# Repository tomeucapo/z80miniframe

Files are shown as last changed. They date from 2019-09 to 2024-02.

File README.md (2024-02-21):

# Z80MiniFrame
Core firmware source code and schematics from Z80MiniFrame hardware. This is a Z80 based microcomputer based system.

## Features

### Hardware 

* 32KBytes EEPROM for Firmware routines and Z80 MS-BASIC
* 32KBytes RAM
* VDP TMS9918
* PSG AY-3-8910
* USB-Serial Console Interface
 


### Software

* Extend BASIC instructions to support VDP capabilities like: COLOR, SCREEN or LOCATE instructions.
* Created RST $20 routine service to call firmware routines like VDP routines.

## Required tools
This project uses ZMAC Z80 Macro assembler and LD80 Linker from http://48k.ca/zmac.html. And finally needs make or nmake or Make to build project.

## Build software
```
nmake all
```

This produces firmware.hex into bin directory and this file can burn into 32KBytes EEPROM like AT28C256.

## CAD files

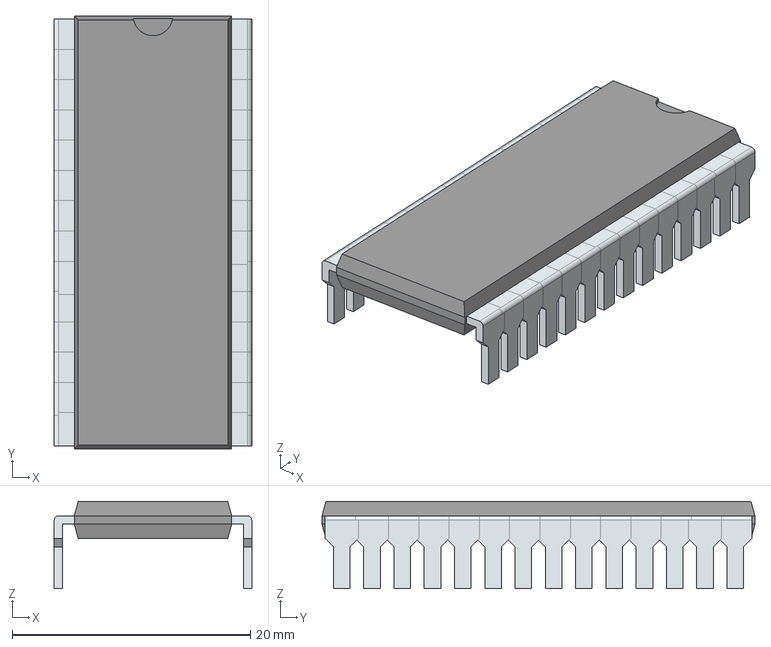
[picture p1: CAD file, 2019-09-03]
schematics/AS6C62256-55PCN/3D/AS6C62256-55PCN.stp
16.6 x 36.3 x 7.31 mm
PinsArrayLR

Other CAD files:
schematics/AS6C62256-55PCN/3D/AS6C62256-55PCN.stl
schematics/AS6C62256-55PCN/Allegro/dip1587w140p254l3632h381q28n.psm
schematics/AS6C62256-55PCN/DEHDL/as6c62256_55pcn/chips/chips.prt

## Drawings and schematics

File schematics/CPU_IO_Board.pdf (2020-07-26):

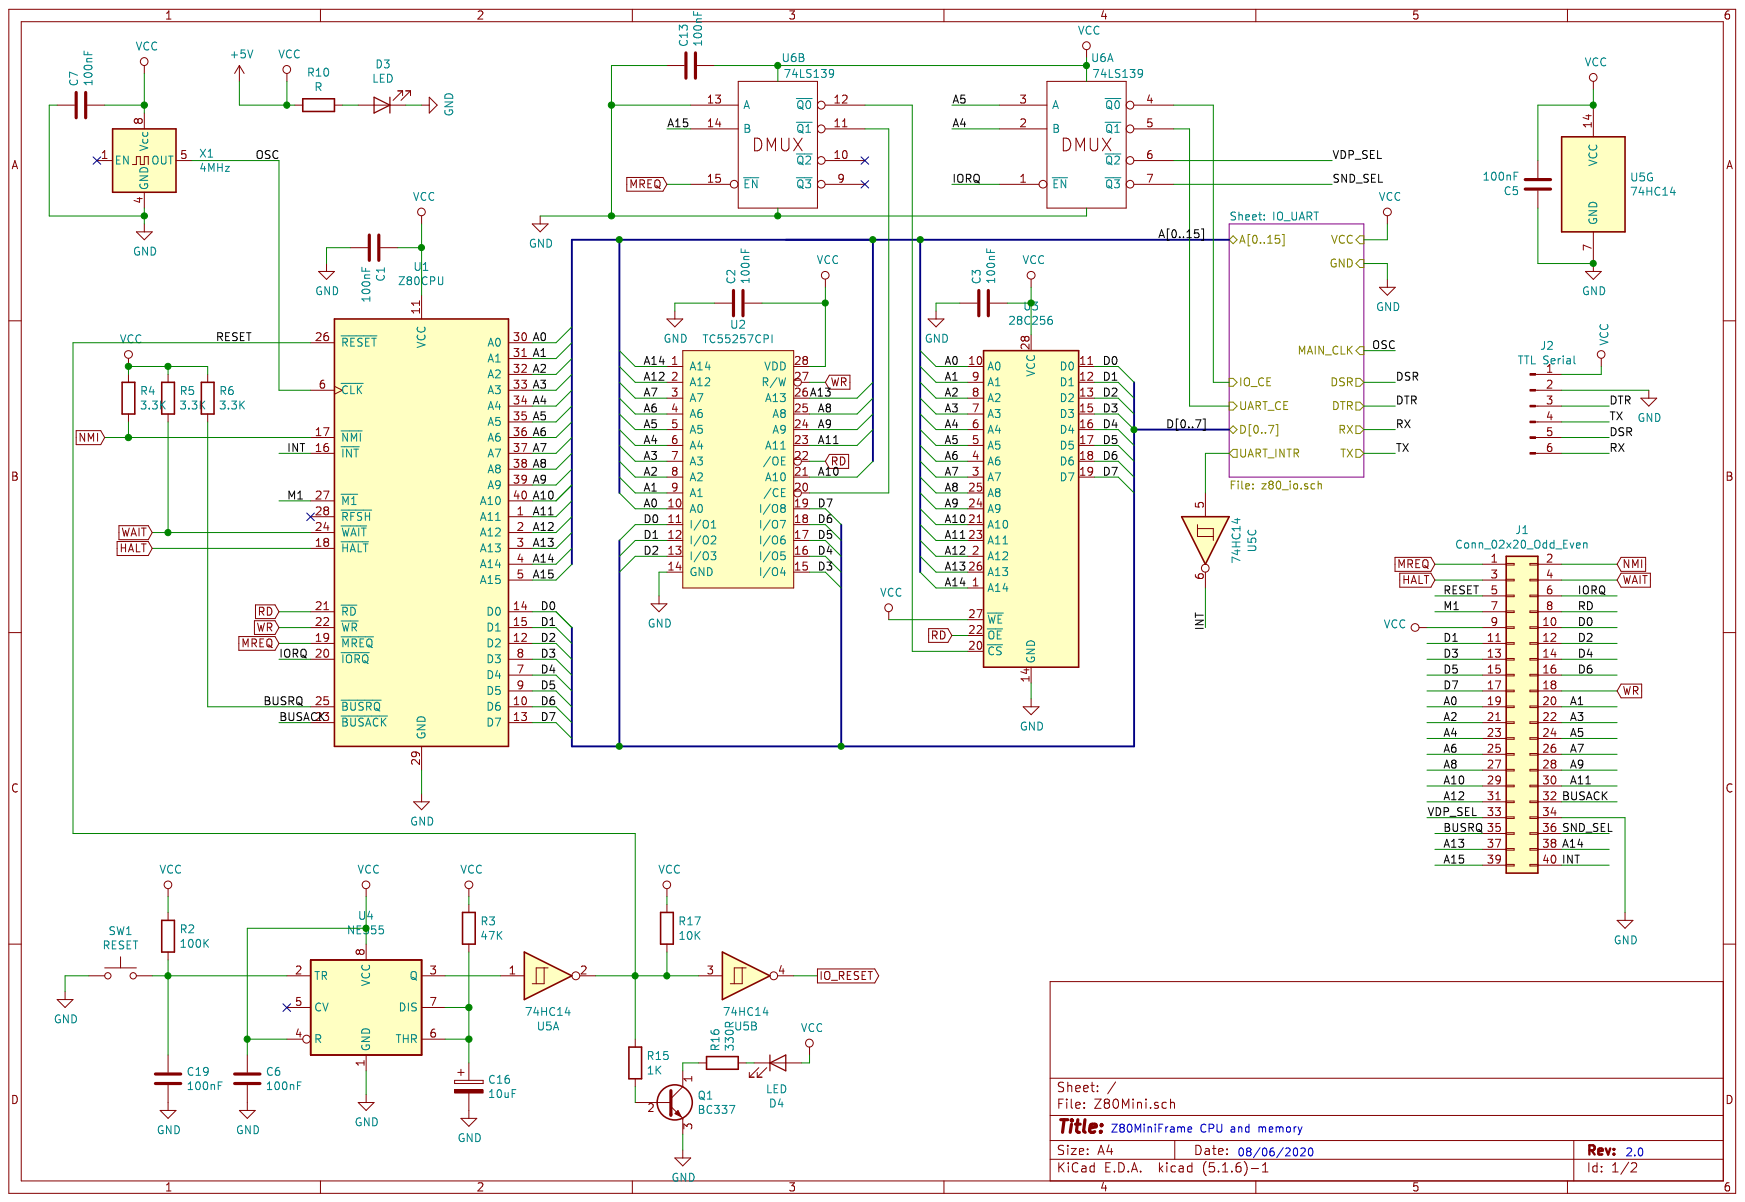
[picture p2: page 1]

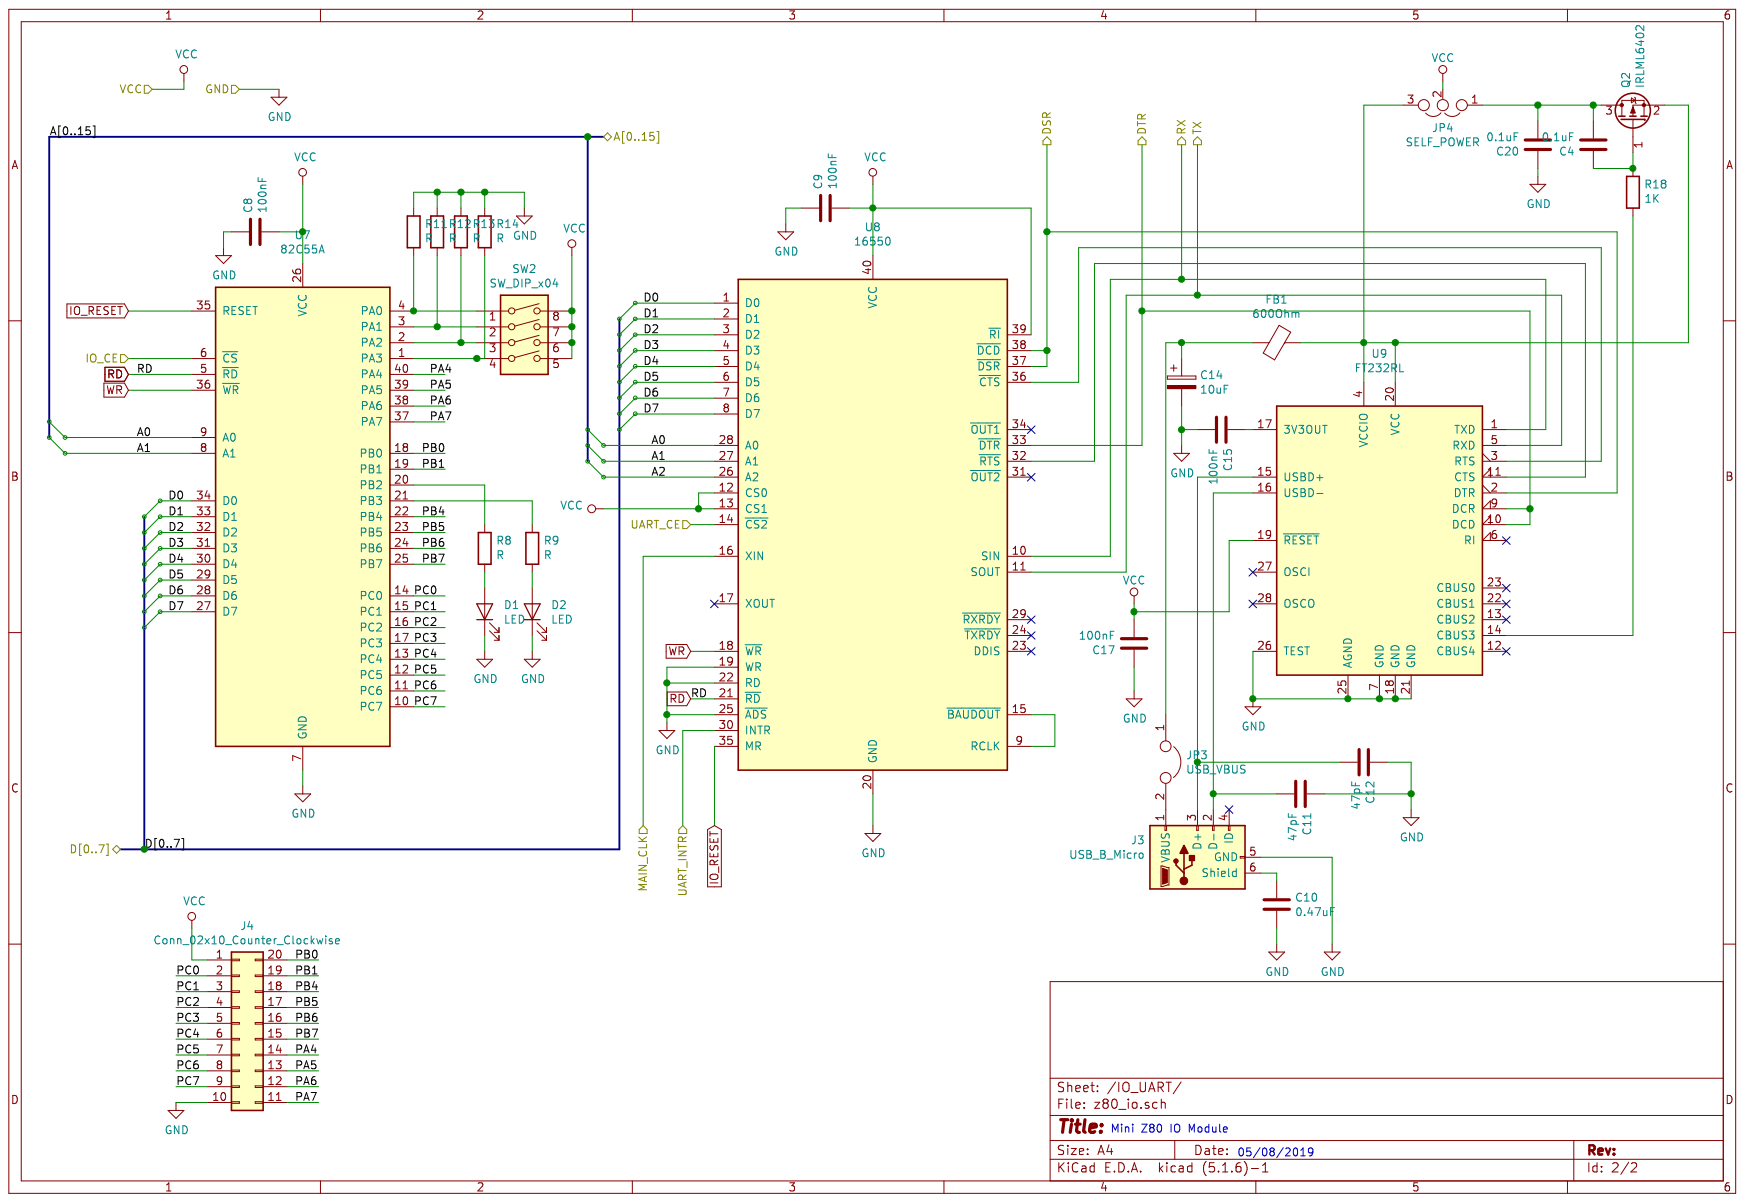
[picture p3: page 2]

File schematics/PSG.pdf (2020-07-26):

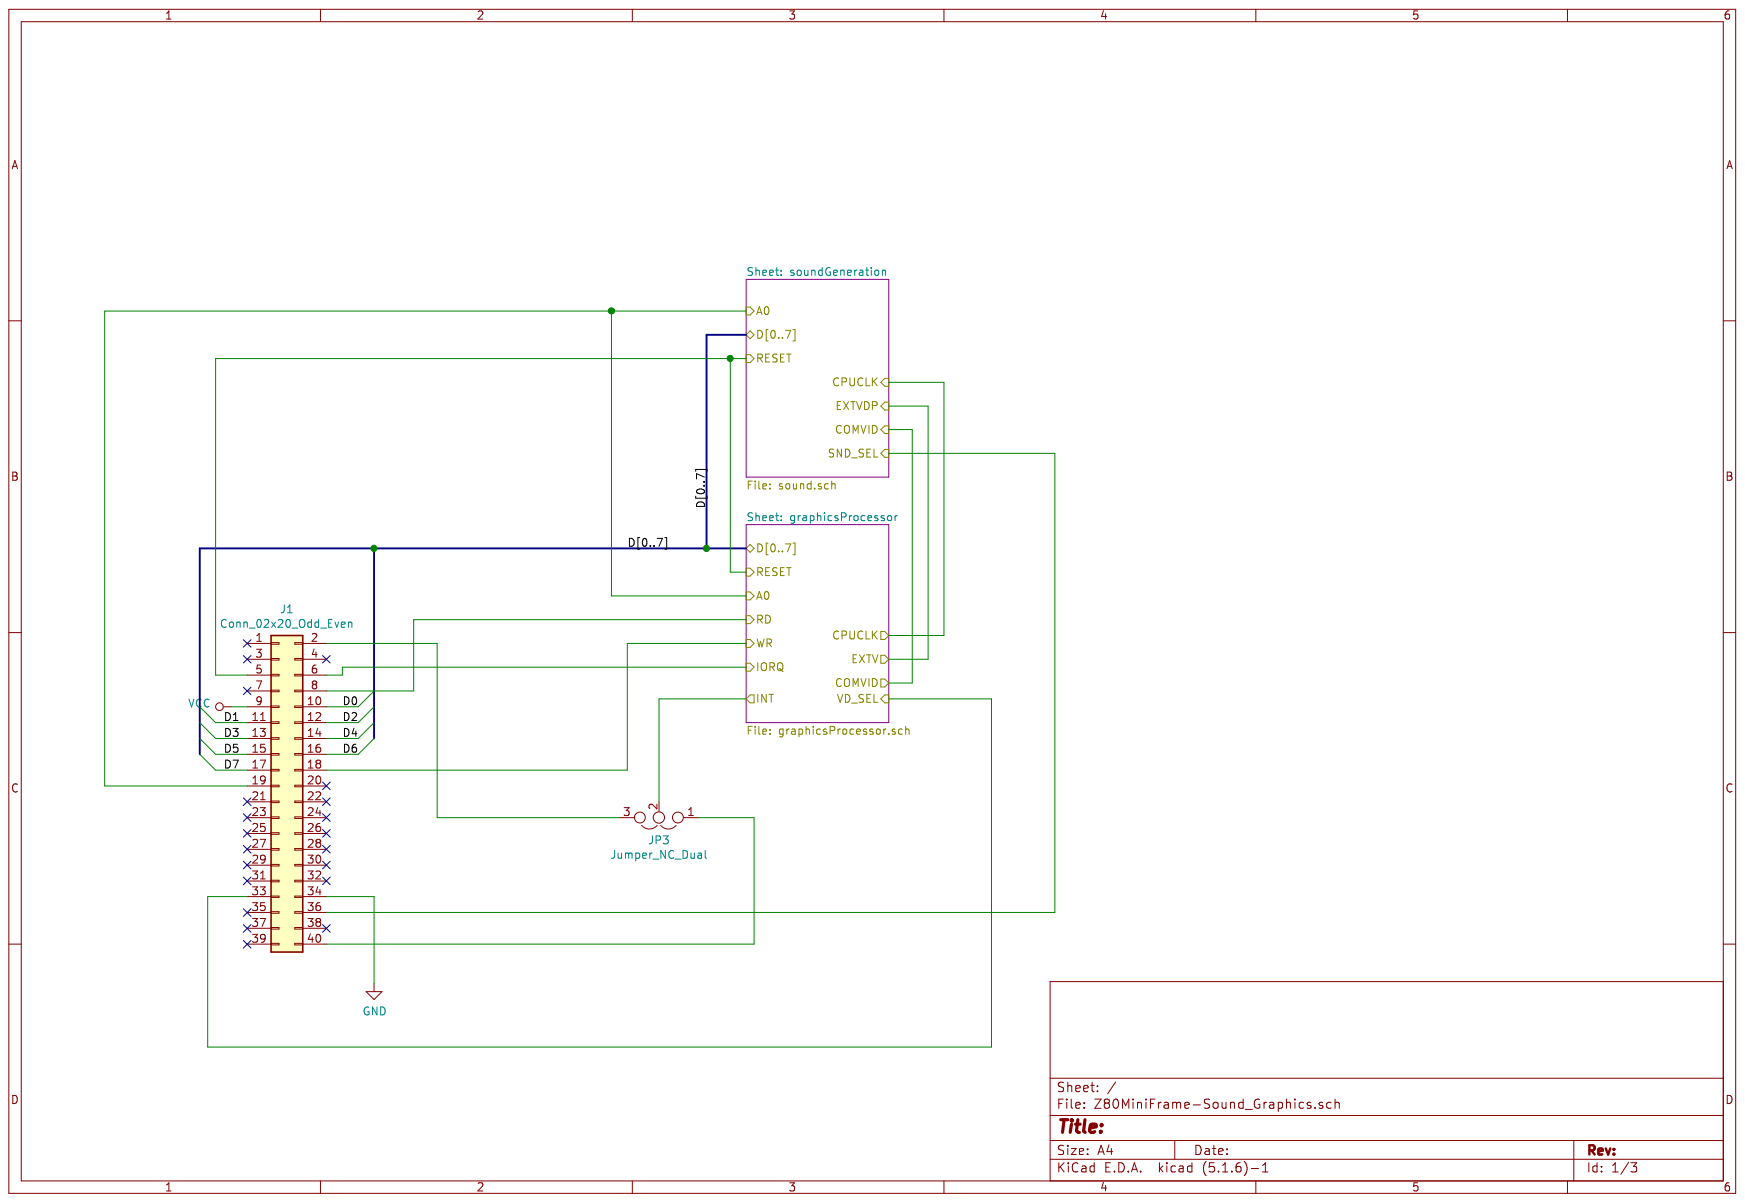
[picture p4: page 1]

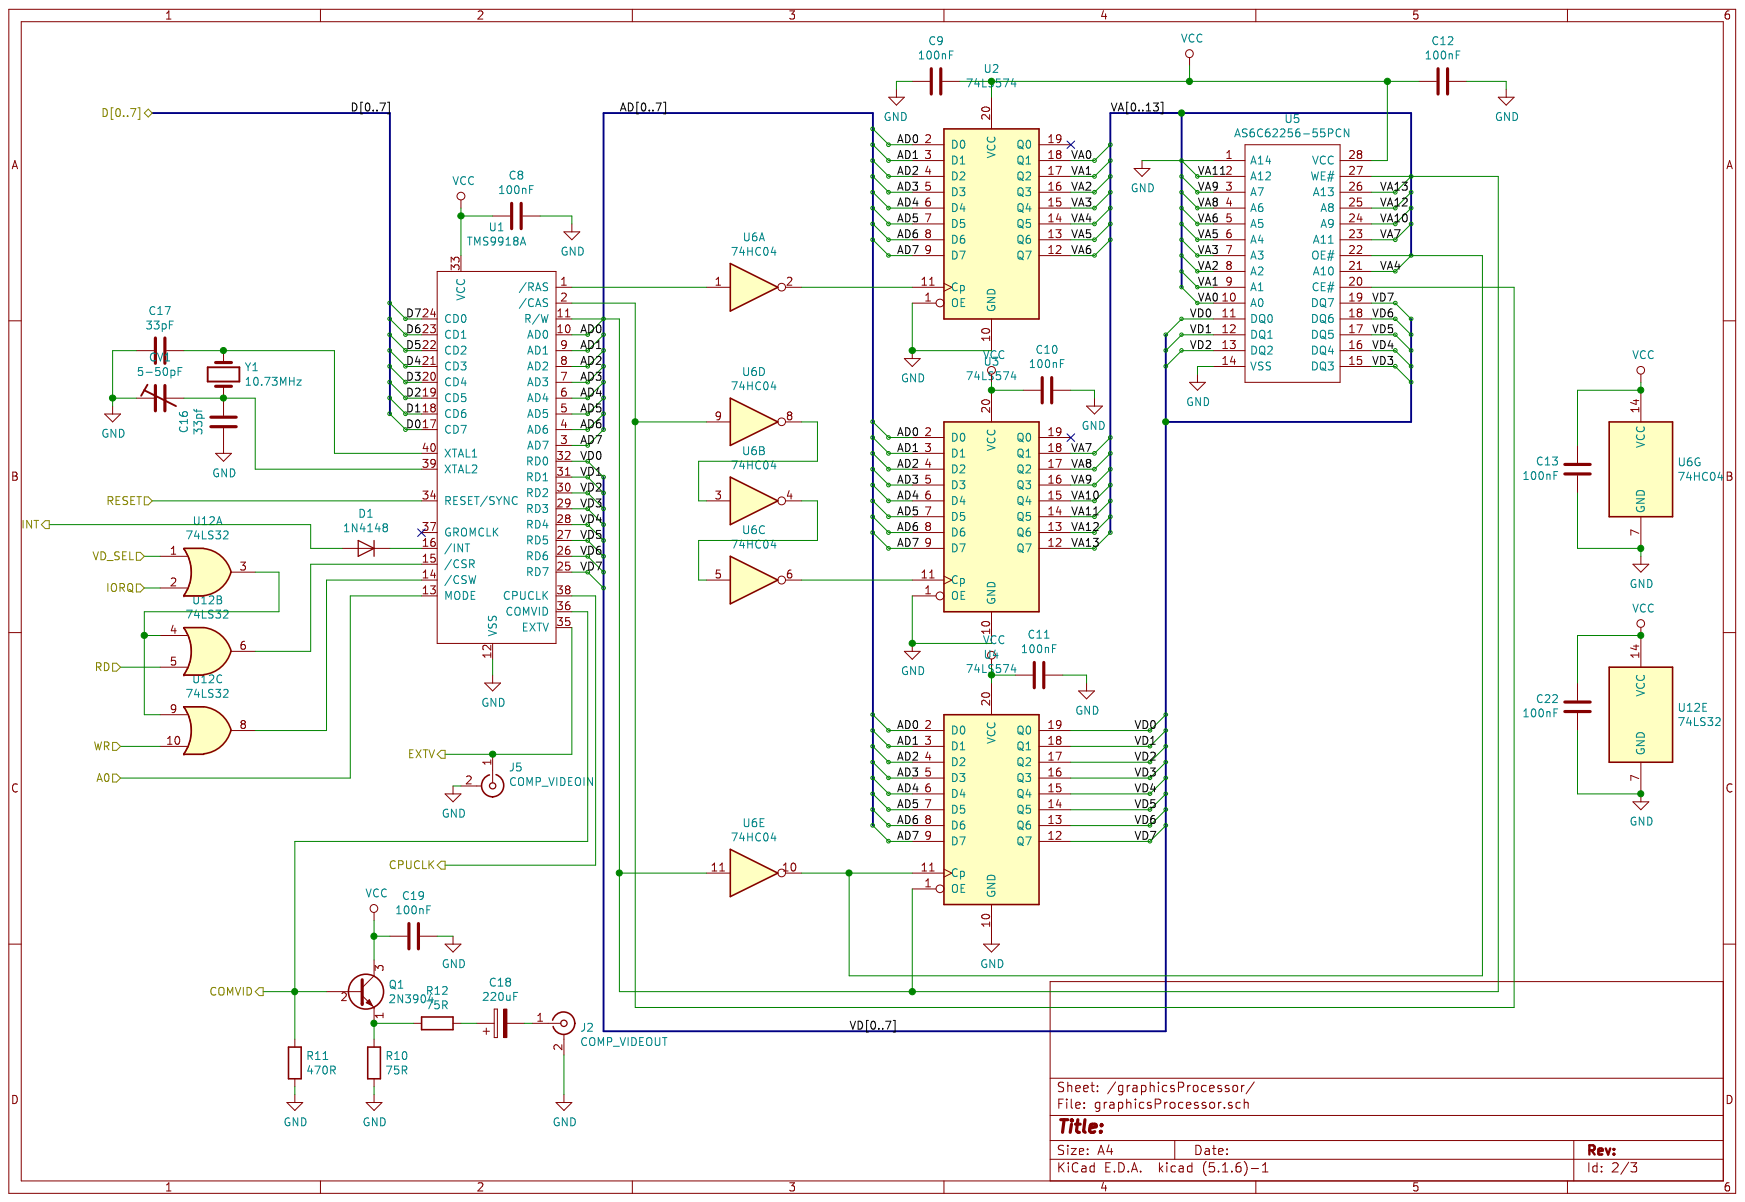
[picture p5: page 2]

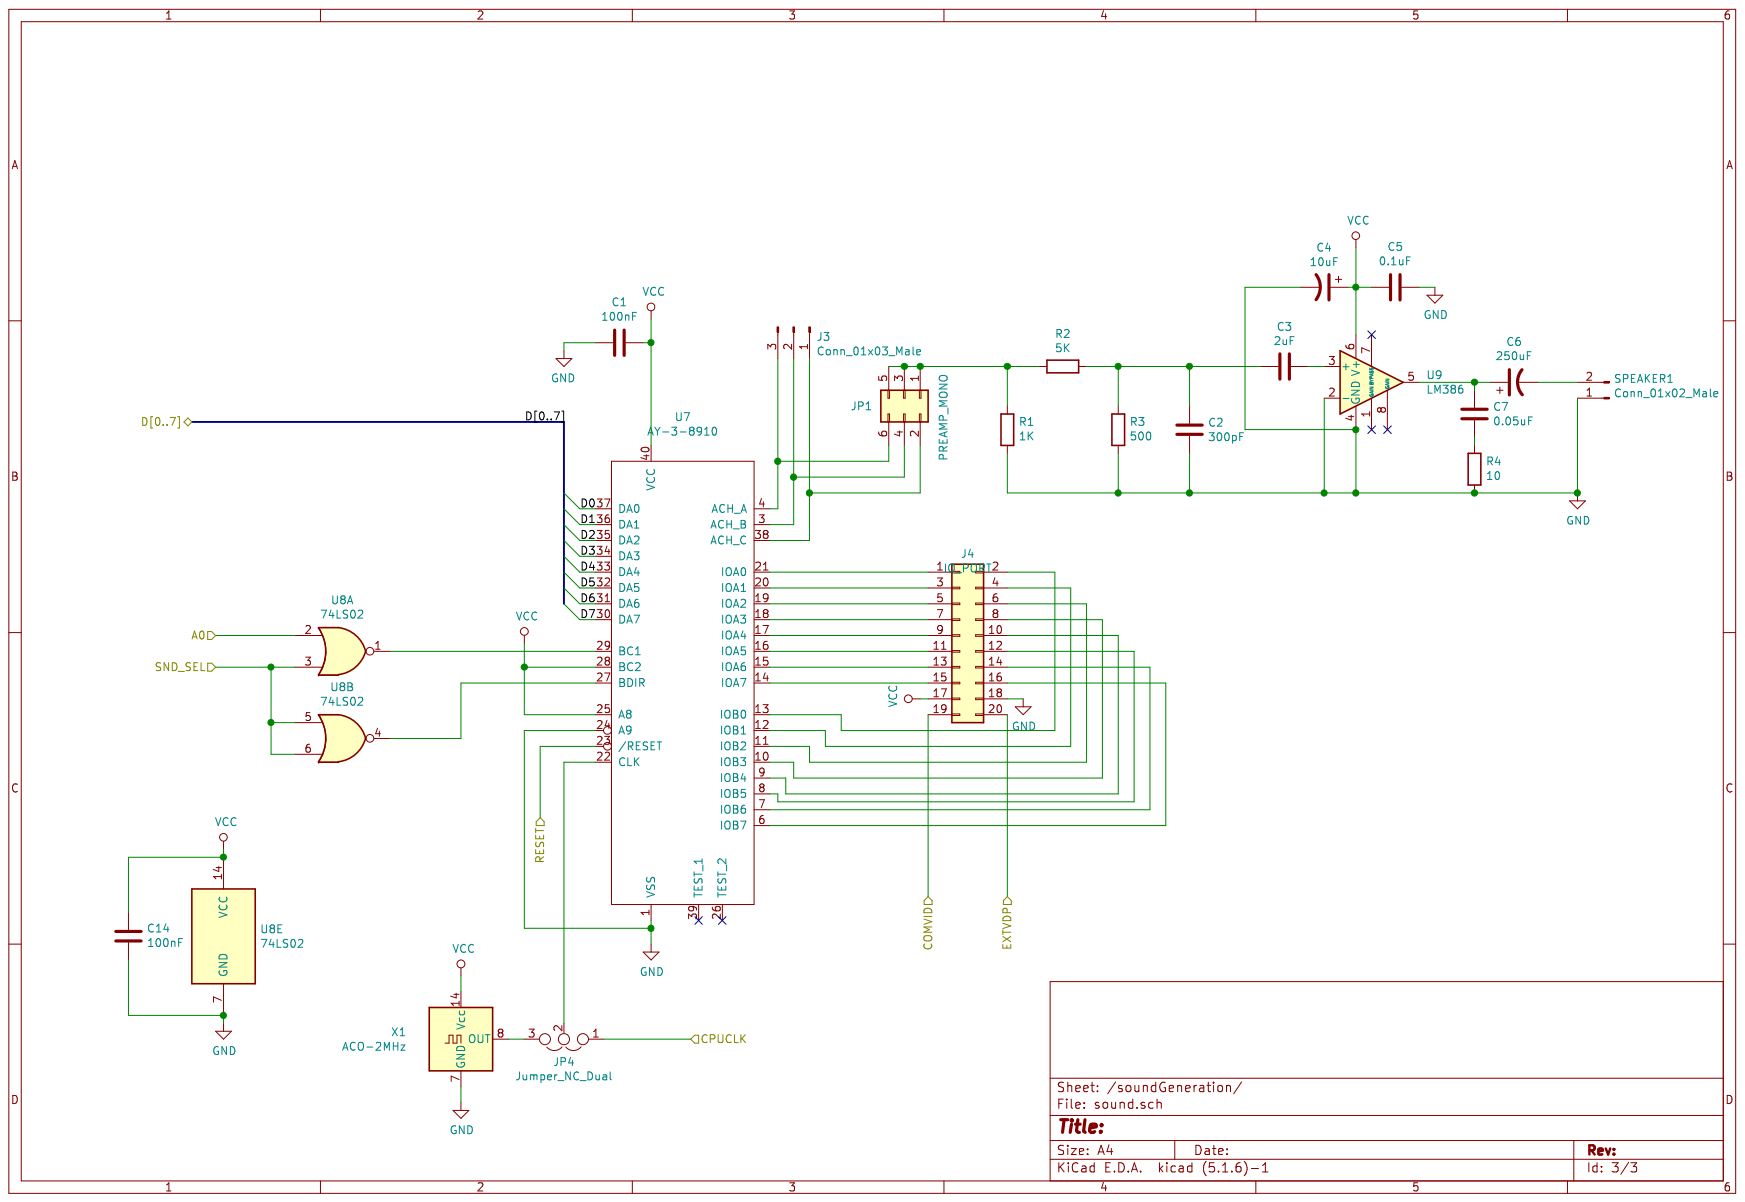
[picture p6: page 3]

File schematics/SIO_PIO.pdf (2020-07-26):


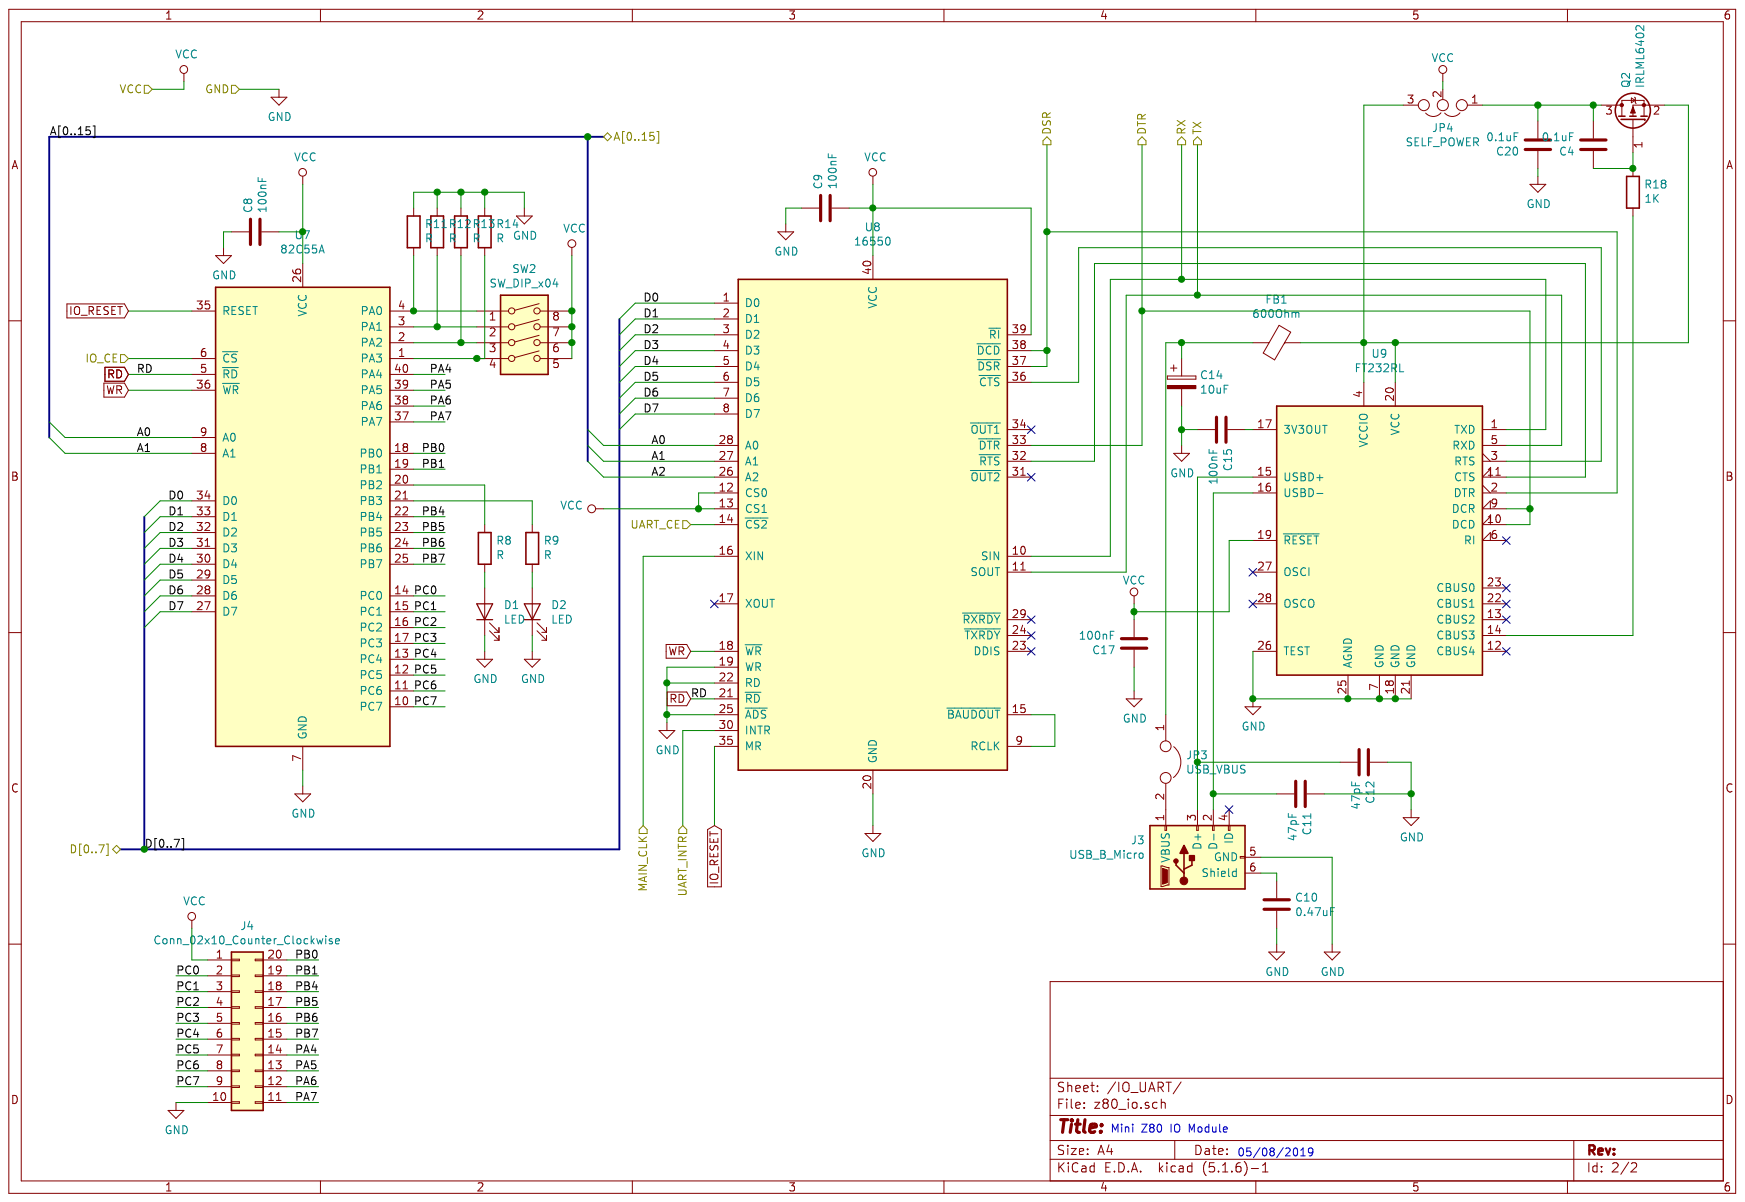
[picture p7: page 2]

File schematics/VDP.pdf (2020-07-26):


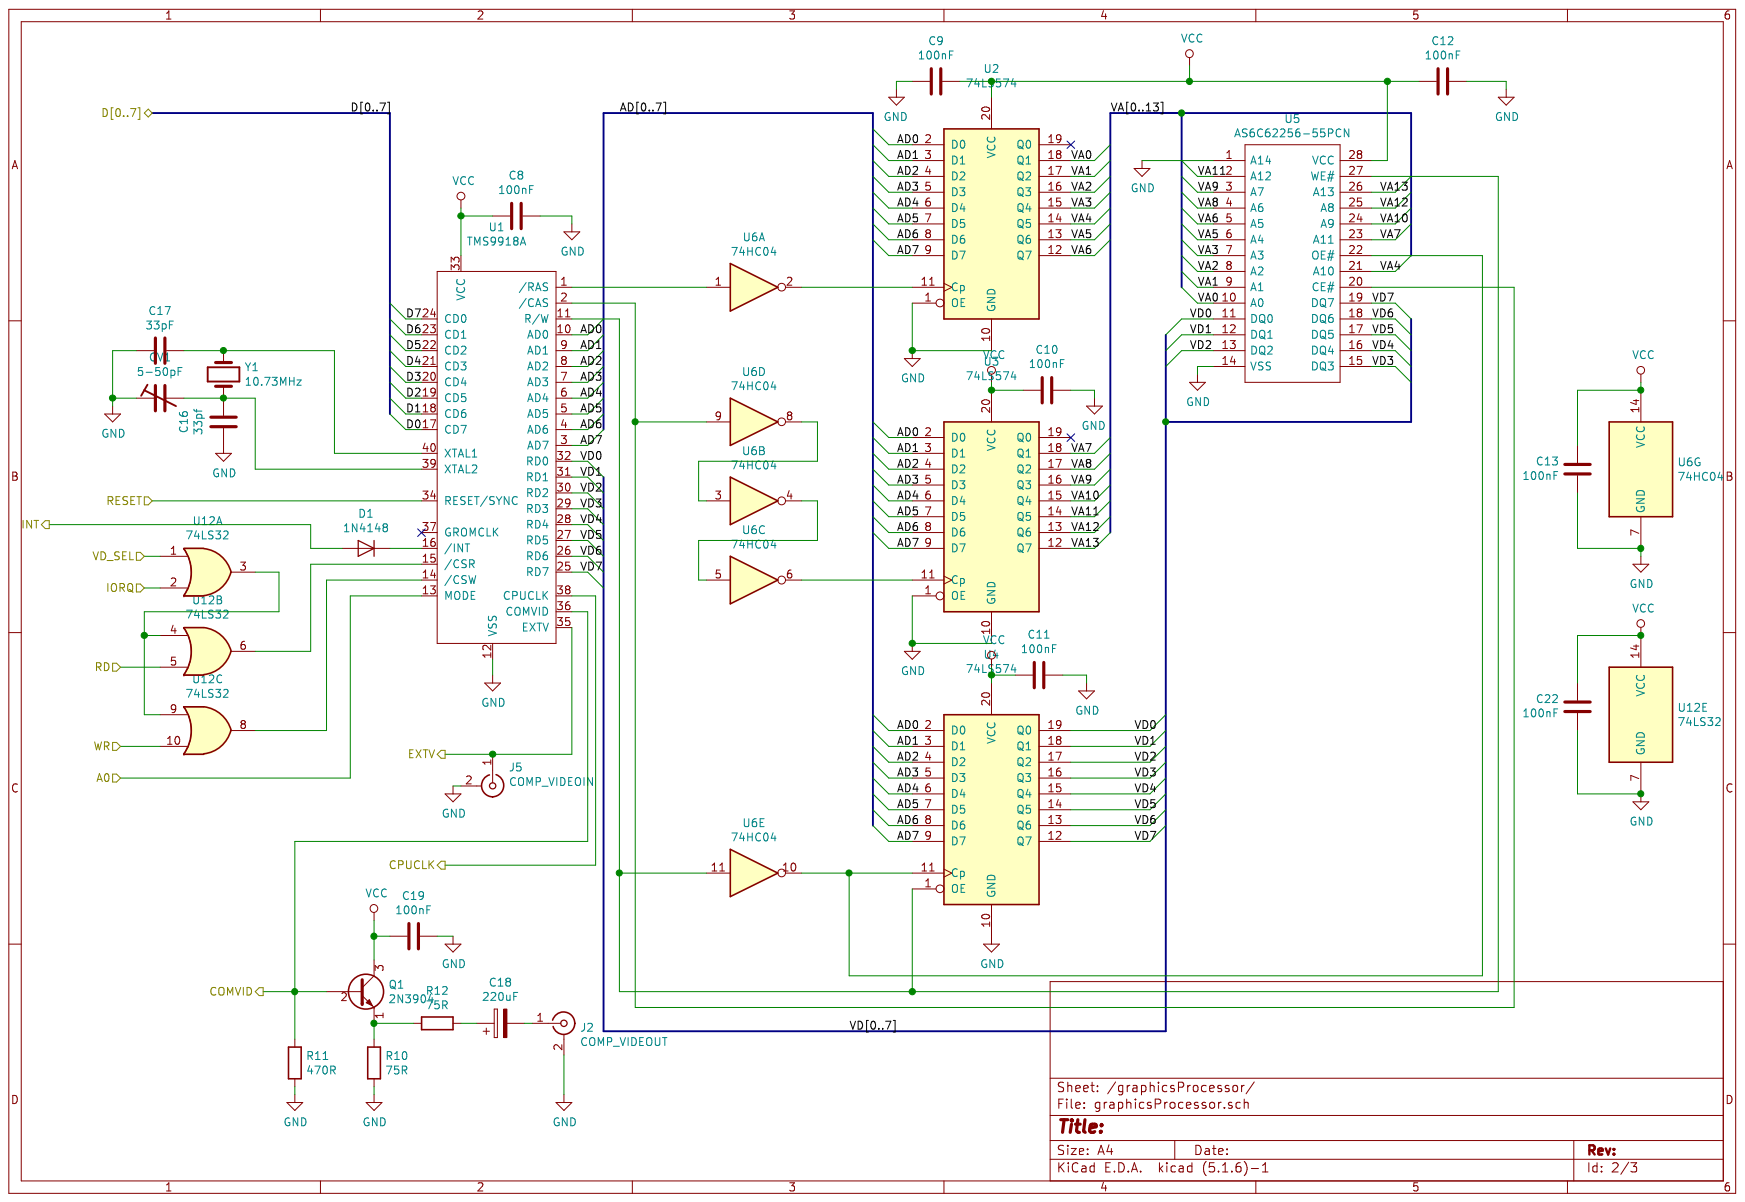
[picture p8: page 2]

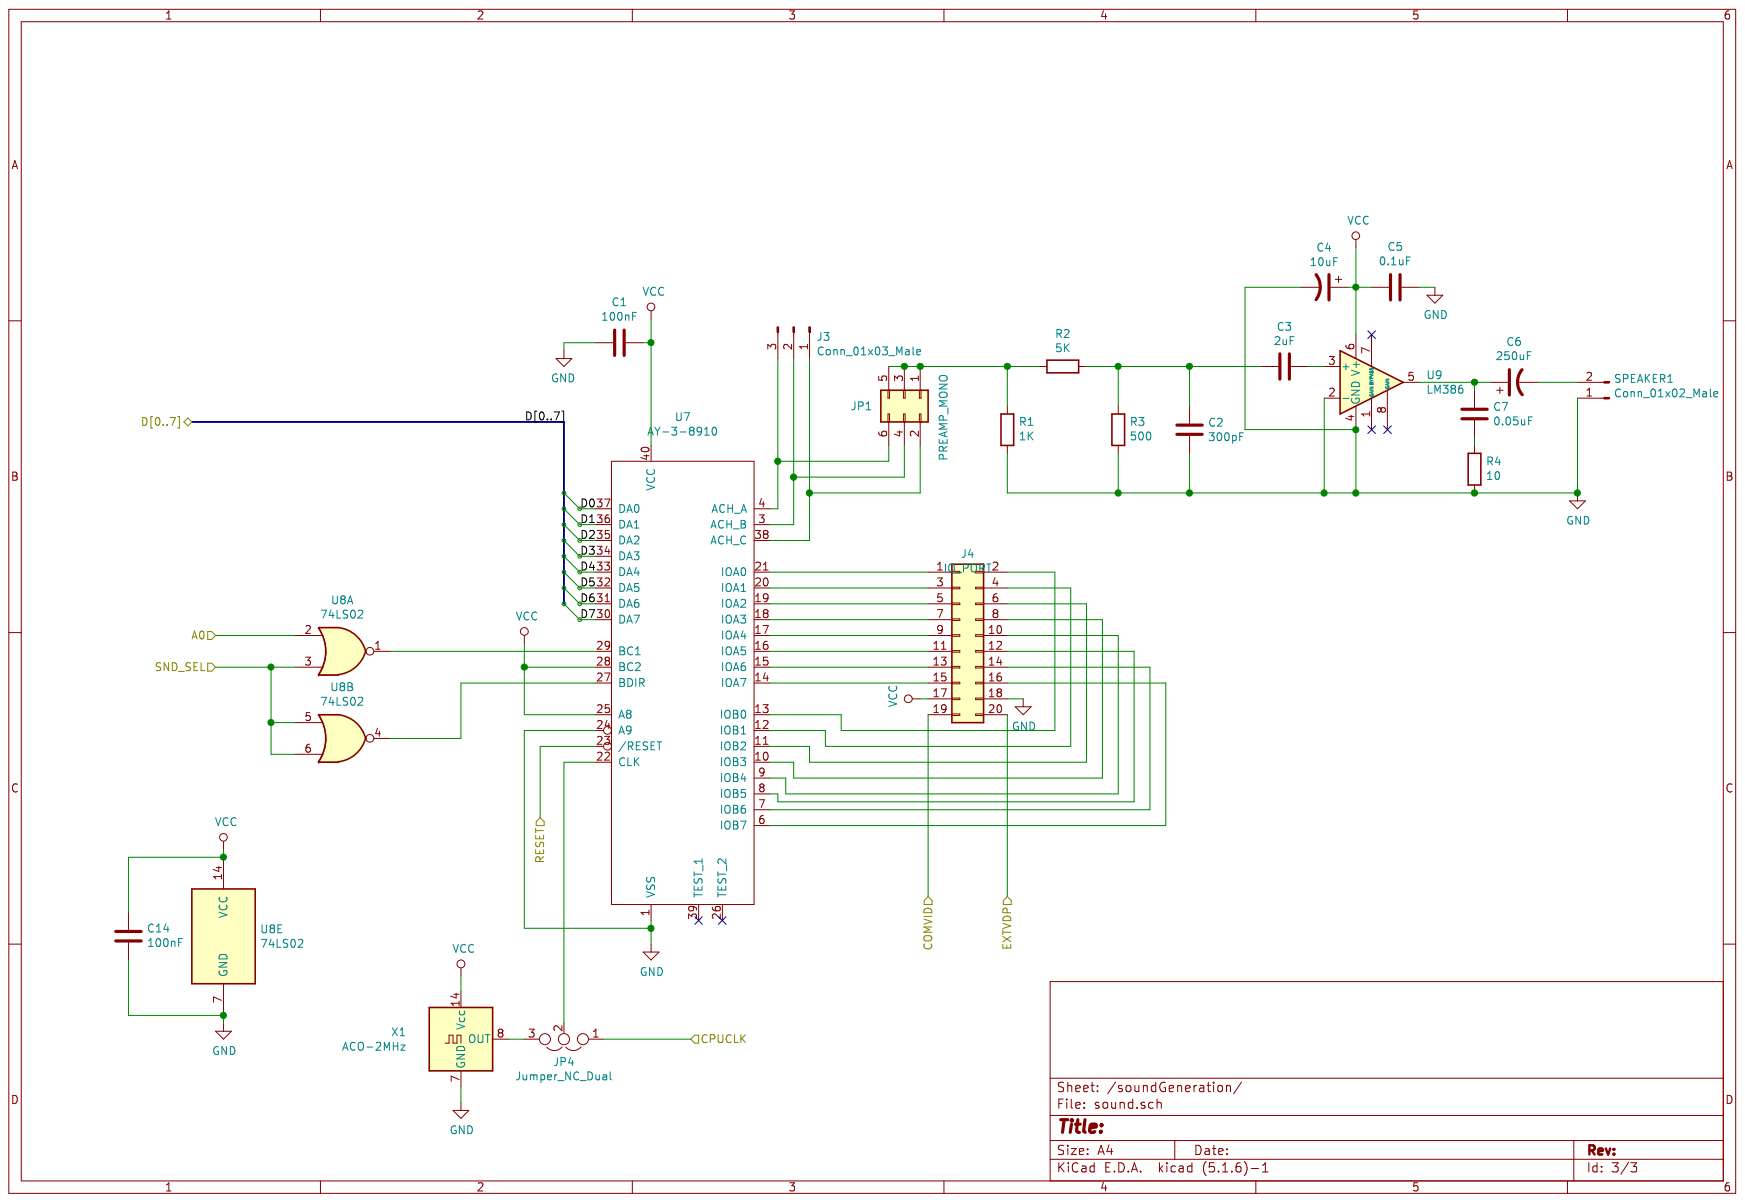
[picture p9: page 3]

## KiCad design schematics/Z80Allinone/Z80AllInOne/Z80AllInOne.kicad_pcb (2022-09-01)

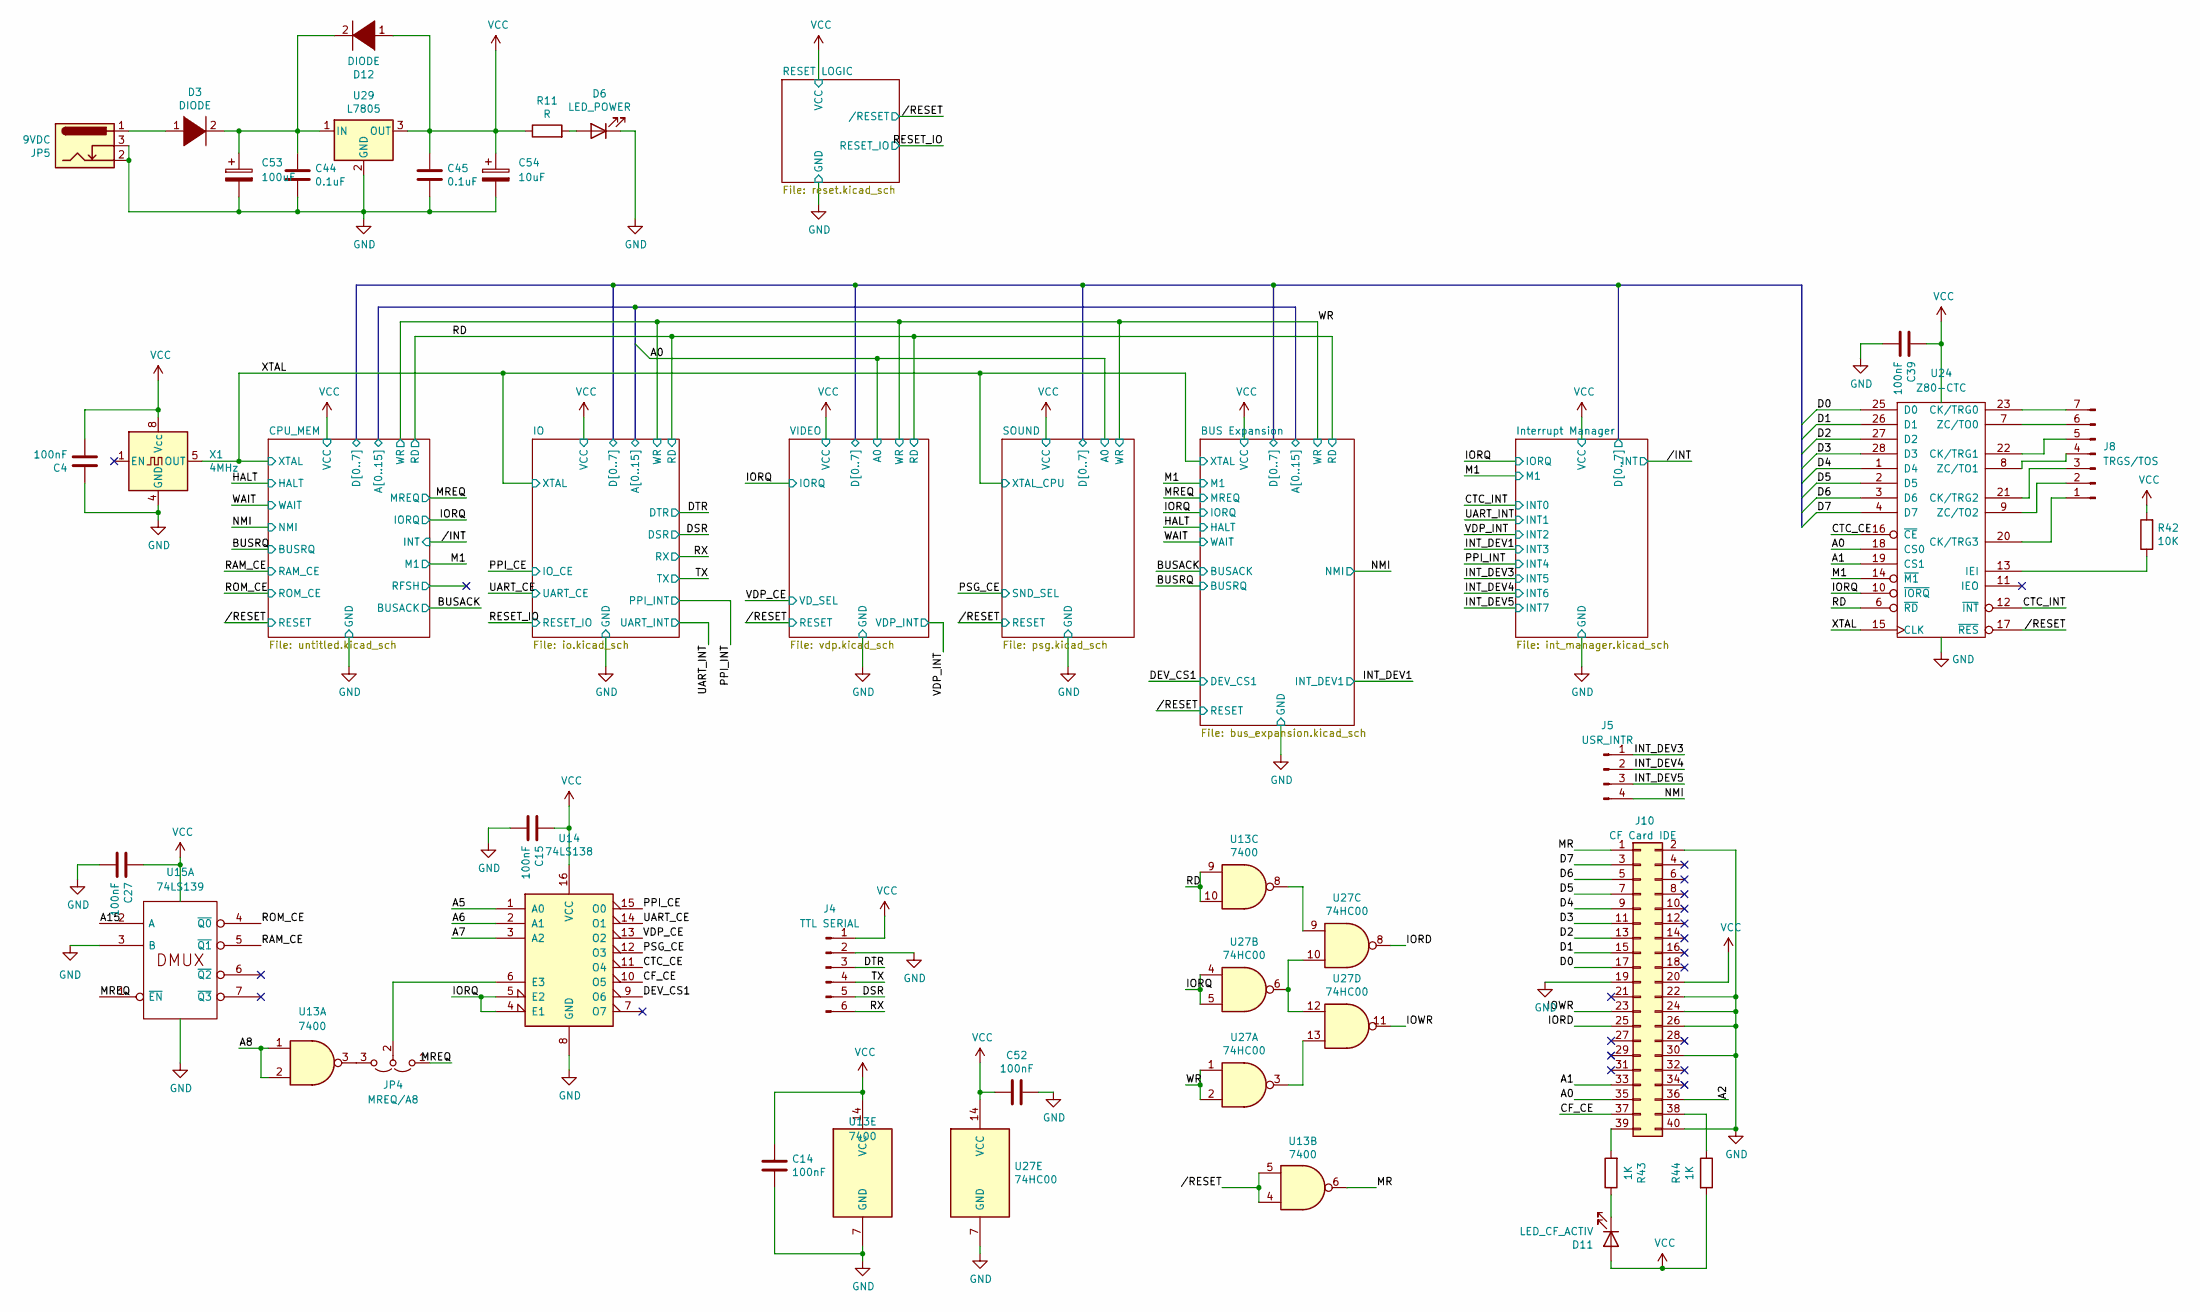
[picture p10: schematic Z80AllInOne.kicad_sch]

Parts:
C4, C14, C15, C27, C39, C52: 100nF; C_Disc_D7.0mm_W2.5mm_P5.00mm
C44, C45: 0.1uF; C_Radial_D6.3mm_H5.0mm_P2.50mm
C53: 100uF; CP_Radial_D8.0mm_P3.80mm
C54: 10uF; CP_Radial_D8.0mm_P3.80mm
D3, D12: DIODE; D_A-405_P7.62mm_Horizontal
D6: LED_POWER; LED_D3.0mm
D11: LED_CF_ACTIV; LED_D3.0mm
J4: TTL SERIAL; PinHeader_1x06_P2.54mm_Vertical
J5: USR_INTR; PinHeader_1x04_P2.54mm_Vertical
J8: TRGS/TOS; PinHeader_1x07_P2.54mm_Vertical
J10: CF Card IDE; IDC-Header_2x20_P2.54mm_Vertical
JP4: MREQ/A8; PinHeader_1x03_P2.54mm_Vertical
JP5: 9VDC; BarrelJack_Wuerth_6941xx301002
R11: R; R_Axial_DIN0207_L6.3mm_D2.5mm_P10.16mm_Horizontal
R42: 10K; R_Axial_DIN0207_L6.3mm_D2.5mm_P10.16mm_Horizontal
R43, R44: 1K; R_Axial_DIN0207_L6.3mm_D2.5mm_P10.16mm_Horizontal
U13: 7400; DIP-14_W7.62mm_LongPads
U14: 74LS138; DIP-16_W7.62mm_LongPads
U15: 74LS139; DIP-16_W7.62mm_Socket
U24: Z80-CTC; DIP-28_W15.24mm_LongPads
U27: 74HC00; DIP-14_W7.62mm
U29: L7805; TO-220-3_Horizontal_TabDown
X1: 4MHz; Oscillator_DIP-8

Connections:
/BUS Expansion/D0: J10.17, U24.25 (D0); also elsewhere on the board
/BUS Expansion/D1: J10.15, U24.26 (D1); also elsewhere on the board
/BUS Expansion/D2: J10.13, U24.27 (D2); also elsewhere on the board
/BUS Expansion/D3: J10.11, U24.28 (D3); also elsewhere on the board
/BUS Expansion/D4: J10.9, U24.1 (D4); also elsewhere on the board
/BUS Expansion/D5: J10.7, U24.2 (D5); also elsewhere on the board
/BUS Expansion/D6: J10.5, U24.3 (D6); also elsewhere on the board
/BUS Expansion/D7: J10.3, U24.4 (D7); also elsewhere on the board
/CF_CE: J10.37, U14.10 (O5)
/CTC_CE: U14.11 (O4), U24.16 (~CE)
/CTC_INT: U24.12 (~INT); also elsewhere on the board
/DEV_CS1: U14.9 (O6); also elsewhere on the board
/DSR: J4.5; also elsewhere on the board
/DTR: J4.3; also elsewhere on the board
/INT_DEV3: J5.1; also elsewhere on the board
/INT_DEV4: J5.2; also elsewhere on the board
/INT_DEV5: J5.3; also elsewhere on the board
/IO/A0: J10.35, U24.18 (CS0); also elsewhere on the board
/IO/A1: J10.33, U24.19 (CS1); also elsewhere on the board
/IO/A2: J10.36; also elsewhere on the board
/IO/A5: U14.1 (A0); also elsewhere on the board
/IO/A6: U14.2 (A1); also elsewhere on the board
/IO/A7: U14.3 (A2); also elsewhere on the board
/IO/A8: U13.1, U13.2; also elsewhere on the board
/IO/A15: U15.2 (A); also elsewhere on the board
/IORD: J10.25, U27.8
/IORQ: U14.4 (E1), U14.5 (E2), U24.10 (~IORQ), U27.4, U27.5; also elsewhere on the board
/IOWR: J10.23, U27.11
/M1: U24.14 (~M1); also elsewhere on the board
/MR: J10.1, U13.6
/MREQ: JP4.1 (A), U15.1 (~EN); also elsewhere on the board
/NMI: J5.4; also elsewhere on the board
/PPI_CE: U14.15 (O0); also elsewhere on the board
/PSG_CE: U14.12 (O3); also elsewhere on the board
/RAM_CE: U15.5 (~Q1); also elsewhere on the board
/RD: U13.9, U13.10, U24.6 (~RD); also elsewhere on the board
/ROM_CE: U15.4 (~Q0); also elsewhere on the board
/RX: J4.6; also elsewhere on the board
/TX: J4.4; also elsewhere on the board
/UART_CE: U14.14 (O1); also elsewhere on the board
/VDP_CE: U14.13 (O2); also elsewhere on the board
/WR: U27.1, U27.2; also elsewhere on the board
/XTAL: U24.15 (CLK), X1.5 (OUT); also elsewhere on the board
//RESET: U13.4, U13.5, U24.17 (~RES); also elsewhere on the board
GND: C4.1, C14.2, C15.2, C27.2, C39.2, C44.2, C45.2, C52.1, C53.2, C54.2, D6.1 (K), J4.2, J10.2, J10.19, J10.22, J10.24, J10.26, J10.30, J10.40, JP5.2, JP5.3, U13.7 (GND), U14.8 (GND), U15.3 (B), U15.8 (GND), U24.5 (GND), U27.7 (GND), U29.2 (GND), X1.4 (GND); also elsewhere on the board
unnamed: C44.1, C53.1, D3.2 (A), D12.2 (A), U29.1 (IN)
unnamed: D3.1 (K), JP5.1
unnamed: D6.2 (A), R11.2
unnamed: D11.1 (K), R43.1
unnamed: J8.1, U24.20 (CK/TRG3)
unnamed: J8.2, U24.9 (ZC/TO2)
unnamed: J8.3, U24.21 (CK/TRG2)
unnamed: J8.4, U24.8 (ZC/TO1)
unnamed: J8.5, U24.22 (CK/TRG1)
unnamed: J8.6, U24.7 (ZC/TO0)
unnamed: J8.7, U24.23 (CK/TRG0)
unnamed: J10.38, R44.1
unnamed: J10.39, R43.2
unnamed: JP4.2 (C), U14.6 (E3)
unnamed: JP4.3 (B), U13.3
unnamed: R42.1, U24.13 (IEI)
unnamed: U13.8, U27.9
unnamed: U27.6, U27.10, U27.12
unnamed: U27.3, U27.13
VCC: C4.2, C14.1, C15.1, C27.1, C39.1, C45.1, C52.2, C54.1, D11.2 (A), D12.1 (K), J4.1, J10.20, R11.1, R42.2, R44.2, U13.14 (VCC), U14.16 (VCC), U15.16 (VCC), U24.24 (VDD), U27.14 (VCC), U29.3 (OUT), X1.8 (Vcc); also elsewhere on the board

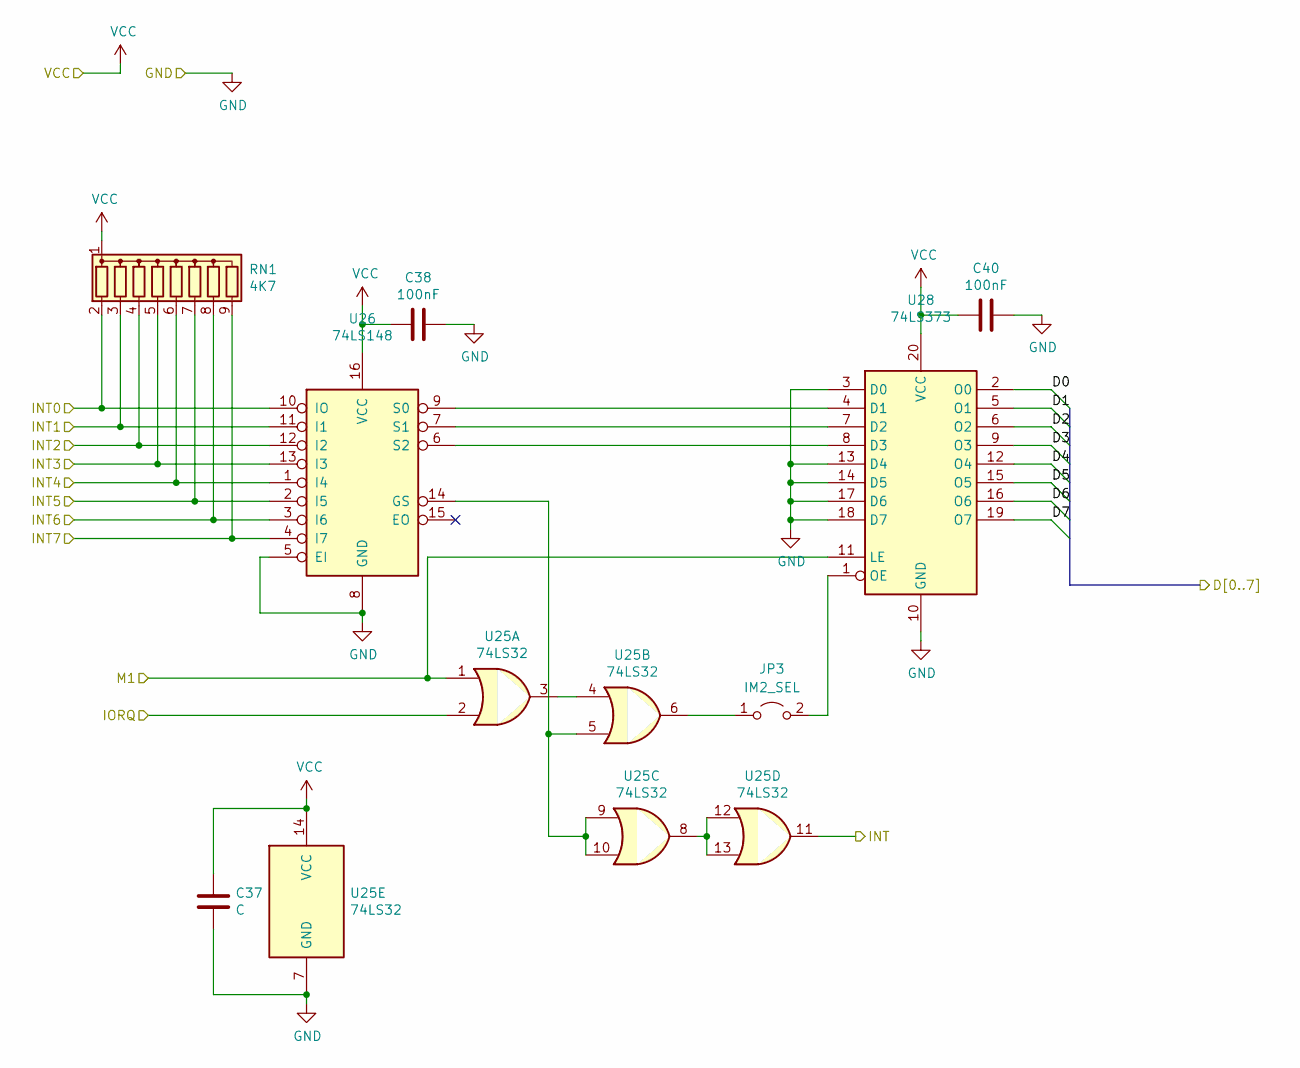
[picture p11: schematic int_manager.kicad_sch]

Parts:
C37: C; C_Disc_D7.0mm_W2.5mm_P5.00mm
C38, C40: 100nF; C_Disc_D7.0mm_W2.5mm_P5.00mm
JP3: IM2_SEL; PinHeader_1x02_P2.54mm_Vertical
RN1: 4K7; R_Array_SIP9
U25: 74LS32; DIP-14_W7.62mm_LongPads
U26: 74LS148; DIP-16_W7.62mm_LongPads
U28: 74LS373; DIP-20_W7.62mm_LongPads

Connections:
/BUS Expansion/D0: U28.2 (O0); also elsewhere on the board
/BUS Expansion/D1: U28.5 (O1); also elsewhere on the board
/BUS Expansion/D2: U28.6 (O2); also elsewhere on the board
/BUS Expansion/D3: U28.9 (O3); also elsewhere on the board
/BUS Expansion/D4: U28.12 (O4); also elsewhere on the board
/BUS Expansion/D5: U28.15 (O5); also elsewhere on the board
/BUS Expansion/D6: U28.16 (O6); also elsewhere on the board
/BUS Expansion/D7: U28.19 (O7); also elsewhere on the board
/CTC_INT: RN1.2 (R1), U26.10 (IO); also elsewhere on the board
/INT_DEV1: RN1.5 (R4), U26.13 (I3); also elsewhere on the board
/INT_DEV3: RN1.7 (R6), U26.2 (I5); also elsewhere on the board
/INT_DEV4: RN1.8 (R7), U26.3 (I6); also elsewhere on the board
/INT_DEV5: RN1.9 (R8), U26.4 (I7); also elsewhere on the board
/IORQ: U25.2; also elsewhere on the board
/M1: U25.1, U28.11 (LE); also elsewhere on the board
/PPI_INT: RN1.6 (R5), U26.1 (I4); also elsewhere on the board
/UART_INT: RN1.3 (R2), U26.11 (I1); also elsewhere on the board
/VDP_INT: RN1.4 (R3), U26.12 (I2); also elsewhere on the board
//INT: U25.11; also elsewhere on the board
GND: C37.1, C38.2, C40.2, U25.7 (GND), U26.5 (EI), U26.8 (GND), U28.3 (D0), U28.10 (GND), U28.13 (D4), U28.14 (D5), U28.17 (D6), U28.18 (D7); also elsewhere on the board
unnamed: JP3.1 (A), U25.6
unnamed: JP3.2 (B), U28.1 (OE)
unnamed: U25.3, U25.4
unnamed: U25.5, U25.9, U25.10, U26.14 (GS)
unnamed: U25.8, U25.12, U25.13
unnamed: U26.6 (S2), U28.8 (D3)
unnamed: U26.7 (S1), U28.7 (D2)
unnamed: U26.9 (S0), U28.4 (D1)
VCC: C37.2, C38.1, C40.1, RN1.1 (common), U25.14 (VCC), U26.16 (VCC), U28.20 (VCC); also elsewhere on the board

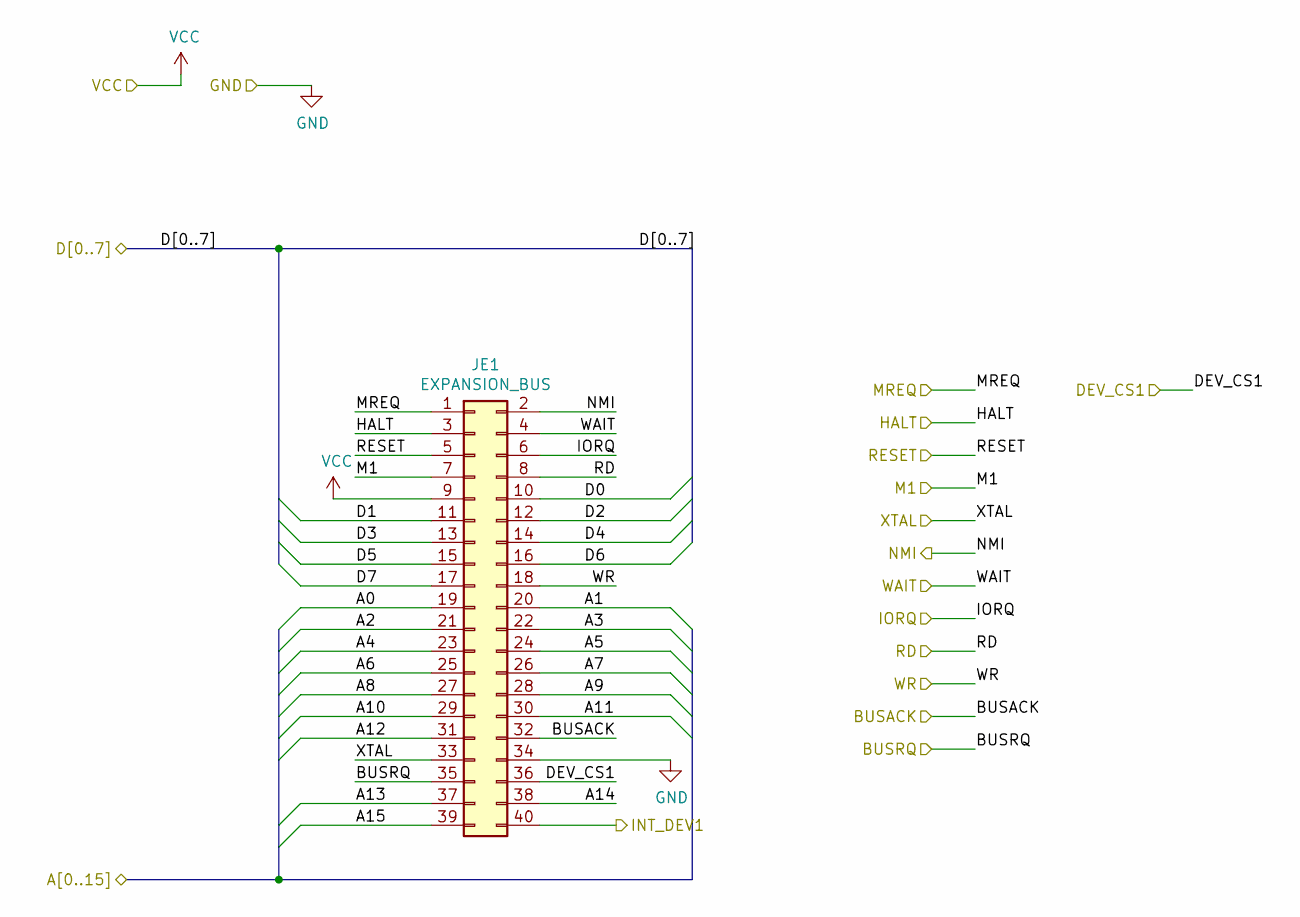
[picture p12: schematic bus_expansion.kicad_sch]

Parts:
JE1: EXPANSION_BUS; EdgeConector_40pin

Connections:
/BUS Expansion/D0: JE1.10; also elsewhere on the board
/BUS Expansion/D1: JE1.11; also elsewhere on the board
/BUS Expansion/D2: JE1.12; also elsewhere on the board
/BUS Expansion/D3: JE1.13; also elsewhere on the board
/BUS Expansion/D4: JE1.14; also elsewhere on the board
/BUS Expansion/D5: JE1.15; also elsewhere on the board
/BUS Expansion/D6: JE1.16; also elsewhere on the board
/BUS Expansion/D7: JE1.17; also elsewhere on the board
/BUSACK: JE1.32; also elsewhere on the board
/BUSRQ: JE1.35; also elsewhere on the board
/DEV_CS1: JE1.36; also elsewhere on the board
/HALT: JE1.3; also elsewhere on the board
/INT_DEV1: JE1.40; also elsewhere on the board
/IO/A0: JE1.19; also elsewhere on the board
/IO/A1: JE1.20; also elsewhere on the board
/IO/A2: JE1.21; also elsewhere on the board
/IO/A3: JE1.22; also elsewhere on the board
/IO/A4: JE1.23; also elsewhere on the board
/IO/A5: JE1.24; also elsewhere on the board
/IO/A6: JE1.25; also elsewhere on the board
/IO/A7: JE1.26; also elsewhere on the board
/IO/A8: JE1.27; also elsewhere on the board
/IO/A9: JE1.28; also elsewhere on the board
/IO/A10: JE1.29; also elsewhere on the board
/IO/A11: JE1.30; also elsewhere on the board
/IO/A12: JE1.31; also elsewhere on the board
/IO/A13: JE1.37; also elsewhere on the board
/IO/A14: JE1.38; also elsewhere on the board
/IO/A15: JE1.39; also elsewhere on the board
/IORQ: JE1.6; also elsewhere on the board
/M1: JE1.7; also elsewhere on the board
/MREQ: JE1.1; also elsewhere on the board
/NMI: JE1.2; also elsewhere on the board
/RD: JE1.8; also elsewhere on the board
/WAIT: JE1.4; also elsewhere on the board
/WR: JE1.18; also elsewhere on the board
/XTAL: JE1.33; also elsewhere on the board
//RESET: JE1.5; also elsewhere on the board
GND: JE1.34; also elsewhere on the board
VCC: JE1.9; also elsewhere on the board

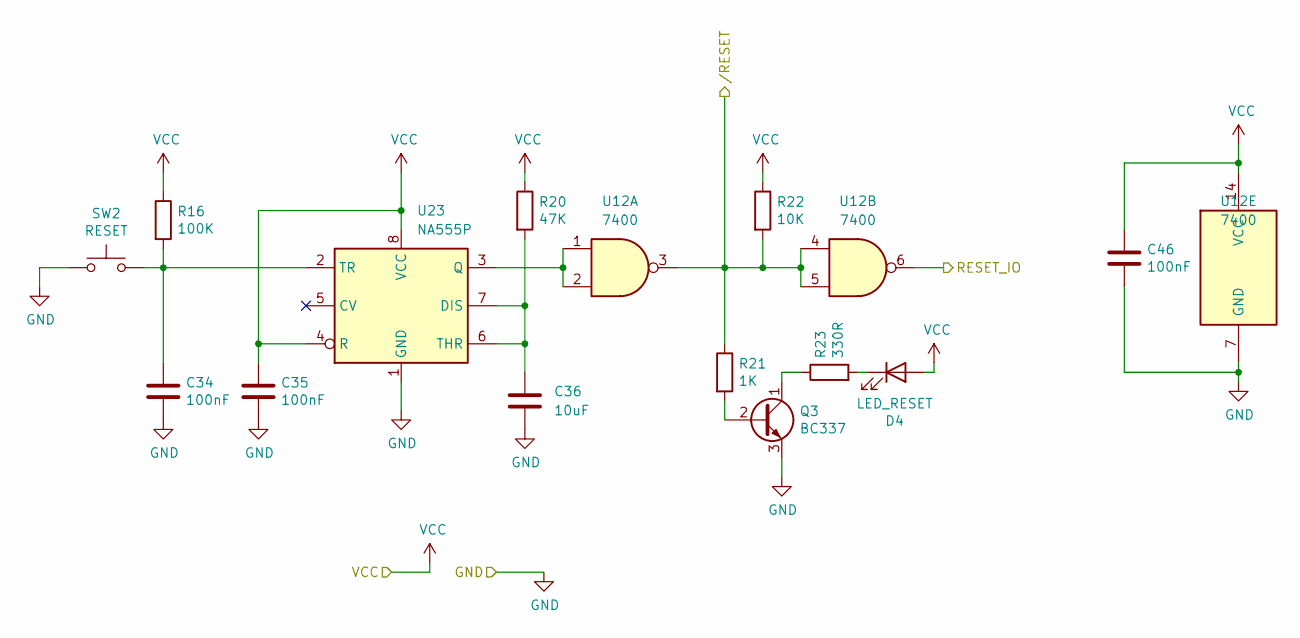
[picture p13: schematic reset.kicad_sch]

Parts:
C34, C35, C46: 100nF; C_Disc_D7.0mm_W2.5mm_P5.00mm
C36: 10uF; CP_Radial_D5.0mm_P2.50mm
D4: LED_RESET; LED_D3.0mm
Q3: BC337; TO-92_Inline
R16: 100K; R_Axial_DIN0207_L6.3mm_D2.5mm_P7.62mm_Horizontal
R20: 47K; R_Axial_DIN0207_L6.3mm_D2.5mm_P7.62mm_Horizontal
R21: 1K; R_Axial_DIN0207_L6.3mm_D2.5mm_P7.62mm_Horizontal
R22: 10K; R_Axial_DIN0207_L6.3mm_D2.5mm_P7.62mm_Horizontal
R23: 330R; R_Axial_DIN0207_L6.3mm_D2.5mm_P7.62mm_Horizontal
SW2: RESET; SW_PUSH_6mm_H5mm
U12: 7400; DIP-14_W7.62mm_LongPads
U23: NA555P; DIP-8_W7.62mm

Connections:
/RESET_IO: U12.6; also elsewhere on the board
//RESET: R21.1, R22.2, U12.3, U12.4, U12.5; also elsewhere on the board
GND: C34.2, C35.2, C36.2, C46.2, Q3.3 (E), SW2.1, U12.7 (GND), U23.1 (GND); also elsewhere on the board
unnamed: C34.1, R16.2, SW2.2, U23.2 (TR)
unnamed: C36.1, R20.2, U23.6 (THR), U23.7 (DIS)
unnamed: D4.1 (K), R23.2
unnamed: Q3.1 (C), R23.1
unnamed: Q3.2 (B), R21.2
unnamed: U12.1, U12.2, U23.3 (Q)
VCC: C35.1, C46.1, D4.2 (A), R16.1, R20.1, R22.1, U12.14 (VCC), U23.4 (R), U23.8 (VCC); also elsewhere on the board

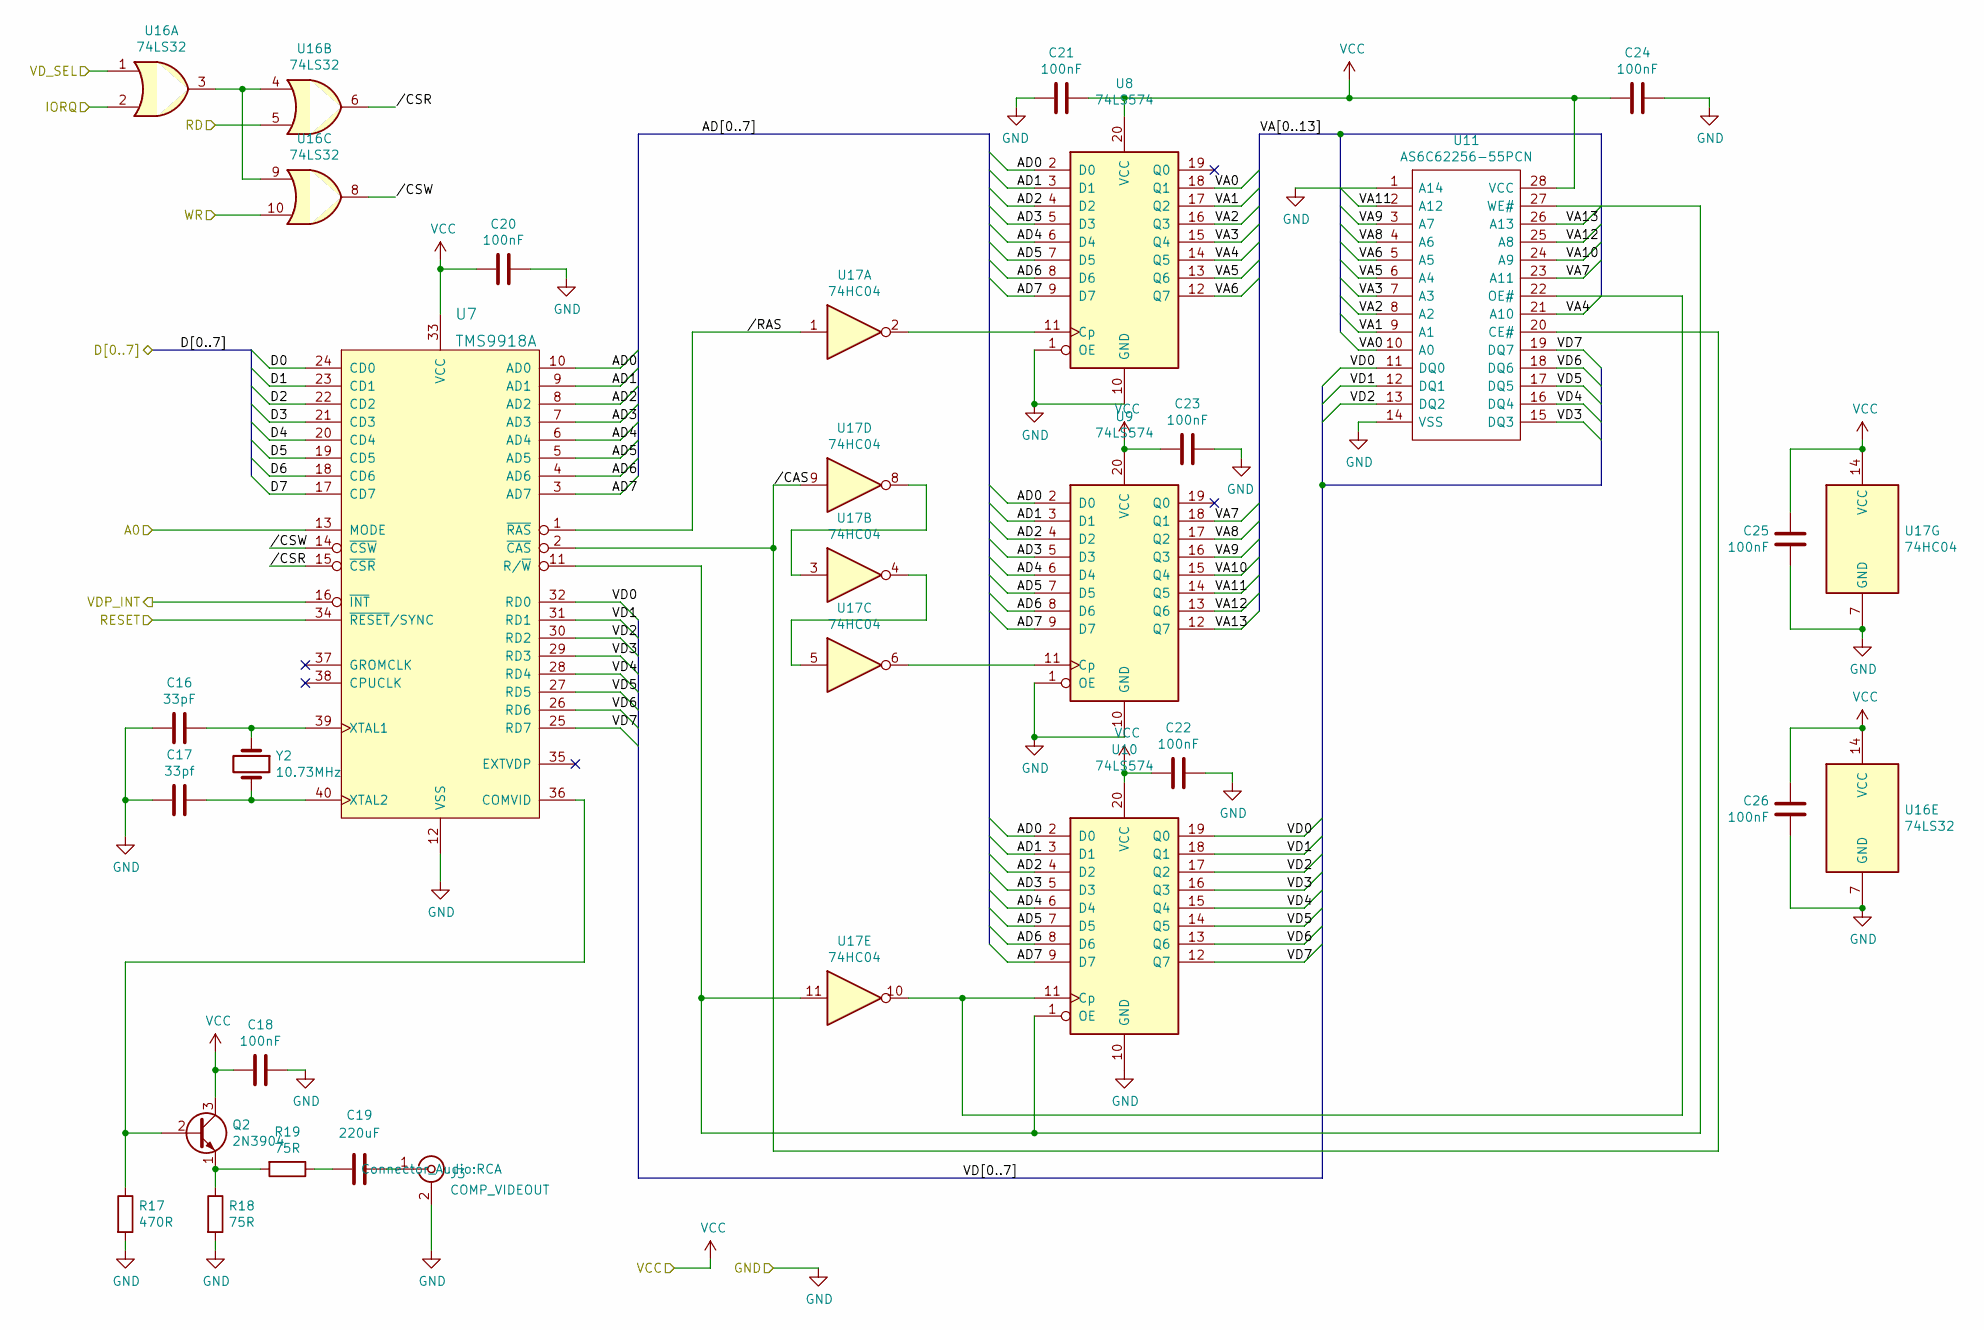
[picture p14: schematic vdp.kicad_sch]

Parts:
C16: 33pF; C_Disc_D7.0mm_W2.5mm_P5.00mm
C17: 33pf; C_Disc_D7.0mm_W2.5mm_P5.00mm
C18, C20, C21, C22, C23, C24, C25, C26: 100nF; C_Disc_D7.0mm_W2.5mm_P5.00mm
C19: 220uF; CP_Radial_Tantal_D6.0mm_P2.50mm
J3: COMP_VIDEOUT; RCA
Q2: 2N3904; TO-92_Inline
R17: 470R; R_Axial_DIN0207_L6.3mm_D2.5mm_P10.16mm_Horizontal
R18, R19: 75R; R_Axial_DIN0207_L6.3mm_D2.5mm_P10.16mm_Horizontal
U7: TMS9918A; DIP-40_W15.24mm_LongPads
U8, U9, U10: 74LS574; DIP-20_W7.62mm_Socket_LongPads
U11: AS6C62256-55PCN; DIP-28_W15.24mm_LongPads; Manufacturer_Part_Number AS6C62256-55PCN; Mouser Part Number 913-AS6C62256-55PCN
U16: 74LS32; DIP-14_W7.62mm_LongPads
U17: 74HC04; DIP-14_W7.62mm_Socket_LongPads
Y2: 10.73MHz; Crystal_HC18-U_Vertical

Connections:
/BUS Expansion/D0: U7.24 (CD0); also elsewhere on the board
/BUS Expansion/D1: U7.23 (CD1); also elsewhere on the board
/BUS Expansion/D2: U7.22 (CD2); also elsewhere on the board
/BUS Expansion/D3: U7.21 (CD3); also elsewhere on the board
/BUS Expansion/D4: U7.20 (CD4); also elsewhere on the board
/BUS Expansion/D5: U7.19 (CD5); also elsewhere on the board
/BUS Expansion/D6: U7.18 (CD6); also elsewhere on the board
/BUS Expansion/D7: U7.17 (CD7); also elsewhere on the board
/IO/A0: U7.13 (MODE); also elsewhere on the board
/IORQ: U16.2; also elsewhere on the board
/RD: U16.5; also elsewhere on the board
/VDP_CE: U16.1; also elsewhere on the board
/VDP_INT: U7.16 (~INT); also elsewhere on the board
/VIDEO/AD0: U7.10 (AD0), U8.2 (D0), U9.2 (D0), U10.2 (D0)
/VIDEO/AD1: U7.9 (AD1), U8.3 (D1), U9.3 (D1), U10.3 (D1)
/VIDEO/AD2: U7.8 (AD2), U8.4 (D2), U9.4 (D2), U10.4 (D2)
/VIDEO/AD3: U7.7 (AD3), U8.5 (D3), U9.5 (D3), U10.5 (D3)
/VIDEO/AD4: U7.6 (AD4), U8.6 (D4), U9.6 (D4), U10.6 (D4)
/VIDEO/AD5: U7.5 (AD5), U8.7 (D5), U9.7 (D5), U10.7 (D5)
/VIDEO/AD6: U7.4 (AD6), U8.8 (D6), U9.8 (D6), U10.8 (D6)
/VIDEO/AD7: U7.3 (AD7), U8.9 (D7), U9.9 (D7), U10.9 (D7)
/VIDEO/VA0: U8.18 (Q1), U11.10 (A0)
/VIDEO/VA1: U8.17 (Q2), U11.9 (A1)
/VIDEO/VA2: U8.16 (Q3), U11.8 (A2)
/VIDEO/VA3: U8.15 (Q4), U11.7 (A3)
/VIDEO/VA4: U8.14 (Q5), U11.21 (A10)
/VIDEO/VA5: U8.13 (Q6), U11.6 (A4)
/VIDEO/VA6: U8.12 (Q7), U11.5 (A5)
/VIDEO/VA7: U9.18 (Q1), U11.23 (A11)
/VIDEO/VA8: U9.17 (Q2), U11.4 (A6)
/VIDEO/VA9: U9.16 (Q3), U11.3 (A7)
/VIDEO/VA10: U9.15 (Q4), U11.24 (A9)
/VIDEO/VA11: U9.14 (Q5), U11.2 (A12)
/VIDEO/VA12: U9.13 (Q6), U11.25 (A8)
/VIDEO/VA13: U9.12 (Q7), U11.26 (A13)
/VIDEO/VD0: U7.32 (RD0), U10.19 (Q0), U11.11 (DQ0)
/VIDEO/VD1: U7.31 (RD1), U10.18 (Q1), U11.12 (DQ1)
/VIDEO/VD2: U7.30 (RD2), U10.17 (Q2), U11.13 (DQ2)
/VIDEO/VD3: U7.29 (RD3), U10.16 (Q3), U11.15 (DQ3)
/VIDEO/VD4: U7.28 (RD4), U10.15 (Q4), U11.16 (DQ4)
/VIDEO/VD5: U7.27 (RD5), U10.14 (Q5), U11.17 (DQ5)
/VIDEO/VD6: U7.26 (RD6), U10.13 (Q6), U11.18 (DQ6)
/VIDEO/VD7: U7.25 (RD7), U10.12 (Q7), U11.19 (DQ7)
/VIDEO//CAS: U7.2 (~CAS), U11.20 (CE#), U17.9
/VIDEO//CSR: U7.15 (~CSR), U16.6
/VIDEO//CSW: U7.14 (~CSW), U16.8
/VIDEO//RAS: U7.1 (~RAS), U17.1
/WR: U16.10; also elsewhere on the board
//RESET: U7.34 (~RESET/SYNC); also elsewhere on the board
GND: C16.1, C17.1, C18.1, C20.2, C21.2, C22.1, C23.1, C24.1, C25.1, C26.1, J3.2 (Ext), R17.2, R18.2, U7.12 (VSS), U8.1 (OE), U8.10 (GND), U9.1 (OE), U9.10 (GND), U10.10 (GND), U11.1 (A14), U11.14 (VSS), U16.7 (GND), U17.7 (GND); also elsewhere on the board
unnamed: C16.2, U7.39 (XTAL1), Y2.1
unnamed: C17.2, U7.40 (XTAL2), Y2.2
unnamed: C19.1, R19.1
unnamed: C19.2, J3.1 (In)
unnamed: Q2.1 (E), R18.1, R19.2
unnamed: Q2.2 (B), R17.1, U7.36 (COMVID)
unnamed: U7.11 (R/~W), U10.1 (OE), U11.27 (WE#), U17.11
unnamed: U10.11 (Cp), U11.22 (OE#), U17.10
unnamed: U16.3, U16.4, U16.9
unnamed: U8.11 (Cp), U17.2
unnamed: U17.3, U17.8
unnamed: U17.4, U17.5
unnamed: U9.11 (Cp), U17.6
VCC: C18.2, C20.1, C21.1, C22.2, C23.2, C24.2, C25.2, C26.2, Q2.3 (C), U7.33 (VCC), U8.20 (VCC), U9.20 (VCC), U10.20 (VCC), U11.28 (VCC), U16.14 (VCC), U17.14 (VCC); also elsewhere on the board

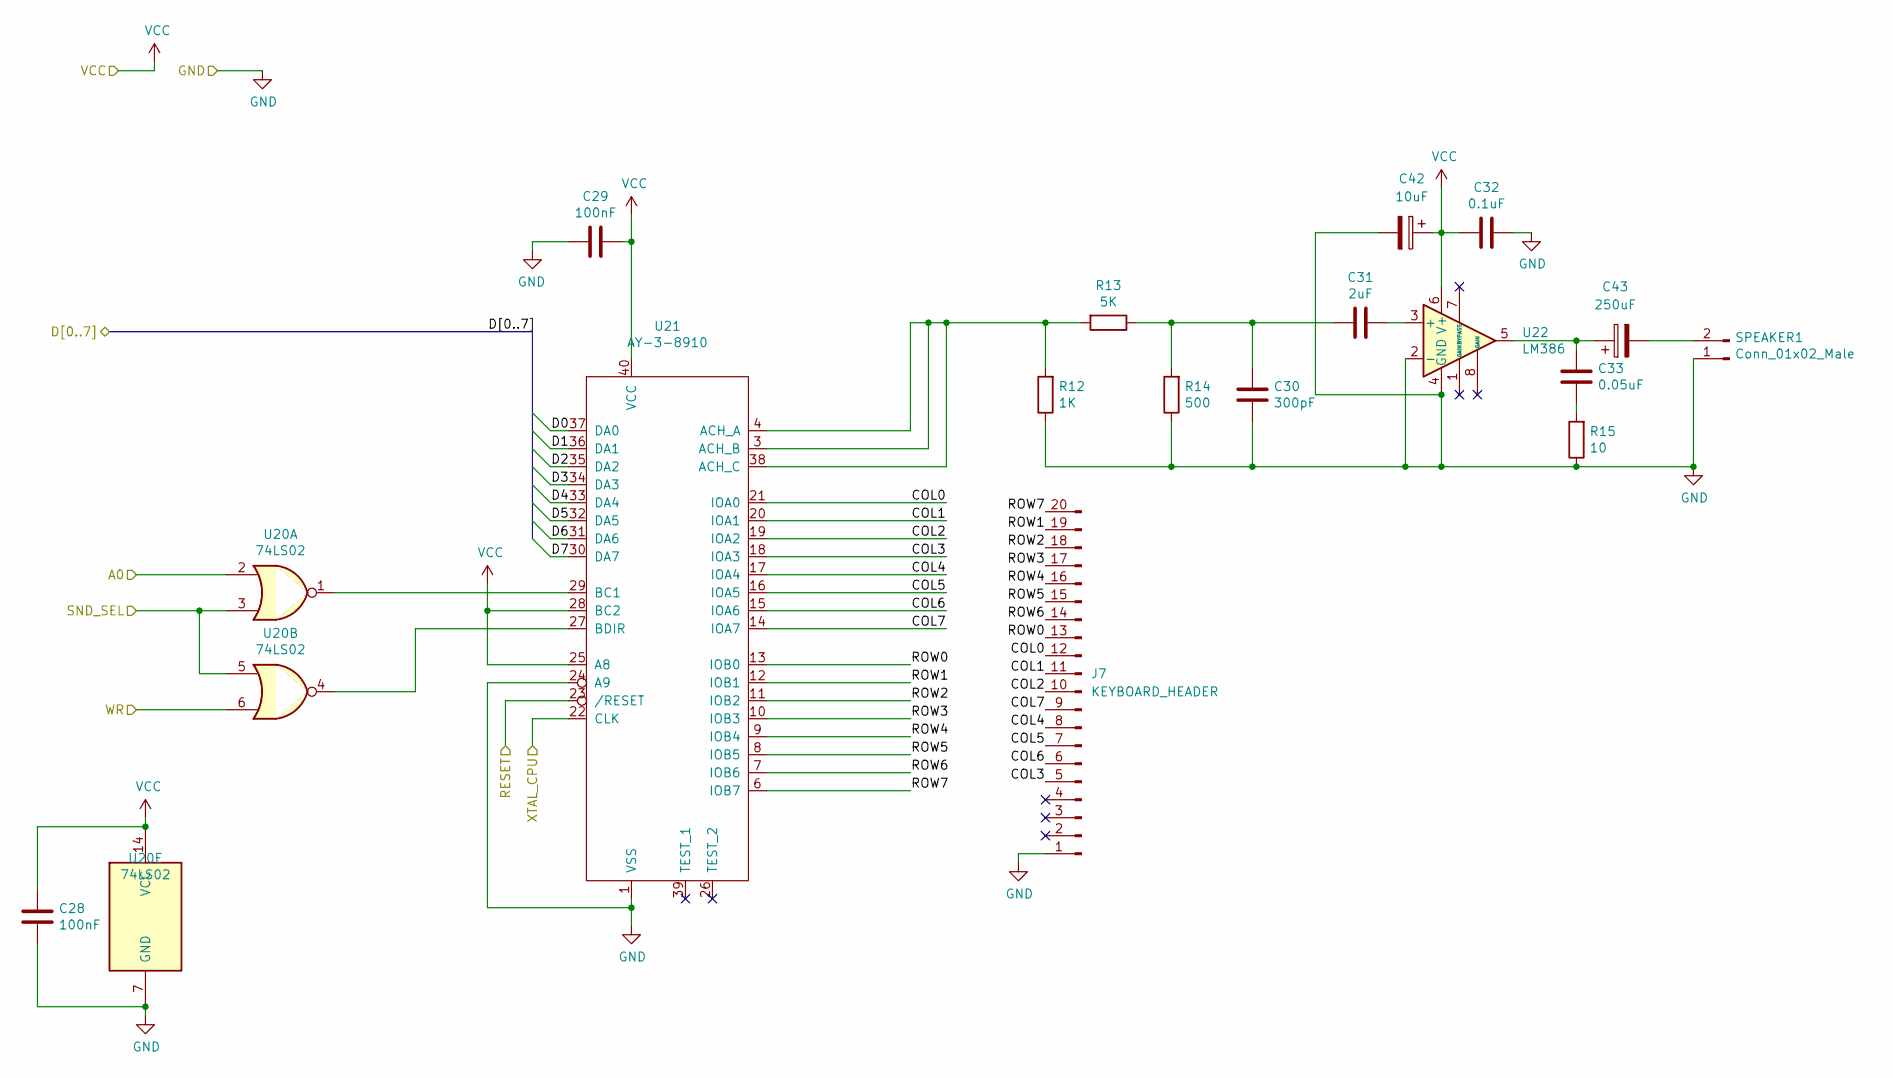
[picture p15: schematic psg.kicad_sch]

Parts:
C28, C29: 100nF; C_Disc_D7.0mm_W2.5mm_P5.00mm
C30: 300pF; C_Disc_D5.0mm_W2.5mm_P5.00mm
C31: 2uF; C_Disc_D5.0mm_W2.5mm_P5.00mm
C32: 0.1uF; C_Disc_D7.0mm_W2.5mm_P5.00mm
C33: 0.05uF; C_Disc_D5.0mm_W2.5mm_P5.00mm
C42: 10uF; CP_Radial_D5.0mm_P2.00mm
C43: 250uF; CP_Radial_D6.3mm_P2.50mm
J7: KEYBOARD_HEADER; PinHeader_1x20_P2.54mm_Vertical
R12: 1K; R_Axial_DIN0207_L6.3mm_D2.5mm_P10.16mm_Horizontal
R13: 5K; R_Axial_DIN0207_L6.3mm_D2.5mm_P10.16mm_Horizontal
R14: 500; R_Axial_DIN0207_L6.3mm_D2.5mm_P10.16mm_Horizontal
R15: 10; R_Axial_DIN0207_L6.3mm_D2.5mm_P10.16mm_Horizontal
SPEAKER1: Conn_01x02_Male; PinHeader_1x02_P2.54mm_Vertical
U20: 74LS02; DIP-14_W7.62mm_Socket_LongPads
U21: AY-3-8910; DIP-40_W15.24mm_LongPads
U22: LM386; DIP-8_W7.62mm_LongPads

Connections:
/BUS Expansion/D0: U21.37 (DA0); also elsewhere on the board
/BUS Expansion/D1: U21.36 (DA1); also elsewhere on the board
/BUS Expansion/D2: U21.35 (DA2); also elsewhere on the board
/BUS Expansion/D3: U21.34 (DA3); also elsewhere on the board
/BUS Expansion/D4: U21.33 (DA4); also elsewhere on the board
/BUS Expansion/D5: U21.32 (DA5); also elsewhere on the board
/BUS Expansion/D6: U21.31 (DA6); also elsewhere on the board
/BUS Expansion/D7: U21.30 (DA7); also elsewhere on the board
/IO/A0: U20.2; also elsewhere on the board
/PSG_CE: U20.3, U20.5; also elsewhere on the board
/SOUND/COL0: J7.12, U21.21 (IOA0)
/SOUND/COL1: J7.11, U21.20 (IOA1)
/SOUND/COL2: J7.10, U21.19 (IOA2)
/SOUND/COL3: J7.5, U21.18 (IOA3)
/SOUND/COL4: J7.8, U21.17 (IOA4)
/SOUND/COL5: J7.7, U21.16 (IOA5)
/SOUND/COL6: J7.6, U21.15 (IOA6)
/SOUND/COL7: J7.9, U21.14 (IOA7)
/SOUND/ROW0: J7.13, U21.13 (IOB0)
/SOUND/ROW1: J7.19, U21.12 (IOB1)
/SOUND/ROW2: J7.18, U21.11 (IOB2)
/SOUND/ROW3: J7.17, U21.10 (IOB3)
/SOUND/ROW4: J7.16, U21.9 (IOB4)
/SOUND/ROW5: J7.15, U21.8 (IOB5)
/SOUND/ROW6: J7.14, U21.7 (IOB6)
/SOUND/ROW7: J7.20, U21.6 (IOB7)
/WR: U20.6; also elsewhere on the board
/XTAL: U21.22 (CLK); also elsewhere on the board
//RESET: U21.23 (/RESET); also elsewhere on the board
GND: C28.1, C29.2, C30.2, C32.2, C42.2, J7.1, R12.1, R14.1, R15.1, SPEAKER1.1, U20.7 (GND), U21.1 (VSS), U21.24 (A9), U22.2 (-), U22.4 (GND); also elsewhere on the board
unnamed: C30.1, C31.2, R13.1, R14.2
unnamed: C31.1, U22.3 (+)
unnamed: C33.1, C43.1, U22.5
unnamed: C33.2, R15.2
unnamed: C43.2, SPEAKER1.2
unnamed: R12.2, R13.2, U21.3 (ACH_B), U21.4 (ACH_A), U21.38 (ACH_C)
unnamed: U20.1, U21.29 (BC1)
unnamed: U20.4, U21.27 (BDIR)
VCC: C28.2, C29.1, C32.1, C42.1, U20.14 (VCC), U21.25 (A8), U21.28 (BC2), U21.40 (VCC), U22.6 (V+); also elsewhere on the board

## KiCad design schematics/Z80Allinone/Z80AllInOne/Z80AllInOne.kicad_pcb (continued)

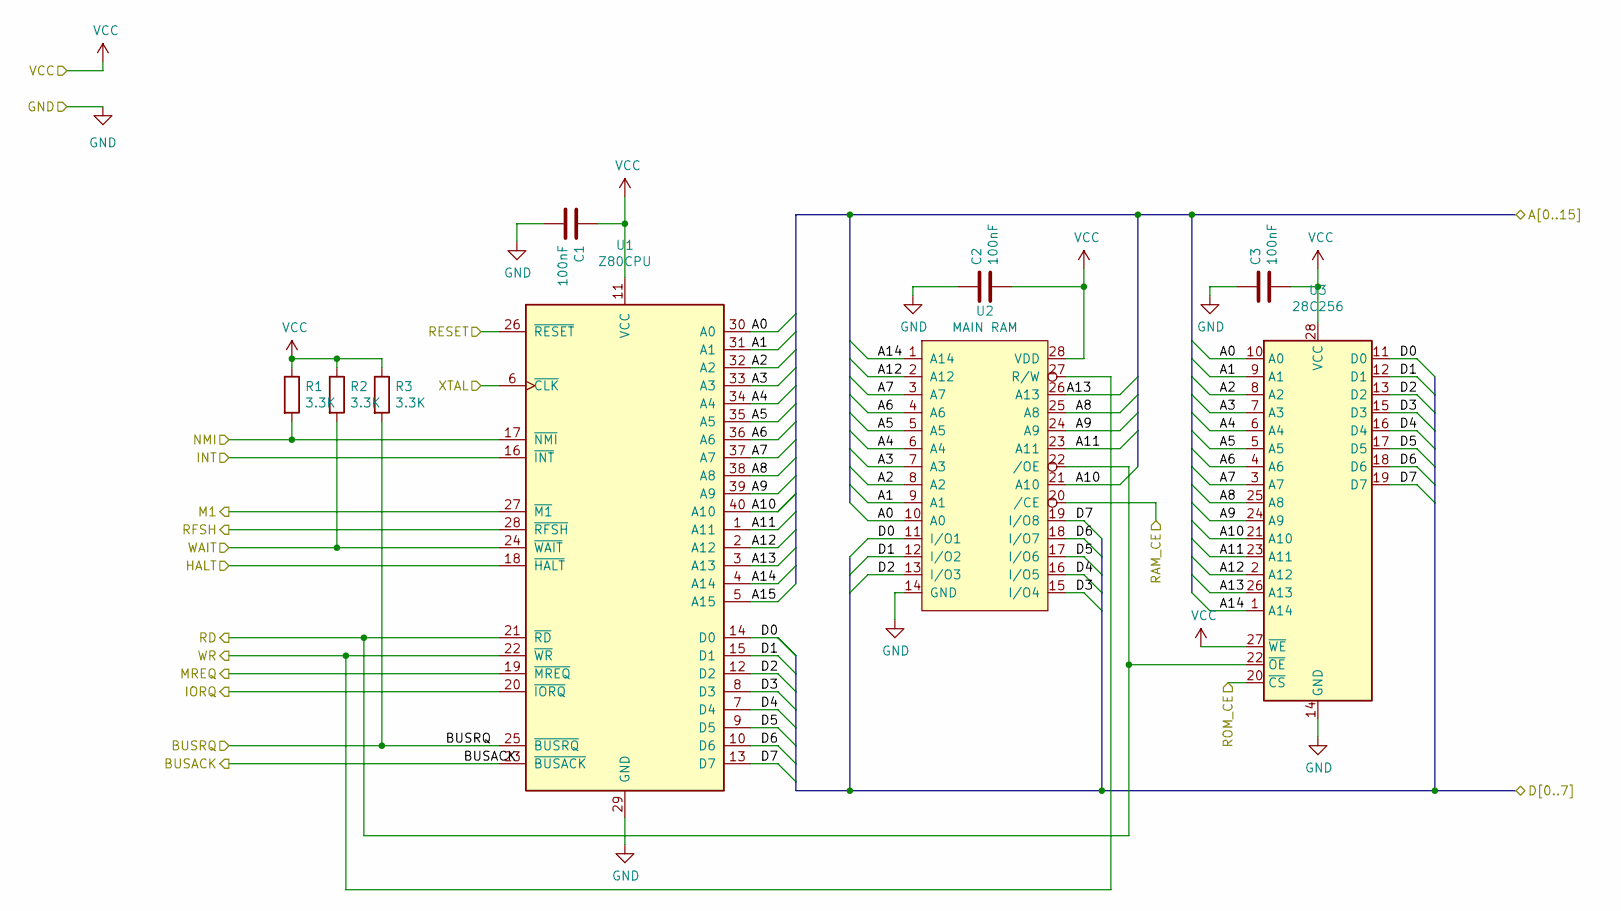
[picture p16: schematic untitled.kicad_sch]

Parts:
C1, C2, C3: 100nF; C_Disc_D7.0mm_W2.5mm_P5.00mm
R1, R2, R3: 3.3K; R_Axial_DIN0207_L6.3mm_D2.5mm_P7.62mm_Horizontal
U1: Z80CPU; DIP-40_W15.24mm_LongPads
U2: MAIN RAM; DIP-28_W15.24mm_LongPads
U3: 28C256; DIP-28_W15.24mm_LongPads

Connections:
/BUS Expansion/D0: U1.14 (D0), U2.11 (I/O1), U3.11 (D0); also elsewhere on the board
/BUS Expansion/D1: U1.15 (D1), U2.12 (I/O2), U3.12 (D1); also elsewhere on the board
/BUS Expansion/D2: U1.12 (D2), U2.13 (I/O3), U3.13 (D2); also elsewhere on the board
/BUS Expansion/D3: U1.8 (D3), U2.15 (I/O4), U3.15 (D3); also elsewhere on the board
/BUS Expansion/D4: U1.7 (D4), U2.16 (I/O5), U3.16 (D4); also elsewhere on the board
/BUS Expansion/D5: U1.9 (D5), U2.17 (I/O6), U3.17 (D5); also elsewhere on the board
/BUS Expansion/D6: U1.10 (D6), U2.18 (I/O7), U3.18 (D6); also elsewhere on the board
/BUS Expansion/D7: U1.13 (D7), U2.19 (I/O8), U3.19 (D7); also elsewhere on the board
/BUSACK: U1.23 (~BUSACK); also elsewhere on the board
/BUSRQ: R3.2, U1.25 (~BUSRQ); also elsewhere on the board
/CPU_MEM/RFSH: U1.28 (~RFSH)
/HALT: U1.18 (~HALT); also elsewhere on the board
/IO/A0: U1.30 (A0), U2.10 (A0), U3.10 (A0); also elsewhere on the board
/IO/A1: U1.31 (A1), U2.9 (A1), U3.9 (A1); also elsewhere on the board
/IO/A2: U1.32 (A2), U2.8 (A2), U3.8 (A2); also elsewhere on the board
/IO/A3: U1.33 (A3), U2.7 (A3), U3.7 (A3); also elsewhere on the board
/IO/A4: U1.34 (A4), U2.6 (A4), U3.6 (A4); also elsewhere on the board
/IO/A5: U1.35 (A5), U2.5 (A5), U3.5 (A5); also elsewhere on the board
/IO/A6: U1.36 (A6), U2.4 (A6), U3.4 (A6); also elsewhere on the board
/IO/A7: U1.37 (A7), U2.3 (A7), U3.3 (A7); also elsewhere on the board
/IO/A8: U1.38 (A8), U2.25 (A8), U3.25 (A8); also elsewhere on the board
/IO/A9: U1.39 (A9), U2.24 (A9), U3.24 (A9); also elsewhere on the board
/IO/A10: U1.40 (A10), U2.21 (A10), U3.21 (A10); also elsewhere on the board
/IO/A11: U1.1 (A11), U2.23 (A11), U3.23 (A11); also elsewhere on the board
/IO/A12: U1.2 (A12), U2.2 (A12), U3.2 (A12); also elsewhere on the board
/IO/A13: U1.3 (A13), U2.26 (A13), U3.26 (A13); also elsewhere on the board
/IO/A14: U1.4 (A14), U2.1 (A14), U3.1 (A14); also elsewhere on the board
/IO/A15: U1.5 (A15); also elsewhere on the board
/IORQ: U1.20 (~IORQ); also elsewhere on the board
/M1: U1.27 (~M1); also elsewhere on the board
/MREQ: U1.19 (~MREQ); also elsewhere on the board
/NMI: R1.2, U1.17 (~NMI); also elsewhere on the board
/RAM_CE: U2.20 (/CE); also elsewhere on the board
/RD: U1.21 (~RD), U2.22 (/OE), U3.22 (~OE); also elsewhere on the board
/ROM_CE: U3.20 (~CS); also elsewhere on the board
/WAIT: R2.2, U1.24 (~WAIT); also elsewhere on the board
/WR: U1.22 (~WR), U2.27 (R/W); also elsewhere on the board
/XTAL: U1.6 (~CLK); also elsewhere on the board
//INT: U1.16 (~INT); also elsewhere on the board
//RESET: U1.26 (~RESET); also elsewhere on the board
GND: C1.2, C2.1, C3.1, U1.29 (GND), U2.14 (GND), U3.14 (GND); also elsewhere on the board
VCC: C1.1, C2.2, C3.2, R1.1, R2.1, R3.1, U1.11 (VCC), U2.28 (VDD), U3.27 (~WE), U3.28 (VCC); also elsewhere on the board

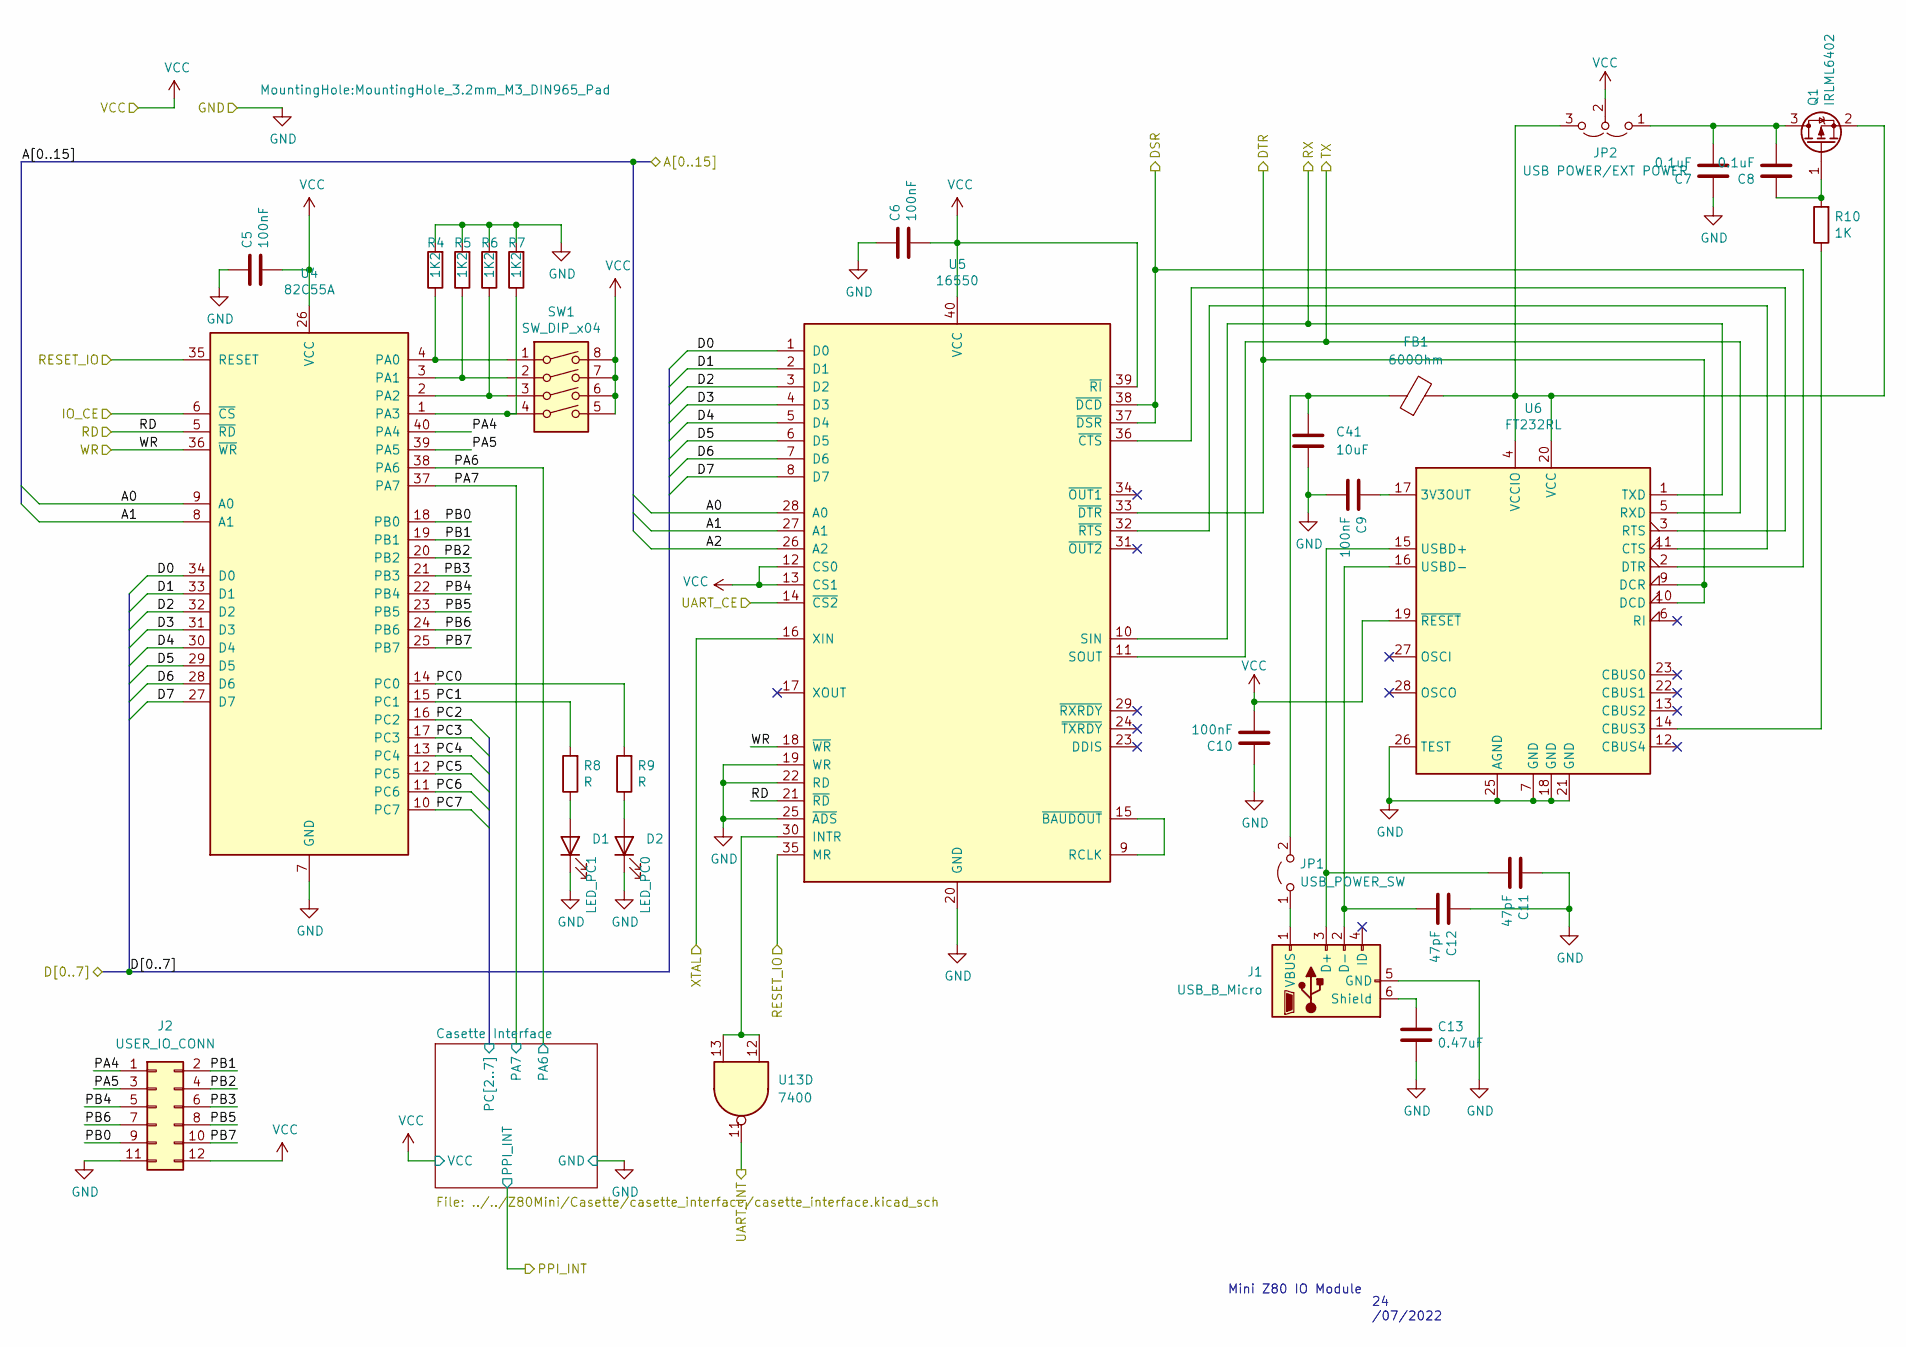
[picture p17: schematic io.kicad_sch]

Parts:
C5, C6, C9, C10: 100nF; C_Disc_D7.0mm_W2.5mm_P5.00mm
C7, C8: 0.1uF; C_Disc_D3.0mm_W1.6mm_P2.50mm
C11, C12: 47pF; C_Disc_D3.0mm_W1.6mm_P2.50mm
C13: 0.47uF; C_Disc_D3.0mm_W1.6mm_P2.50mm
C41: 10uF; CP_Radial_D5.0mm_P2.50mm
D1: LED_PC1; LED_D3.0mm
D2: LED_PC0; LED_D3.0mm
FB1: 600Ohm; L_0805_2012Metric
J1: USB_B_Micro; USB_Mini-B_Lumberg_2486_01_Horizontal
J2: USER_IO_CONN; EdgeConector_18pin
JP1: USB_POWER_SW; PinHeader_1x02_P2.54mm_Vertical
JP2: USB POWER/EXT POWER; PinHeader_1x03_P2.54mm_Vertical
Q1: IRLML6402; SOT-23
R4, R5, R6, R7: 1K2; R_Axial_DIN0207_L6.3mm_D2.5mm_P7.62mm_Horizontal
R8, R9: R; R_Axial_DIN0207_L6.3mm_D2.5mm_P7.62mm_Horizontal
R10: 1K; R_Axial_DIN0207_L6.3mm_D2.5mm_P7.62mm_Horizontal
SW1: SW_DIP_x04; DIP-8_W7.62mm_LongPads
U4: 82C55A; DIP-40_W15.24mm
U5: 16550; DIP-40_W15.24mm
U6: FT232RL; SSOP-28_5.3x10.2mm_P0.65mm
U13: 7400; DIP-14_W7.62mm_LongPads

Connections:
/BUS Expansion/D0: U4.34 (D0), U5.1 (D0); also elsewhere on the board
/BUS Expansion/D1: U4.33 (D1), U5.2 (D1); also elsewhere on the board
/BUS Expansion/D2: U4.32 (D2), U5.3 (D2); also elsewhere on the board
/BUS Expansion/D3: U4.31 (D3), U5.4 (D3); also elsewhere on the board
/BUS Expansion/D4: U4.30 (D4), U5.5 (D4); also elsewhere on the board
/BUS Expansion/D5: U4.29 (D5), U5.6 (D5); also elsewhere on the board
/BUS Expansion/D6: U4.28 (D6), U5.7 (D6); also elsewhere on the board
/BUS Expansion/D7: U4.27 (D7), U5.8 (D7); also elsewhere on the board
/DSR: U5.37 (~DSR), U5.38 (~DCD), U6.2 (DTR); also elsewhere on the board
/DTR: U5.33 (~DTR), U6.9 (DCR), U6.10 (DCD); also elsewhere on the board
/IO/A0: U4.9 (A0), U5.28 (A0); also elsewhere on the board
/IO/A1: U4.8 (A1), U5.27 (A1); also elsewhere on the board
/IO/A2: U5.26 (A2); also elsewhere on the board
/IO/Casette Interface/PC2: U4.16 (PC2); also elsewhere on the board
/IO/Casette Interface/PC3: U4.17 (PC3); also elsewhere on the board
/IO/Casette Interface/PC4: U4.13 (PC4); also elsewhere on the board
/IO/Casette Interface/PC5: U4.12 (PC5); also elsewhere on the board
/IO/Casette Interface/PC6: U4.11 (PC6); also elsewhere on the board
/IO/Casette Interface/PC7: U4.10 (PC7); also elsewhere on the board
/IO/PA4: J2.1, U4.40 (PA4)
/IO/PA5: J2.3, U4.39 (PA5)
/IO/PA6: U4.38 (PA6); also elsewhere on the board
/IO/PA7: U4.37 (PA7); also elsewhere on the board
/IO/PB0: J2.9, U4.18 (PB0)
/IO/PB1: J2.2, U4.19 (PB1)
/IO/PB2: J2.4, U4.20 (PB2)
/IO/PB3: J2.6, U4.21 (PB3)
/IO/PB4: J2.5, U4.22 (PB4)
/IO/PB5: J2.8, U4.23 (PB5)
/IO/PB6: J2.7, U4.24 (PB6)
/IO/PB7: J2.10, U4.25 (PB7)
/IO/PC0: R9.2, U4.14 (PC0)
/IO/PC1: R8.2, U4.15 (PC1)
/PPI_CE: U4.6 (~CS); also elsewhere on the board
/RD: U4.5 (~RD), U5.21 (~RD); also elsewhere on the board
/RESET_IO: U4.35 (RESET), U5.35 (MR); also elsewhere on the board
/RX: U5.10 (SIN), U6.1 (TXD); also elsewhere on the board
/TX: U5.11 (SOUT), U6.5 (RXD); also elsewhere on the board
/UART_CE: U5.14 (~CS2); also elsewhere on the board
/UART_INT: U13.11; also elsewhere on the board
/WR: U4.36 (~WR), U5.18 (~WR); also elsewhere on the board
/XTAL: U5.16 (XIN); also elsewhere on the board
GND: C5.1, C6.1, C7.1, C9.2, C10.1, C11.1, C12.1, C13.2, C41.2, D1.1 (K), D2.1 (K), J1.5 (GND), J2.11, R4.2, R5.2, R6.2, R7.2, U4.7 (GND), U5.19 (WR), U5.20 (GND), U5.22 (RD), U5.25 (~ADS), U6.7 (GND), U6.18 (GND), U6.21 (GND), U6.25 (AGND), U6.26 (TEST); also elsewhere on the board
unnamed: C7.2, C8.2, JP2.1 (A), Q1.3 (D)
unnamed: C8.1, Q1.1 (G), R10.2
unnamed: C9.1, U6.17 (3V3OUT)
unnamed: C11.2, J1.3 (D+), U6.15 (USBD+)
unnamed: C12.2, J1.2 (D-), U6.16 (USBD-)
unnamed: C13.1, J1.6 (Shield)
unnamed: C41.1, FB1.1, JP1.2 (B)
unnamed: D1.2 (A), R8.1
unnamed: D2.2 (A), R9.1
unnamed: FB1.2, JP2.3 (B), Q1.2 (S), U6.4 (VCCIO), U6.20 (VCC)
unnamed: J1.1 (VBUS), JP1.1 (A)
unnamed: R4.1, SW1.1, U4.4 (PA0)
unnamed: R5.1, SW1.2, U4.3 (PA1)
unnamed: R6.1, SW1.3, U4.2 (PA2)
unnamed: R7.1, SW1.4, U4.1 (PA3)
unnamed: R10.1, U6.14 (CBUS3)
unnamed: U5.9 (RCLK), U5.15 (~BAUDOUT)
unnamed: U5.32 (~RTS), U6.11 (CTS)
unnamed: U5.36 (~CTS), U6.3 (RTS)
unnamed: U5.30 (INTR), U13.12, U13.13
VCC: C5.2, C6.2, C10.2, J2.12, JP2.2 (C), SW1.5, SW1.6, SW1.7, SW1.8, U4.26 (VCC), U5.12 (CS0), U5.13 (CS1), U5.39 (~RI), U5.40 (VCC), U6.19 (~RESET); also elsewhere on the board

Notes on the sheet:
Mini Z80 IO Module
24 /07/2022

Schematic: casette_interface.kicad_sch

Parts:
C47, C48, C49, C51: C_Disc_D7.0mm_W2.5mm_P5.00mm
C50: 100nF; C_Disc_D7.0mm_W2.5mm_P5.00mm
D7, D8, D9, D10: D_DO-35_SOD27_P7.62mm_Horizontal
J6: CASETTE/AUDIO; DIN-5
K1: ADW11; Relay_1P1T_NO_10x24x18.8mm_Panasonic_ADW11xxxxW_THT
Q4: BC337; TO-92_Inline
R24, R25, R26, R27, R28, R29, R30, R31, R32, R33, R34, R35, R36, R37, R38, R39, R40, R41: R_Axial_DIN0207_L6.3mm_D2.5mm_P7.62mm_Horizontal
U18: DIP-14_W7.62mm_LongPads
U19: DIP-8_W7.62mm_LongPads

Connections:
/IO/Casette Interface/M1: C47.2, D8.2 (K), J6.1, K1.3, K1.14
/IO/Casette Interface/M2: C47.1, D9.2 (K), J6.3, K1.5, K1.11
/IO/Casette Interface/PC2: U18.13; also elsewhere on the board
/IO/Casette Interface/PC4: U18.9; also elsewhere on the board
/IO/Casette Interface/PC5: U18.5; also elsewhere on the board
/IO/Casette Interface/PC6: U18.3; also elsewhere on the board
/IO/Casette Interface/PC7: U18.1; also elsewhere on the board
/IO/PA6: R34.1, R35.2, U19.1; also elsewhere on the board
/IO/PA7: R24.2; also elsewhere on the board
GND: C48.2, C49.2, C50.2, C51.1, D10.1 (A), J6.2, Q4.3 (E), R33.1, R37.1, R41.1, U18.7 (GND), U19.8 (V+); also elsewhere on the board
unnamed: C48.1, R25.1, R26.1, R27.1, R28.1, R29.1, R30.1, R31.2, R32.2
unnamed: C49.1, J6.5, R32.1, R33.2
unnamed: C51.2, J6.4, R40.2, R41.2
unnamed: D7.1 (A), K1.6, K1.A2, Q4.1 (C)
unnamed: D8.1 (A), D9.1 (A)
unnamed: D10.2 (K), R39.2, R40.1
unnamed 182: U18.11; also elsewhere on the board
unnamed: Q4.2 (B), R24.1
unnamed: R25.2, U18.2
unnamed: R26.2, U18.4
unnamed: R27.2, U18.6
unnamed: R28.2, U18.8
unnamed: R29.2, U18.10
unnamed: R30.2, U18.12
unnamed: R35.1, R36.1, R37.2, U19.2 (-)
unnamed: R38.1, R39.1, U19.3 (+)
VCC: C50.1, D7.2 (K), K1.1, K1.A1, R31.1, R34.2, R36.2, R38.2, U18.14 (VCC), U19.4 (V-); also elsewhere on the board

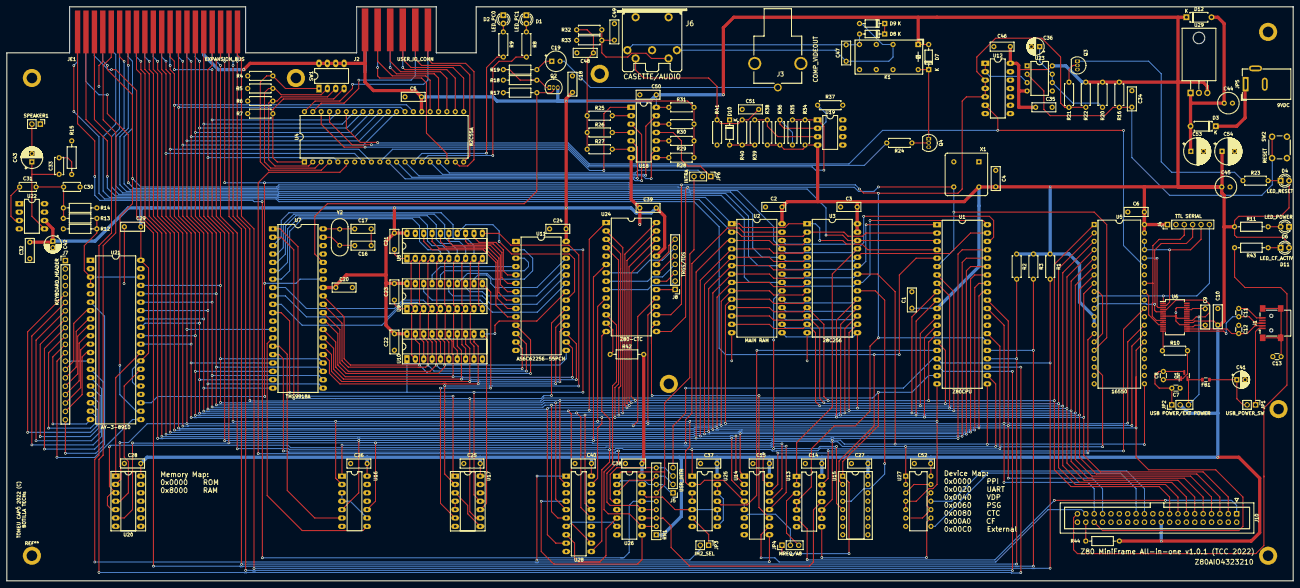
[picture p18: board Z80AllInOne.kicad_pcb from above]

Board: 2 copper layers, 389.9 x 174.0 mm, 166 parts (0 on the bottom side), 226 nets.

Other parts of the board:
JP6: INTRA; PinHeader_1x03_P2.54mm_Vertical

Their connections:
/IO/Casette Interface/PC3: JP6.2 (C); also elsewhere on the board
/PPI_INT: JP6.3 (B); also elsewhere on the board
unnamed 182: JP6.1 (A); also elsewhere on the board

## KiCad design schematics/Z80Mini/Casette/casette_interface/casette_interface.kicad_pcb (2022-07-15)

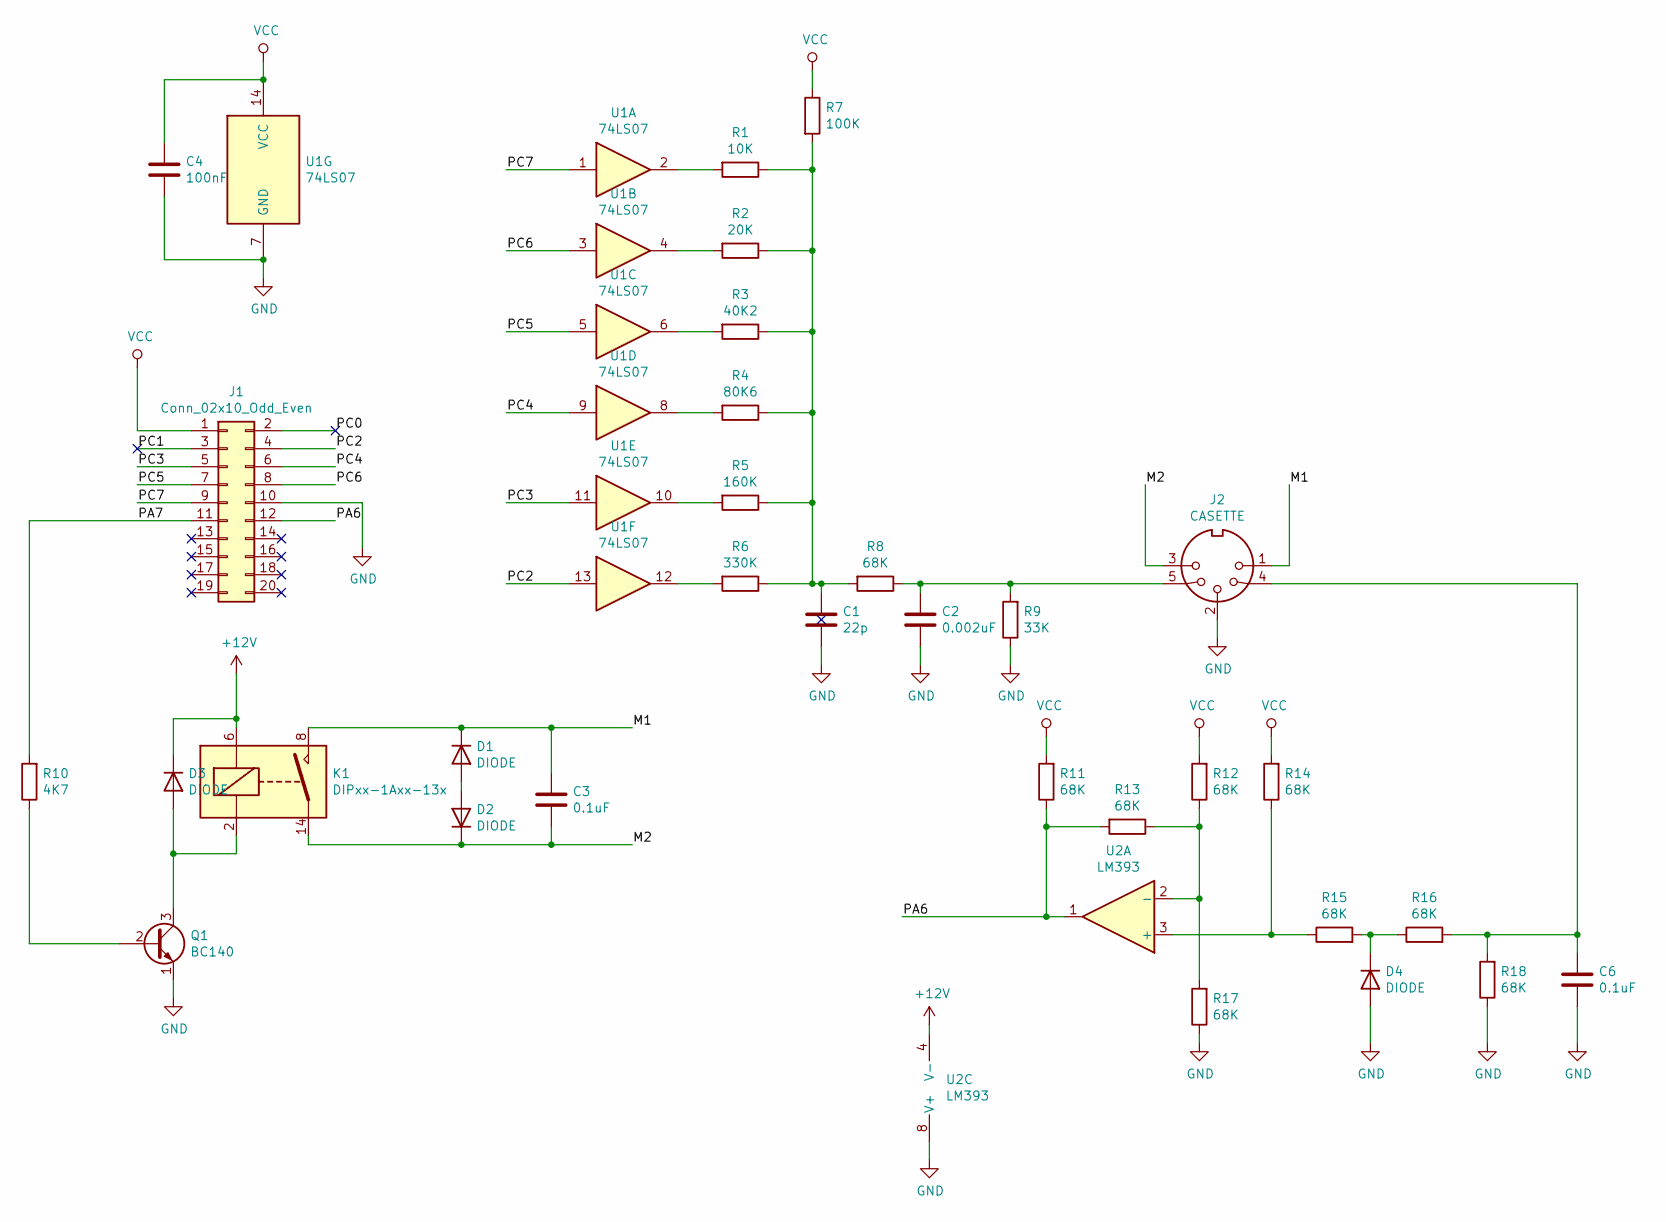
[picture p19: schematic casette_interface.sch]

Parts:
C1: 22p; C_Disc_D3.0mm_W1.6mm_P2.50mm
C2: 0.002uF; C_Disc_D3.0mm_W1.6mm_P2.50mm
C3, C6: 0.1uF; C_Disc_D3.0mm_W1.6mm_P2.50mm
C4: 100nF; C_Disc_D7.0mm_W2.5mm_P5.00mm
D1, D2, D3, D4: DIODE; D_DO-35_SOD27_P7.62mm_Horizontal
J1: Conn_02x10_Odd_Even; IDC-Header_2x10_P2.54mm_Horizontal
J2: CASETTE; DIN-5-180.kicad_mod
K1: DIPxx-1Axx-13x; Relay_StandexMeder_DIP_LowProfile
Q1: BC140; TO-39-3
R1: 10K; R_Axial_DIN0207_L6.3mm_D2.5mm_P7.62mm_Horizontal
R2: 20K; R_Axial_DIN0207_L6.3mm_D2.5mm_P7.62mm_Horizontal
R3: 40K2; R_Axial_DIN0207_L6.3mm_D2.5mm_P7.62mm_Horizontal
R4: 80K6; R_Axial_DIN0207_L6.3mm_D2.5mm_P7.62mm_Horizontal
R5: 160K; R_Axial_DIN0207_L6.3mm_D2.5mm_P7.62mm_Horizontal
R6: 330K; R_Axial_DIN0207_L6.3mm_D2.5mm_P7.62mm_Horizontal
R7: 100K; R_Axial_DIN0207_L6.3mm_D2.5mm_P7.62mm_Horizontal
R8, R11, R12, R13, R14, R15, R16, R17, R18: 68K; R_Axial_DIN0207_L6.3mm_D2.5mm_P7.62mm_Horizontal
R9: 33K; R_Axial_DIN0207_L6.3mm_D2.5mm_P7.62mm_Horizontal
R10: 4K7; R_Axial_DIN0207_L6.3mm_D2.5mm_P7.62mm_Horizontal
U1: 74LS07; DIP-14_W7.62mm_LongPads
U2: LM393; DIP-8_W7.62mm_Socket_LongPads

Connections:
/M1: C3.2, D1.2 (K), J2.1, K1.8
/M2: C3.1, D2.2 (K), J2.3, K1.14
/PA6: J1.12, R11.1, R13.2, U2.1
/PA7: J1.11, R10.2
/PC0: J1.2
/PC1: J1.3
/PC2: J1.4, U1.13
/PC3: J1.5, U1.11
/PC4: J1.6, U1.9
/PC5: J1.7, U1.5
/PC6: J1.8, U1.3
/PC7: J1.9, U1.1
GND: C1.2, C2.2, C4.2, C6.1, D4.1 (A), J1.10, J2.2, Q1.1 (E), R9.1, R17.1, R18.1, U1.7 (GND), U2.8 (V+)
unnamed: C1.1, R1.1, R2.1, R3.1, R4.1, R5.1, R6.1, R7.2, R8.2
unnamed: C2.1, J2.5, R8.1, R9.2
unnamed: C6.2, J2.4, R16.2, R18.2
unnamed: D1.1 (A), D2.1 (A)
unnamed: D3.1 (A), K1.2, Q1.3 (C)
unnamed: D4.2 (K), R15.2, R16.1
unnamed: Q1.2 (B), R10.1
unnamed: R1.2, U1.2
unnamed: R2.2, U1.4
unnamed: R3.2, U1.6
unnamed: R4.2, U1.8
unnamed: R5.2, U1.10
unnamed: R6.2, U1.12
unnamed: R12.1, R13.1, R17.2, U2.2 (-)
unnamed: R14.1, R15.1, U2.3 (+)

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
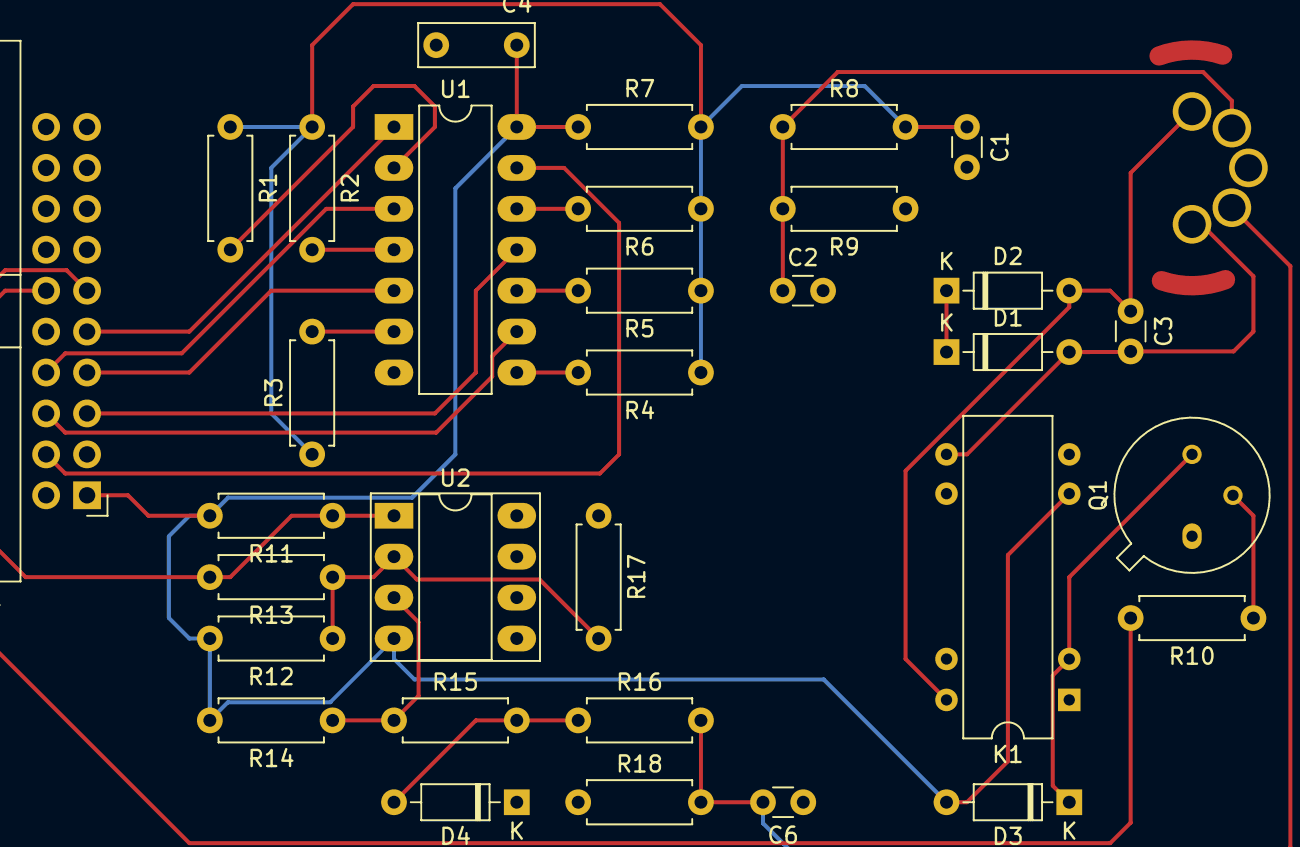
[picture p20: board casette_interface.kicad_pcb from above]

Board: 2 copper layers, 33 parts (0 on the bottom side), 27 nets.

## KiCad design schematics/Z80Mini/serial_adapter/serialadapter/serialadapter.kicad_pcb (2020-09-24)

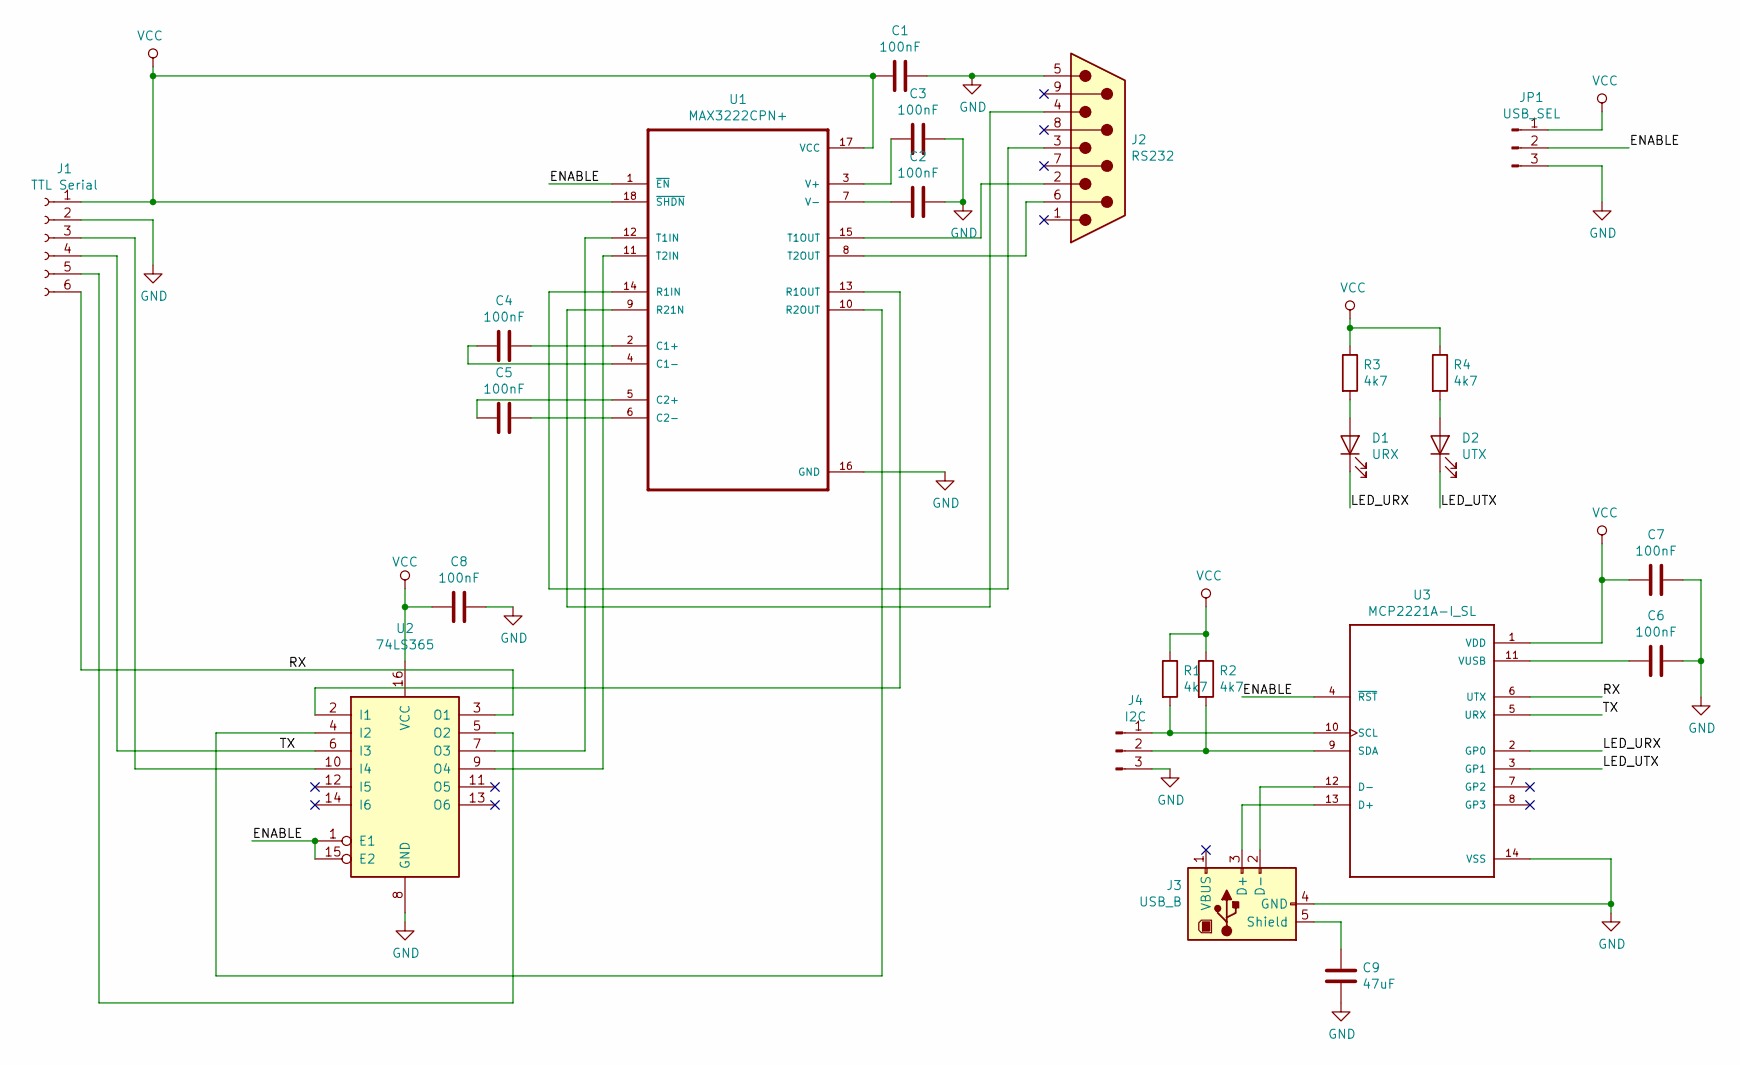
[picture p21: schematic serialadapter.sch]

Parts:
C1, C2, C3, C4, C5, C6, C7, C8: 100nF; C_Disc_D7.0mm_W2.5mm_P5.00mm
C9: 47uF; C_Disc_D7.0mm_W2.5mm_P5.00mm
D1: URX; LED_D3.0mm
D2: UTX; LED_D3.0mm
J1: TTL Serial; PinHeader_1x06_P2.54mm_Vertical
J2: RS232; DSUB-9_Male_Horizontal_P2.77x2.84mm_EdgePinOffset4.94mm_Hou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
J3: USB_B; USB_B_OST_USB-B1HSxx_Horizontal
J4: I2C; PinHeader_1x03_P2.54mm_Vertical
JP1: USB_SEL; PinHeader_1x03_P2.54mm_Vertical
R1, R2, R3, R4: 4k7; R_Axial_DIN0207_L6.3mm_D2.5mm_P10.16mm_Horizontal
U1: MAX3222CPN+; DIP-18_W7.62mm
U2: 74LS365; DIP-16_W7.62mm
U3: MCP2221A-I_SL; DIP-14_W7.62mm_Socket

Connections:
/ENABLE: JP1.2, U1.1 (~EN~), U2.1 (E1), U2.15 (E2), U3.4 (~RST~)
/LED_URX: D1.1 (K), U3.2 (GP0)
/LED_UTX: D2.1 (K), U3.3 (GP1)
/RX: J1.6, U2.3 (O1), U3.6 (UTX)
/TX: J1.4, U2.6 (I3), U3.5 (URX)
GND: C1.1, C2.1, C3.1, C6.1, C7.1, C8.1, C9.1, J1.2, J2.5, J3.4 (GND), J4.3, JP1.3, U1.16 (GND), U2.8 (GND), U3.14 (VSS); also elsewhere on the board
unnamed: C2.2, U1.7 (V-)
unnamed: C3.2, U1.3 (V+)
unnamed: C4.1, U1.2 (C1+)
unnamed: C4.2, U1.4 (C1-)
unnamed: C5.1, U1.5 (C2+)
unnamed: C5.2, U1.6 (C2-)
unnamed: C6.2, U3.11 (VUSB)
unnamed: C9.2, J3.5 (Shield)
unnamed: D1.2 (A), R3.2
unnamed: D2.2 (A), R4.2
unnamed: J1.3, U2.10 (I4)
unnamed: J1.5, U2.5 (O2)
unnamed: J2.2, U1.15 (T1OUT)
unnamed: J2.3, U1.14 (R1IN)
unnamed: J2.4, U1.9 (R21N)
unnamed: J2.6, U1.8 (T2OUT)
unnamed: J3.2 (D-), U3.12 (D-)
unnamed: J3.3 (D+), U3.13 (D+)
unnamed: J4.1, R1.2, U3.10 (SCL)
unnamed: J4.2, R2.2, U3.9 (SDA)
unnamed: U1.10 (R2OUT), U2.4 (I2)
unnamed: U1.11 (T2IN), U2.9 (O4)
unnamed: U1.12 (T1IN), U2.7 (O3)
unnamed: U1.13 (R1OUT), U2.2 (I1)
VCC: C1.2, C7.2, C8.2, J1.1, JP1.1, R1.1, R2.1, R3.1, R4.1, U1.17 (VCC), U1.18 (~SHDN~), U2.16 (VCC), U3.1 (VDD)


Board: 2 copper layers, 86.4 x 57.1 mm, 25 parts (0 on the bottom side), 31 nets.

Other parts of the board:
REF1, REF2: MountingHole_3.2mm_M3_DIN965_Pad

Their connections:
GND: REF1.1, REF2.1; also elsewhere on the board

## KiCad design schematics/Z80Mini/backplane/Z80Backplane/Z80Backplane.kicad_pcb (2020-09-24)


Board: 2 copper layers, 161.3 x 94.0 mm, 38 parts (0 on the bottom side), 69 nets.

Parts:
C1: 47uF; C_Radial_D6.3mm_H5.0mm_P2.50mm
C2: 4.7uF; C_Radial_D6.3mm_H5.0mm_P2.50mm
C3, C4, C5, C6: 100nF; C_Disc_D7.0mm_W2.5mm_P5.00mm
D1: DIODE; D_A-405_P7.62mm_Horizontal
D2: LED; LED_D3.0mm
D3: LED_HALT; LED_D3.0mm
D4: LED_M1; LED_D3.0mm
D5: LED_CF_ACTIV; LED_D3.0mm
J1: CPU-IO BOARD; ConnectorEdge40_Female
J2: GRAPHICS_SOUND_CARD; ConnectorEdge40_Female
J3: EXPANSION_1; ConnectorEdge40_Female
J4: EXPANSION_2; ConnectorEdge40_Female
J5: Screw_Terminal_01x02; TerminalBlock_bornier-2_P5.08mm
J6: BUS; IDC-Header_2x20_P2.54mm_Vertical
J7: CF Card IDE; PinHeader_2x20_P2.00mm_Vertical
J8: IOCS7; PinHeader_1x01_P2.54mm_Vertical
JP1: Barrel_Jack_Switch; BarrelJack_Wuerth_6941xx301002
JP2, JP3: Jumper_NC_Dual; PinHeader_1x03_P2.54mm_Vertical
R1: R; R_Axial_DIN0207_L6.3mm_D2.5mm_P10.16mm_Horizontal
R2, R3: 330R; R_Axial_DIN0207_L6.3mm_D2.5mm_P10.16mm_Horizontal
R4, R5: 1K; R_Axial_DIN0207_L6.3mm_D2.5mm_P10.16mm_Horizontal
REF1, REF2, REF3, REF4, REF5: MountingHole_3mm_Pad
SW1: SW_SPDT; PinHeader_1x03_P2.54mm_Vertical
U1: L7805; TO-126-3_Horizontal_TabDown
U2: 74LS138; DIP-16_W7.62mm_Socket
U3: 74LS139; DIP-16_W7.62mm_Socket
U4, U5: 74HC00; DIP-14_W7.62mm

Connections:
/A0: J1.19, J2.19, J3.19, J4.19, J6.19, J7.35
/A1: J1.20, J2.20, J3.20, J4.20, J6.20, J7.33
/A2: J1.21, J2.21, J3.21, J4.21, J6.21, J7.36
/A3: J1.22, J2.22, J3.22, J4.22, J6.22
/A4: J1.23, J2.23, J3.23, J4.23, J6.23
/A5: J1.24, J2.24, J3.24, J4.24, J6.24, U2.1
/A6: J1.25, J2.25, J3.25, J4.25, J6.25, U2.2
/A7: J1.26, J2.26, J3.26, J4.26, J6.26, U2.3
/A8: J1.27, J2.27, J3.27, J4.27, J6.27, U2.6, U3.1
/A9: J1.28, J2.28, J3.28, J4.28, J6.28
/A10: J1.29, J2.29, J3.29, J4.29, J6.29
/A11: J1.30, J2.30, J3.30, J4.30, J6.30
/A12: J1.31, J2.31, J3.31, J4.31, J6.31
/A13: J1.37, J2.37, J3.37, J4.37, J6.37
/A14: J1.38, J2.38, J3.38, J4.38, J6.38
/A15: J1.39, J2.39, J3.39, J4.39, J6.39
/BUSACK: J1.32, J2.32, J3.32, J4.32, J6.32
/BUSRQ: J1.35, J2.35, J3.35, J4.35, J6.35, SW1.2
/D0: J1.10, J2.10, J3.10, J4.10, J6.10, J7.17
/D1: J1.11, J2.11, J3.11, J4.11, J6.11, J7.15
/D2: J1.12, J2.12, J3.12, J4.12, J6.12, J7.13
/D3: J1.13, J2.13, J3.13, J4.13, J6.13, J7.11
/D4: J1.14, J2.14, J3.14, J4.14, J6.14, J7.9
/D5: J1.15, J2.15, J3.15, J4.15, J6.15, J7.7
/D6: J1.16, J2.16, J3.16, J4.16, J6.16, J7.5
/D7: J1.17, J2.17, J3.17, J4.17, J6.17, J7.3
/HALT: J1.3, J2.3, J3.3, J4.3, J6.3, U5.4, U5.5
/INT: J1.40, J2.40, J3.40, J4.40, J6.40
/IOCS0: J3.33, U2.15
/IOCS6: J7.37, U2.9
/IORD: J7.25, U4.8
/IORQ: J1.6, J2.6, J3.6, J4.6, J6.6, U2.4, U2.5, U4.4, U4.5
/IOWR: J7.23, U4.11
/M1: J1.7, J2.7, J3.7, J4.7, J6.7, U5.9, U5.10
/MR: J7.1, U5.11
/MREQ: J1.1, J2.1, J3.1, J4.1, J6.1
/NMI: J1.2, J2.2, J3.2, J4.2, J6.2
/RD: J1.8, J2.8, J3.8, J4.8, J6.8, U4.1, U4.2
/RESET: J1.5, J2.5, J3.5, J4.5, J6.5, U5.12, U5.13
/SND_SEL: J1.36, JP3.3, U3.2
/SND_SEL1: J2.36, JP3.2
/VDP_SEL: J1.33, JP2.3, U3.3
/VDP_SEL1: J2.33, JP2.2
/WAIT: J1.4, J2.4, J3.4, J4.4, J6.4
/WR: J1.18, J2.18, J3.18, J4.18, J6.18, U5.1, U5.2
GND: C1.2, C2.2, C3.1, C4.1, C5.1, C6.1, D2.1, D3.1, D4.1, J1.34, J2.34, J3.34, J4.34, J5.1, J6.34, J7.2, J7.19, J7.22, J7.24, J7.26, J7.30, J7.40, JP1.1, REF2.2, REF3.3, SW1.1, U1.2, U2.8, U3.8, U4.7, U5.7
unnamed: C1.1, D1.2, U1.1
unnamed: D1.1, JP1.3
unnamed: D2.2, R1.2
unnamed: D3.2, R2.1
unnamed: D4.2, R3.1
unnamed: D5.1, R4.1
unnamed: J3.36, U2.14
unnamed: J4.33, U2.13
unnamed: J4.36, U2.12
unnamed: J5.2, JP1.2
unnamed: J6.33, U2.11
unnamed: J6.36, U2.10
unnamed: J7.38, R5.1
unnamed: J7.39, R4.2
unnamed: J8.1, U2.7
unnamed: JP2.1, U3.5
unnamed: JP3.1, U3.6
unnamed: R2.2, U5.6
unnamed: R3.2, U5.8
unnamed: U4.3, U4.9
unnamed: U4.6, U4.10, U4.12
unnamed: U4.13, U5.3
VCC: C2.1, C3.2, C4.2, C5.2, C6.2, D5.2, J1.9, J2.9, J3.9, J4.9, J6.9, J7.20, R1.1, R5.2, SW1.3, U1.3, U2.16, U3.16, U4.14, U5.14

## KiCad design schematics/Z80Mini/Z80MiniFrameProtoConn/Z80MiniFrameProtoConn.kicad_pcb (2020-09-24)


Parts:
J1: Z80MiniFrame BUS; IDC-Header_2x20_P2.54mm_Vertical
J2: ROW1; PinHeader_1x20_P2.54mm_Vertical
J3: ROW2; PinHeader_1x20_P2.54mm_Vertical
J4: DATA; PinHeader_1x08_P2.54mm_Vertical

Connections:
/D0: J1.10, J3.5, J4.1
/D1: J1.11, J2.6, J4.2
/D2: J1.12, J3.6, J4.3
/D3: J1.13, J2.7, J4.4
/D4: J1.14, J3.7, J4.5
/D5: J1.15, J2.8, J4.6
/D6: J1.16, J3.8, J4.7
/D7: J1.17, J2.9, J4.8
GND: J1.34, J3.17
unnamed: J1.1, J2.1
unnamed: J1.2, J3.1
unnamed: J1.3, J2.2
unnamed: J1.4, J3.2
unnamed: J1.5, J2.3
unnamed: J1.6, J3.3
unnamed: J1.7, J2.4
unnamed: J1.8, J3.4
unnamed: J1.18, J3.9
unnamed: J1.19, J2.10
unnamed: J1.20, J3.10
unnamed: J1.21, J2.11
unnamed: J1.22, J3.11
unnamed: J1.23, J2.12
unnamed: J1.24, J3.12
unnamed: J1.25, J2.13
unnamed: J1.26, J3.13
unnamed: J1.27, J2.14
unnamed: J1.28, J3.14
unnamed: J1.29, J2.15
unnamed: J1.30, J3.15
unnamed: J1.31, J2.16
unnamed: J1.32, J3.16
unnamed: J1.33, J2.17
unnamed: J1.35, J2.18
unnamed: J1.36, J3.18
unnamed: J1.37, J2.19
unnamed: J1.38, J3.19
unnamed: J1.39, J2.20
unnamed: J1.40, J3.20
VCC: J1.9, J2.5


Board: 2 copper layers, 35.6 x 68.6 mm, 4 parts (0 on the bottom side), 40 nets.

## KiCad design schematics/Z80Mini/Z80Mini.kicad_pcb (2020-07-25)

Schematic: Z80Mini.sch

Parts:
C1, C2, C3, C5, C6, C7, C13, C19: 100nF; C_Disc_D7.0mm_W2.5mm_P5.00mm
C16: 10uF; CP_Radial_D5.0mm_P2.50mm
D3, D4: LED; LED_D3.0mm
J1: Conn_02x20_Odd_Even; Connector_CardEdge_40
J2: TTL Serial; PinHeader_1x06_P2.54mm_Vertical
Q1: BC337; TO-92_Inline
R2: 100K; R_Axial_DIN0207_L6.3mm_D2.5mm_P7.62mm_Horizontal
R3: 47K; R_Axial_DIN0207_L6.3mm_D2.5mm_P7.62mm_Horizontal
R4, R5, R6: 3.3K; R_Axial_DIN0207_L6.3mm_D2.5mm_P7.62mm_Horizontal
R10: R; R_Axial_DIN0207_L6.3mm_D2.5mm_P7.62mm_Horizontal
R15: 1K; R_Axial_DIN0207_L6.3mm_D2.5mm_P7.62mm_Horizontal
R16: 330R; R_Axial_DIN0207_L6.3mm_D2.5mm_P7.62mm_Horizontal
R17: 10K; R_Axial_DIN0207_L6.3mm_D2.5mm_P7.62mm_Horizontal
SW1: RESET; SW_PUSH_6mm_H5mm
U1: Z80CPU; DIP-40_W15.24mm_LongPads
U2: TC55257CPI; DIP-28_W15.24mm_LongPads
U3: 28C256; DIP-28_W15.24mm_LongPads
U4: NE555; DIP-8_W7.62mm_LongPads
U5: 74HC14; DIP-14_W7.62mm_LongPads
U6: 74LS139; DIP-16_W7.62mm_LongPads
X1: 4MHz; Oscillator_DIP-8

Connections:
+5V: C1.1, C2.2, C3.2, C5.2, C6.1, C7.2, C13.2, D4.2, J1.9, J2.1, R2.1, R3.1, R4.1, R5.1, R6.1, R10.2, R17.1, U1.11, U2.28 (VDD), U3.27, U3.28, U4.4, U4.8, U5.14, U6.16, X1.8; also elsewhere on the board
/A0: J1.19, U1.30, U2.10 (A0), U3.10; also elsewhere on the board
/A1: J1.20, U1.31, U2.9 (A1), U3.9; also elsewhere on the board
/A2: J1.21, U1.32, U2.8 (A2), U3.8; also elsewhere on the board
/A3: J1.22, U1.33, U2.7 (A3), U3.7
/A4: J1.23, U1.34, U2.6 (A4), U3.6, U6.2
/A5: J1.24, U1.35, U2.5 (A5), U3.5, U6.3
/A6: J1.25, U1.36, U2.4 (A6), U3.4
/A7: J1.26, U1.37, U2.3 (A7), U3.3
/A8: J1.27, U1.38, U2.25 (A8), U3.25
/A9: J1.28, U1.39, U2.24 (A9), U3.24
/A10: J1.29, U1.40, U2.21 (A10), U3.21
/A11: J1.30, U1.1, U2.23 (A11), U3.23
/A12: J1.31, U1.2, U2.2 (A12), U3.2
/A13: J1.37, U1.3, U2.26 (A13), U3.26
/A14: J1.38, U1.4, U2.1 (A14), U3.1
/A15: J1.39, U1.5, U6.14
/BUSACK: J1.32, U1.23
/BUSRQ: J1.35, R6.2, U1.25
/D0: J1.10, U1.14, U2.11 (I/O1), U3.11; also elsewhere on the board
/D1: J1.11, U1.15, U2.12 (I/O2), U3.12; also elsewhere on the board
/D2: J1.12, U1.12, U2.13 (I/O3), U3.13; also elsewhere on the board
/D3: J1.13, U1.8, U2.15 (I/O4), U3.15; also elsewhere on the board
/D4: J1.14, U1.7, U2.16 (I/O5), U3.16; also elsewhere on the board
/D5: J1.15, U1.9, U2.17 (I/O6), U3.17; also elsewhere on the board
/D6: J1.16, U1.10, U2.18 (I/O7), U3.18; also elsewhere on the board
/D7: J1.17, U1.13, U2.19 (I/O8), U3.19; also elsewhere on the board
/DSR: J2.5; also elsewhere on the board
/DTR: J2.3; also elsewhere on the board
/INT: J1.40, U1.16, U5.6
/IORQ: J1.6, U1.20, U6.1
/IO_UART/IO_CE: U6.4; also elsewhere on the board
/IO_UART/UART_CE: U6.5; also elsewhere on the board
/IO_UART/UART_INTR: U5.5; also elsewhere on the board
/M1: J1.7, U1.27
/OSC: U1.6, X1.5; also elsewhere on the board
/RESET: J1.5, R15.1, R17.2, U1.26, U5.2, U5.3
/RX: J2.6; also elsewhere on the board
/SND_SEL: J1.36, U6.7
/TX: J2.4; also elsewhere on the board
/VDP_SEL: J1.33, U6.6
GND: C1.2, C2.1, C3.1, C5.1, C6.2, C7.1, C13.1, C16.2, C19.2, D3.1, J1.34, J2.2, Q1.3, SW1.1, U1.29, U2.14 (GND), U3.14, U4.1, U5.7, U6.8, U6.13, X1.4; also elsewhere on the board
HALT: J1.3, U1.18
IO_RESET: U5.4; also elsewhere on the board
MREQ: J1.1, U1.19, U6.15
NMI: J1.2, R4.2, U1.17
unnamed: C16.1, R3.2, U4.6, U4.7
unnamed: C19.1, R2.2, SW1.2, U4.2
unnamed: D3.2, R10.1
unnamed: D4.1, R16.2
unnamed: Q1.1, R16.1
unnamed: Q1.2, R15.2
unnamed: U2.20 (/CE), U6.11
unnamed: U3.20, U6.12
unnamed: U4.3, U5.1
RD: J1.8, U1.21, U2.22 (/OE), U3.22; also elsewhere on the board
WAIT: J1.4, R5.2, U1.24
WR: J1.18, U1.22, U2.27 (R/W); also elsewhere on the board

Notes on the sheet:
Z80MiniFrame CPU and memory
2.0
08/06/2020

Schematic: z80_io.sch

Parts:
C4, C20: 0.1uF; C_Disc_D3.0mm_W1.6mm_P2.50mm
C8, C9, C15, C17: 100nF; C_Disc_D7.0mm_W2.5mm_P5.00mm
C10: 0.47uF; C_Disc_D3.0mm_W1.6mm_P2.50mm
C11, C12: 47pF; C_Disc_D3.0mm_W1.6mm_P2.50mm
C14: 10uF; CP_Radial_D5.0mm_P2.50mm
D1, D2: LED; LED_D3.0mm
FB1: 600Ohm; L_0805_2012Metric
J3: USB_B_Micro; USB_Mini-B_Lumberg_2486_01_Horizontal
J4: Conn_02x10_Counter_Clockwise; IDC-Header_2x10_P2.54mm_Horizontal
JP3: USB_VBUS; PinHeader_1x02_P2.54mm_Vertical
JP4: SELF_POWER; PinHeader_1x03_P2.54mm_Vertical
Q2: IRLML6402; SOT-23
R8, R9, R11, R12, R13, R14: R; R_Axial_DIN0207_L6.3mm_D2.5mm_P7.62mm_Horizontal
R18: 1K; R_Axial_DIN0207_L6.3mm_D2.5mm_P7.62mm_Horizontal
SW2: SW_DIP_x04; DIP-8_W7.62mm_LongPads
U7: 82C55A; DIP-40_W15.24mm_LongPads
U8: 16550; DIP-40_W15.24mm_LongPads
U9: FT232RL; SSOP-28_5.3x10.2mm_P0.65mm

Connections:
+5V: C8.2, C9.2, C17.2, J4.1, JP4.2, SW2.5, SW2.6, SW2.7, SW2.8, U7.26, U8.12, U8.13, U8.39, U8.40, U9.19; also elsewhere on the board
/A0: U7.9, U8.28; also elsewhere on the board
/A1: U7.8, U8.27; also elsewhere on the board
/A2: U8.26; also elsewhere on the board
/D0: U7.34, U8.1; also elsewhere on the board
/D1: U7.33, U8.2; also elsewhere on the board
/D2: U7.32, U8.3; also elsewhere on the board
/D3: U7.31, U8.4; also elsewhere on the board
/D4: U7.30, U8.5; also elsewhere on the board
/D5: U7.29, U8.6; also elsewhere on the board
/D6: U7.28, U8.7; also elsewhere on the board
/D7: U7.27, U8.8; also elsewhere on the board
/DSR: U8.37, U8.38, U9.2; also elsewhere on the board
/DTR: U8.33, U9.9, U9.10; also elsewhere on the board
/IO_UART/IO_CE: U7.6; also elsewhere on the board
/IO_UART/PA4: J4.14, U7.40
/IO_UART/PA5: J4.13, U7.39
/IO_UART/PA6: J4.12, U7.38
/IO_UART/PA7: J4.11, U7.37
/IO_UART/PB0: J4.20, U7.18
/IO_UART/PB1: J4.19, U7.19
/IO_UART/PB4: J4.18, U7.22
/IO_UART/PB5: J4.17, U7.23
/IO_UART/PB6: J4.16, U7.24
/IO_UART/PB7: J4.15, U7.25
/IO_UART/PC0: J4.2, U7.14
/IO_UART/PC1: J4.3, U7.15
/IO_UART/PC2: J4.4, U7.16
/IO_UART/PC3: J4.5, U7.17
/IO_UART/PC4: J4.6, U7.13
/IO_UART/PC5: J4.7, U7.12
/IO_UART/PC6: J4.8, U7.11
/IO_UART/PC7: J4.9, U7.10
/IO_UART/UART_CE: U8.14; also elsewhere on the board
/IO_UART/UART_INTR: U8.30; also elsewhere on the board
/OSC: U8.16; also elsewhere on the board
/RX: U8.10, U9.1; also elsewhere on the board
/TX: U8.11, U9.5; also elsewhere on the board
GND: C8.1, C9.1, C10.2, C11.1, C12.1, C14.2, C15.2, C17.1, C20.1, D1.1, D2.1, J3.5, J4.10, R11.2, R12.2, R13.2, R14.2, U7.7, U8.19, U8.20, U8.22, U8.25, U9.7, U9.18, U9.21, U9.25, U9.26; also elsewhere on the board
IO_RESET: U7.35, U8.35; also elsewhere on the board
unnamed: C4.1, Q2.1, R18.2
unnamed: C10.1, J3.6
unnamed: C11.2, J3.2, U9.16
unnamed: C12.2, J3.3, U9.15
unnamed: C14.1, FB1.2, JP3.1
unnamed: C15.1, U9.17
unnamed: C4.2, C20.2, JP4.1, Q2.3
unnamed: D1.2, R8.1
unnamed: D2.2, R9.1
unnamed: FB1.1, JP4.3, Q2.2, U9.4, U9.20
unnamed: J3.1, JP3.2
unnamed: R8.2, U7.20
unnamed: R9.2, U7.21
unnamed: R11.1, SW2.1, U7.4
unnamed: R12.1, SW2.2, U7.3
unnamed: R13.1, SW2.3, U7.2
unnamed: R14.1, SW2.4, U7.1
unnamed: R18.1, U9.14
unnamed: U8.9, U8.15
unnamed: U8.32, U9.11
unnamed: U8.36, U9.3
RD: U7.5, U8.21; also elsewhere on the board
WR: U7.36, U8.18; also elsewhere on the board

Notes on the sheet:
Mini Z80 IO Module
05/08/2019


Board: 2 copper layers, 194.3 x 105.4 mm, 64 parts (0 on the bottom side), 97 nets.

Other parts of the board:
REF1, REF2, REF3, REF4: MountingHole_3.2mm_M3_DIN965_Pad

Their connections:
GND: REF2.4, REF4.3; also elsewhere on the board

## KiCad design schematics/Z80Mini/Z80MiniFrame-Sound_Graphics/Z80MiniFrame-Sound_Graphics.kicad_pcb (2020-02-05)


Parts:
J1: Conn_02x20_Odd_Even; Connector_CardEdge_40
JP3: Jumper_NC_Dual; PinHeader_1x03_P2.54mm_Vertical

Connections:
/D0: J1.10; also elsewhere on the board
/D1: J1.11; also elsewhere on the board
/D2: J1.12; also elsewhere on the board
/D3: J1.13; also elsewhere on the board
/D4: J1.14; also elsewhere on the board
/D5: J1.15; also elsewhere on the board
/D6: J1.16; also elsewhere on the board
/D7: J1.17; also elsewhere on the board
/graphicsProcessor/A0: J1.19; also elsewhere on the board
/graphicsProcessor/INT: JP3.2; also elsewhere on the board
/graphicsProcessor/IORQ: J1.6; also elsewhere on the board
/graphicsProcessor/RD: J1.8; also elsewhere on the board
/graphicsProcessor/RESET: J1.5; also elsewhere on the board
/graphicsProcessor/VD_SEL: J1.33; also elsewhere on the board
/graphicsProcessor/WR: J1.18; also elsewhere on the board
/soundGeneration/SND_SEL: J1.36; also elsewhere on the board
GND: J1.34; also elsewhere on the board
unnamed: J1.2, JP3.3
unnamed: J1.40, JP3.1
VCC: J1.9; also elsewhere on the board


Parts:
C8, C9, C10, C11, C12, C13, C19, C22: 100nF; C_Disc_D7.0mm_W2.5mm_P5.00mm
C16: 33pf; C_Disc_D7.0mm_W2.5mm_P5.00mm
C17: 33pF; C_Disc_D7.0mm_W2.5mm_P5.00mm
C18: 220uF; CP_Radial_Tantal_D6.0mm_P2.50mm
CV1: 5-50pF; Potentiometer_ACP_CA9-V10_Vertical
D1: 1N4148; D_DO-35_SOD27_P7.62mm_Horizontal
J2: COMP_VIDEOUT; RCA_Female_902
J5: COMP_VIDEOIN; RCA_Female_902
Q1: 2N3904; TO-92_Inline
R10, R12: 75R; R_Axial_DIN0207_L6.3mm_D2.5mm_P10.16mm_Horizontal
R11: 470R; R_Axial_DIN0207_L6.3mm_D2.5mm_P10.16mm_Horizontal
U1: TMS9918A; DIP-40_W15.24mm_LongPads
U2, U3, U4: 74LS574; DIP-20_W7.62mm_Socket_LongPads
U5: AS6C62256-55PCN; DIP-28_W15.24mm_LongPads; Manufacturer_Part_Number AS6C62256-55PCN; Mouser Part Number 913-AS6C62256-55PCN
U6: 74HC04; DIP-14_W7.62mm_Socket_LongPads
U12: 74LS32; DIP-14_W7.62mm_LongPads
Y1: 10.73MHz; Crystal_HC18-U_Vertical

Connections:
/D0: U1.17 (CD7); also elsewhere on the board
/D1: U1.18 (CD6); also elsewhere on the board
/D2: U1.19 (CD5); also elsewhere on the board
/D3: U1.20 (CD4); also elsewhere on the board
/D4: U1.21 (CD3); also elsewhere on the board
/D5: U1.22 (CD2); also elsewhere on the board
/D6: U1.23 (CD1); also elsewhere on the board
/D7: U1.24 (CD0); also elsewhere on the board
/graphicsProcessor/A0: U1.13 (MODE); also elsewhere on the board
/graphicsProcessor/AD0: U1.10 (AD0), U2.2 (D0), U3.2 (D0), U4.2 (D0)
/graphicsProcessor/AD1: U1.9 (AD1), U2.3 (D1), U3.3 (D1), U4.3 (D1)
/graphicsProcessor/AD2: U1.8 (AD2), U2.4 (D2), U3.4 (D2), U4.4 (D2)
/graphicsProcessor/AD3: U1.7 (AD3), U2.5 (D3), U3.5 (D3), U4.5 (D3)
/graphicsProcessor/AD4: U1.6 (AD4), U2.6 (D4), U3.6 (D4), U4.6 (D4)
/graphicsProcessor/AD5: U1.5 (AD5), U2.7 (D5), U3.7 (D5), U4.7 (D5)
/graphicsProcessor/AD6: U1.4 (AD6), U2.8 (D6), U3.8 (D6), U4.8 (D6)
/graphicsProcessor/AD7: U1.3 (AD7), U2.9 (D7), U3.9 (D7), U4.9 (D7)
/graphicsProcessor/COMVID: Q1.2 (B), R11.1, U1.36 (COMVID); also elsewhere on the board
/graphicsProcessor/CPUCLK: U1.38 (CPUCLK); also elsewhere on the board
/graphicsProcessor/EXTV: J5.1 (In), U1.35 (EXTV); also elsewhere on the board
/graphicsProcessor/INT: D1.2 (A); also elsewhere on the board
/graphicsProcessor/IORQ: U12.2; also elsewhere on the board
/graphicsProcessor/RD: U12.5; also elsewhere on the board
/graphicsProcessor/RESET: U1.34 (RESET/SYNC); also elsewhere on the board
/graphicsProcessor/VA0: U2.18 (Q1), U5.10 (A0)
/graphicsProcessor/VA1: U2.17 (Q2), U5.9 (A1)
/graphicsProcessor/VA2: U2.16 (Q3), U5.8 (A2)
/graphicsProcessor/VA3: U2.15 (Q4), U5.7 (A3)
/graphicsProcessor/VA4: U2.14 (Q5), U5.21 (A10)
/graphicsProcessor/VA5: U2.13 (Q6), U5.6 (A4)
/graphicsProcessor/VA6: U2.12 (Q7), U5.5 (A5)
/graphicsProcessor/VA7: U3.18 (Q1), U5.23 (A11)
/graphicsProcessor/VA8: U3.17 (Q2), U5.4 (A6)
/graphicsProcessor/VA9: U3.16 (Q3), U5.3 (A7)
/graphicsProcessor/VA10: U3.15 (Q4), U5.24 (A9)
/graphicsProcessor/VA11: U3.14 (Q5), U5.2 (A12)
/graphicsProcessor/VA12: U3.13 (Q6), U5.25 (A8)
/graphicsProcessor/VA13: U3.12 (Q7), U5.26 (A13)
/graphicsProcessor/VD0: U1.32 (RD0), U4.19 (Q0), U5.11 (DQ0)
/graphicsProcessor/VD1: U1.31 (RD1), U4.18 (Q1), U5.12 (DQ1)
/graphicsProcessor/VD2: U1.30 (RD2), U4.17 (Q2), U5.13 (DQ2)
/graphicsProcessor/VD3: U1.29 (RD3), U4.16 (Q3), U5.15 (DQ3)
/graphicsProcessor/VD4: U1.28 (RD4), U4.15 (Q4), U5.16 (DQ4)
/graphicsProcessor/VD5: U1.27 (RD5), U4.14 (Q5), U5.17 (DQ5)
/graphicsProcessor/VD6: U1.26 (RD6), U4.13 (Q6), U5.18 (DQ6)
/graphicsProcessor/VD7: U1.25 (RD7), U4.12 (Q7), U5.19 (DQ7)
/graphicsProcessor/VD_SEL: U12.1; also elsewhere on the board
/graphicsProcessor/WR: U12.10; also elsewhere on the board
GND: C8.2, C9.2, C10.1, C11.1, C12.1, C13.1, C16.1, C17.1, C19.1, C22.1, CV1.1, J2.2 (Ext), J5.2 (Ext), R10.2, R11.2, U1.12 (VSS), U2.1 (OE), U2.10 (GND), U3.1 (OE), U3.10 (GND), U4.10 (GND), U5.1 (A14), U5.14 (VSS), U6.7 (GND), U12.7 (GND); also elsewhere on the board
unnamed: C16.2, CV1.2, U1.39 (XTAL2), Y1.2
unnamed: C17.2, U1.40 (XTAL1), Y1.1
unnamed: C18.1, R12.1
unnamed: C18.2, J2.1 (In)
unnamed: D1.1 (K), U1.16 (/INT)
unnamed: Q1.1 (E), R10.1, R12.2
unnamed: U1.1 (/RAS), U6.1
unnamed: U1.2 (/CAS), U5.20 (CE#), U6.9
unnamed: U1.11 (R/W), U4.1 (OE), U5.27 (WE#), U6.11
unnamed: U1.14 (/CSW), U12.8
unnamed: U1.15 (/CSR), U12.6
unnamed: U2.11 (Cp), U6.2
unnamed: U3.11 (Cp), U6.6
unnamed: U4.11 (Cp), U5.22 (OE#), U6.10
unnamed: U6.3, U6.8
unnamed: U6.4, U6.5
unnamed: U12.3, U12.4, U12.9
VCC: C8.1, C9.1, C10.2, C11.2, C12.2, C13.2, C19.2, C22.2, Q1.3 (C), U1.33 (VCC), U2.20 (VCC), U3.20 (VCC), U4.20 (VCC), U5.28 (VCC), U6.14 (VCC), U12.14 (VCC); also elsewhere on the board


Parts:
C1, C14: 100nF; C_Disc_D7.0mm_W2.5mm_P5.00mm
C2: 300pF; C_Disc_D5.0mm_W2.5mm_P5.00mm
C3: 2uF; C_Disc_D5.0mm_W2.5mm_P5.00mm
C4: 10uF; CP_Radial_D5.0mm_P2.00mm
C5: 0.1uF; C_Disc_D7.0mm_W2.5mm_P5.00mm
C6: 250uF; CP_Radial_D6.3mm_P2.50mm
C7: 0.05uF; C_Disc_D5.0mm_W2.5mm_P5.00mm
J3: Conn_01x03_Male; PinHeader_1x03_P2.54mm_Vertical
J4: IO_PORT; IDC-Header_2x10_P2.54mm_Vertical
JP1: PREAMP_MONO; PinHeader_2x03_P2.54mm_Vertical
JP4: Jumper_NC_Dual; PinHeader_1x03_P2.54mm_Vertical
R1: 1K; R_Axial_DIN0207_L6.3mm_D2.5mm_P10.16mm_Horizontal
R2: 5K; R_Axial_DIN0207_L6.3mm_D2.5mm_P10.16mm_Horizontal
R3: 500; R_Axial_DIN0207_L6.3mm_D2.5mm_P10.16mm_Horizontal
R4: 10; R_Axial_DIN0207_L6.3mm_D2.5mm_P10.16mm_Horizontal
SPEAKER1: Conn_01x02_Male; PinHeader_1x02_P2.54mm_Vertical
U7: AY-3-8910; DIP-40_W15.24mm_LongPads
U8: 74LS02; DIP-14_W7.62mm_Socket_LongPads
U9: LM386; DIP-8_W7.62mm_LongPads
X1: ACO-2MHz; Oscillator_DIP-14

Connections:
/D0: U7.37 (DA0); also elsewhere on the board
/D1: U7.36 (DA1); also elsewhere on the board
/D2: U7.35 (DA2); also elsewhere on the board
/D3: U7.34 (DA3); also elsewhere on the board
/D4: U7.33 (DA4); also elsewhere on the board
/D5: U7.32 (DA5); also elsewhere on the board
/D6: U7.31 (DA6); also elsewhere on the board
/D7: U7.30 (DA7); also elsewhere on the board
/graphicsProcessor/A0: U8.2; also elsewhere on the board
/graphicsProcessor/COMVID: J4.19; also elsewhere on the board
/graphicsProcessor/CPUCLK: JP4.1; also elsewhere on the board
/graphicsProcessor/EXTV: J4.20; also elsewhere on the board
/graphicsProcessor/RESET: U7.23 (/RESET); also elsewhere on the board
/soundGeneration/SND_SEL: U8.3, U8.5, U8.6; also elsewhere on the board
GND: C1.2, C2.2, C4.2, C5.2, C14.1, J4.18, R1.1, R3.1, R4.1, SPEAKER1.1, U7.1 (VSS), U7.24 (A9), U8.7 (GND), U9.2 (-), U9.4 (GND), X1.7 (GND); also elsewhere on the board
unnamed: C2.1, C3.2, R2.1, R3.2
unnamed: C3.1, U9.3 (+)
unnamed: C6.1, C7.1, U9.5
unnamed: C6.2, SPEAKER1.2
unnamed: C7.2, R4.2
unnamed: J3.1, JP1.2, U7.38 (ACH_C)
unnamed: J3.2, JP1.4, U7.3 (ACH_B)
unnamed: J3.3, JP1.6, U7.4 (ACH_A)
unnamed: J4.1, U7.21 (IOA0)
unnamed: J4.2, U7.13 (IOB0)
unnamed: J4.3, U7.20 (IOA1)
unnamed: J4.4, U7.12 (IOB1)
unnamed: J4.5, U7.19 (IOA2)
unnamed: J4.6, U7.11 (IOB2)
unnamed: J4.7, U7.18 (IOA3)
unnamed: J4.8, U7.10 (IOB3)
unnamed: J4.9, U7.17 (IOA4)
unnamed: J4.10, U7.9 (IOB4)
unnamed: J4.11, U7.16 (IOA5)
unnamed: J4.12, U7.8 (IOB5)
unnamed: J4.13, U7.15 (IOA6)
unnamed: J4.14, U7.7 (IOB6)
unnamed: J4.15, U7.14 (IOA7)
unnamed: J4.16, U7.6 (IOB7)
unnamed: JP1.1, JP1.3, JP1.5, R1.2, R2.2
unnamed: JP4.2, U7.22 (CLK)
unnamed: JP4.3, X1.8 (OUT)
unnamed: U7.27 (BDIR), U8.4
unnamed: U7.29 (BC1), U8.1
VCC: C1.1, C4.1, C5.1, C14.2, J4.17, U7.25 (A8), U7.28 (BC2), U7.40 (VCC), U8.14 (VCC), U9.6 (V+), X1.14 (Vcc); also elsewhere on the board


Board: 2 copper layers, 194.3 x 105.4 mm, 50 parts (0 on the bottom side), 99 nets.

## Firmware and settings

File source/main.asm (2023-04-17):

;;******************************************************************
;; Firmware main code
;; Tomeu Capó 2022     
;;                
;; Code and computer schematics are released under
;; the therms of the GNU GPL License 3.0 and in the form of "as is", without no
;; kind of warranty: you can use them at your own risk.
;; You are free to use them for any non-commercial use: you are only asked to
;; maintain the copyright notices, include this advice and the note to the 
;; attribution of the original version to Tomeu Capó, if you intend to
;; redistribuite them.
;;******************************************************************

include "globals.inc"
include "ppi.inc"
include "svcroutine.inc"

                extern SVC_ROUTINE
                extern UART_INIT, UART_READ 
                
                extern PPI_INIT, PPI_GETSWSTATE, PPI_LED_BLINK
                extern PIT_INIT, PIT_RESET
                extern PSG_INIT, CHIMPSOUND
                extern VDP_INIT, BUFF_PUTC, KB_KEYSCAN

                extern CON_PRINT, CON_PUTC, CON_CKINCHAR, CON_GETCHAR
                extern MON_WELCOM, BASIC_INIT, MON_MAIN
               

                .ORG $0000
                DI                       ;Disable interrupts
                JP       INIT            ;Initialize Hardware and go

;------------------------------------------------------------------------------
; Put character to output

                .ORG     $0008
                JP       CON_PUTC
                      
;------------------------------------------------------------------------------
; Get character for buffer if is available

                .ORG    $0010
                JP      CON_GETCHAR

;------------------------------------------------------------------------------
; Check if any character into buffer are available

                .ORG    $0018
                JP      CON_CKINCHAR 

;------------------------------------------------------------------------------
; Firmware service routine dispatcher

                .ORG    $0020
                DI 

                PUSH     AF
                PUSH     HL
                
                CALL     SVC_ROUTINE
                
                POP      HL
                POP      AF
                
                EI
                RETI            

;------------------------------------------------------------------------------
; Interrupt mode 1 routine

                ifndef IM_2
                .ORG   $0038            
                JP     INT_HND_UART
                endif

;------------------------------------------------------------------------------
; NMI Interrupt routine

                .ORG    $0066
                EI
                RETN                
              
                .ORG    $0170
                defw    INT_HND_USR4        ; $70
                defw    INT_HND_USR3        ; $72
                defw    INT_HND_USR2        ; $74
                defw    INT_HND_USR1        ; $76 
                defw    INT_HND_EXT1        ; $78
                defw    INT_HND_VDP         ; $7A
                defw    INT_HND_UART        ; $7C
                defw    INT_HND_PIT         ; $7E
                
;------------------------------------------------------------------------------
; Main code

INIT::            
               LD       HL,TEMPSTACK           ; Set up a temporary stack
               LD       SP,HL               
                                           
               CALL	    PPI_INIT               ; Initialize PPI
               CALL     PPI_GETSWSTATE         ; Get dipswitches configuration for UART speed
               
               LD      A, 1
               OUT     (LED_PORT), A

               LD        H, 0   
               LD	     L, C
               CALL      UART_INIT              ; Initialize UART at C speed
              
               ifdef    IM_2         
                   IM   2                       ; Interrupt mode 2
                   ld   a, 1                    
                   ld   I, A                    ; Set high byte of interrupt vectors to point to page 0                   
               else
                   IM   1                       ; Interrupt mode 1
               endif

               LD      A, 2
               OUT     (LED_PORT), A

            ;    LD        A, B
            ;    LD        (ENABLECTC), A         ; Check if starts without VDP, CTC and PSG
            ;    CP        0
            ;    JR        Z, ONLY_CORE

            ;    LD      A, 3
            ;    OUT     (LED_PORT), A

               ifndef    VDP_DISABLE
               LD        E, 0                   ; VDP Set video text mode
               CALL      VDP_INIT 
               endif
            
               ifndef    PSG_DISABLE               
               CALL      PSG_INIT               ; Initialize PSG
               CALL      CHIMPSOUND             ; Welcome sound
               endif
             
               CALL      PIT_INIT               ; Initialize PIT
               CALL      PPI_LED_BLINK          ; PPI LED Hello world welcome
                        
               xor  A
               ld   (TMRCNT), A                

               LD   A, 1
               LD   (CURSORSTATE), A   
                
               CALL      PPI_LED_BLINK          ; PPI LED Hello world welcome                               
               CALL      MON_WELCOM      

               EI

               LD        A, 'N'
               LD        (basicStarted),A        
               CALL      BASIC_INIT
                 
;;-----------------------------------------------------------------------------
;; Interrupt handler routines

                .ORG    $0200
                
INT_HND_UART:  DI
               EX AF, AF'
               EXX

		       CALL	 UART_READ

               EXX
               EX AF, AF'     
               EI
               RETI

INT_HND_PIT:   DI
               ; Reset counter

               CALL PIT_RESET

               PUSH AF
               PUSH BC

               LD      A, (ENABLEDCURSOR)
               OUT     (LED_PORT), A
               CPL
               LD      (ENABLEDCURSOR), A       

;                ld      HL,TMRCNT       ; load starting address of the timer
;                ld      B,$04           ; 4 bytes to check
; INCTMR3:       inc     (HL)            ; increment timer
;                jr      NZ,EXIT_INT     ; if not zero then exit (finished increment)
;                inc     HL              ; if yes, there was an overflow, so increment next byte
;                djnz    INCTMR3         ; repeat for 4 bytes
; EXIT_INT:                 
               POP     BC
               POP     AF

               EI
               RETI            

INT_HND_VDP:  
INT_HND_EXT1:  
INT_HND_USR1:                
INT_HND_USR2:
INT_HND_USR3:
INT_HND_USR4:   EI
                RETI


HELLOWORLD:
               LD        HL,UEPMSG    
               CALL      CON_PRINT          
               HALT
               RET     

UEPMSG:       .BYTE   "UEP, COM ANAN?",CR,LF,0

CTCENABLEDMSG:  .BYTE    "PIT Enabled", CR,LF,0
UARTENABLEDMSG: .BYTE   "UART Enabled", CR,LF,0

               .end

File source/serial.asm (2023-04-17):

;;
;; serial.asm
;; Tomeu Capó
;;
;; Code and computer schematics are released under
;; the therms of the GNU GPL License 3.0 and in the form of "as is", without no
;; kind of warranty: you can use them at your own risk.
;; You are free to use them for any non-commercial use: you are only asked to
;; maintain the copyright notices, include this advice and the note to the 
;; attribution of the original version to Tomeu Capó, if you intend to
;; redistribuite them.
;;

include "serial.inc"

    extern BUFF_INIT, BUFF_PUTC, BUFF_GETC

; UART_INIT - Initialize UART serial IC
;   L = Serial speed

UART_INIT:: 
    LD      A,80H
    OUT     (UART3),A           ; SET DLAB FLAG (LINE CONTROL)

    LD		DE, BAUDTABLE
    ADD     HL, DE
    LD      A,(HL)        
    OUT     (UART0),A            ; Set BAUD rate

    LD      A,00H
    OUT     (UART1),A            ; CHECK RX
    LD      A,03H
    OUT     (UART3),A            ; LINE CONTROL
    LD      A,$01
    OUT     (UART1),A            ; Enable receive data available interrupt only

    CALL    BUFF_INIT

    RET

; UART_READ - Read character if available and put into buffer
;   Return last readed character into register A

UART_READ::		
    IN		 A,(UART5)    	 ;Fetch the control register
	BIT 	 0,A
    RET      Z

    IN       A,(UART0)
    CALL     BUFF_PUTC       ; Put received character to input buffer
    RET

UART_TX_RDY:    
    PUSH 	AF
UART_TX_RDY_LP:	
    IN		A,(UART5)    	;Fetch the control register
	BIT 	5,A            	;Bit will be set if UART is ready to send
	JP		Z,UART_TX_RDY_LP		
	POP     AF
	RET

UART_WRITE::
    CALL  UART_TX_RDY
    OUT   (UART0),A
    RET

UART_GETCHAR::
    CALL BUFF_GETC          ; Get latest character from input buffer
	RET 





; Baud lookup table based on SW connected to PA0..3 port
			 
BAUDTABLE:      .BYTE	 208		; 1200
                .BYTE	 104		; 2400
                .BYTE	 26		    ; 9600
                .BYTE	 13			; 19200

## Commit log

2019-08-31 Added AY-3-8910 simple routine
    [Z80Mini.sch, z80_io.sch]
2019-09-03 Added new schematics for graphics and sound card
    [AS6C62256-55PCN.stl, AS6C62256-55PCN.stp, EDI2CAP.CFG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]
2019-09-05 Latest graphics and sound card schematic and PCB modifications
    [Z80MiniFrame-Sound_Graphics.kicad_pcb, graphicsProcessor.sch, sound.sch]
2019-09-10 Latest modifications on Graphics-Sound card
    [RYBYRGB.sch, Z80MiniFrame-Sound_Graphics.kicad_pcb, Z80MiniFrame-Sound_Graphics.sch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]
2019-10-19 Latest modifications
    [Z80MiniFrame-Sound_Graphics.kicad_pcb, Z80MiniFrame-Sound_Graphics.sch, graphicsProcessor.sch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]
2019-12-12 Latest modifications and update to v1.1 and first successifully VDP routines test.
    [Z80Mini-B_Cu.gbr, Z80Mini-B_Mask.gbr, Z80Mini-B_Paste.gbr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]
2019-12-29 Added new code for core written in C with Z88DK
    [Z80Backplane.kicad_pcb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]
2020-02-05 Testing C routines for VDP and keyboard. Generated backplane gerber files
    [Z80Backplane.kicad_pcb, Z80Backplane.sch, Z80Mini.kicad_pcb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]
2020-07-04 Latest changes on vdp routines and bas32k added new COLOR instruction
    [Z80Mini.kicad_pcb, Z80Mini.sch, z80_io.sch]
2020-07-18 Latest changes
    [Z80Mini-B_Cu.gbr, Z80Mini-B_Mask.gbr, Z80Mini-B_Paste.gbr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]
2020-07-25 Created new schematic for TTLSerial to USB, I2C and RS232
    [Z80Mini.kicad_pcb, Z80Mini.sch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]
2020-07-26 Add schematics PDF format
2020-08-12 Latest changes and added CTC initialization and routine to flash cursor
    [Z80Backplane.kicad_pcb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]
2020-09-24 Latest code changes and modified Makefile to support burn to EPROM Emulator
    [Z80Backplane.kicad_pcb, Z80Backplane.sch, Z80MiniFrame-Sound_Graphics.sch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]
2021-12-23 Latest changes on reserved word tokens bugfixes
    [serialadapter.sch]
2022-05-29 Create driver to read keyboard
2022-05-30 Testing and developing keyboard driver
2022-06-02 Change keyboard driver to use PSG IO to scan keyboard matrix
2022-06-04 Improvement of keyboard driver, creating SHIFT key pressing processing (lower and uppercase)
2022-06-12 Put license terms of parts of code that owners is Leonardo Milliani
2022-06-24 Latest code changes and created new module to emulate interrupt mode 2 with vector interrupts
2022-06-24 Changed some parts of code and added new hardware module to emulate IM 2 and vector interrpt without Z80 dasy chain
    [Z80Mini.sch, int_manager.sch, z80_io.sch]
2022-07-15 Added code to save BASIC program to casette tape with 6-bit DAC and FSK modulation
    [casette_interface.kicad_pcb, casette_interface.sch]
2022-08-03 Added new schematics for all-in-one microcomputer board
    [Z80AllInOne-B_Cu.gbr, Z80AllInOne-B_Mask.gbr, Z80AllInOne-B_Paste.gbr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]
2022-08-03 Latest all in one PCB improvements
    [Z80AllInOne-B_Cu.gbr, Z80AllInOne-B_Mask.gbr, Z80AllInOne-B_Paste.gbr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]
2022-08-06 Latest modifications of All-in-one PCB
    [Z80AllInOne-B_Cu.gbr, Z80AllInOne-B_Mask.gbr, Z80AllInOne-B_Paste.gbr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]
2022-08-30 Latest changes for adapt source to support Z80AllInOne adding some macros and latest schematic improvements
    [Z80AllInOne-B_Cu.gbr, Z80AllInOne-B_Mask.gbr, Z80AllInOne-B_Paste.gbr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]
2022-09-01 Latest code and schematic updates. Changed IDE connector to 2.54mm IDE connector
    [Z80AllInOne.kicad_pcb, Z80AllInOne.kicad_sch, casette_interface.kicad_sch]
2022-09-29 Added IM 2 based routines software support
    [Z80AllInOne.kicad_sch, int_manager.kicad_sch]
2023-01-14 Latest changes and replace CTC for 8253 PIT
    [Z80AllInOne-B_Cu.gbr, Z80AllInOne-B_Mask.gbr, Z80AllInOne-B_Paste.gbr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]
2023-04-17 Created new macro for LOADCNT PIT counter reset and removed old CTC routines that not used.
    [Z80AllInOne.kicad_sch, psg.kicad_sch]
